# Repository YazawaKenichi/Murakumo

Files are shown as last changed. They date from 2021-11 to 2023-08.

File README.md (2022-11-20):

# Murakumo

```
* 8b    d8 88   88 88""Yb    db    88  dP 88   88 8b    d8  dP"Yb             Yb    dP 888888 *
* 88b  d88 88   88 88__dP   dPYb   88odP  88   88 88b  d88 dP   Yb             Yb  dP  88oo." *
* 88YbdP88 Y8   8P 88"Yb   dP__Yb  88"Yb  Y8   8P 88YbdP88 Yb   dP              YbdP      `8b *
* 88 YY 88 `YbodP' 88  Yb dP""""Yb 88  Yb `YbodP' 88 YY 88  YbodP  oooooooooo    YP    8888P' *
```

Yazawa の初めてのロボトレの情報を置いておくリポジトリ。
##### Excel フォルダ
機体の仕様決定

##### Inventor フォルダ
具体的な機体のグラフィック

##### Circuit フォルダ
KiCAD データとガーバーデータ

##### Program フォルダ（未作成）
実行プログラムや試行錯誤したプログラム

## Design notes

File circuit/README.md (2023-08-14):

回路設計時のノート

いろいろ悩みそうなところだけど、どこから悩めばいいのかもわからなかったので、まずはモータドライバ回路から設計しようと思う。

モータドライバ設計の前に、H ブリッジを駆動するためのゲートドライバ選びについて記述する。
##### ゲートドライバ
まず、ゲートドライバに必要な要素は以下の通り。
- Nch フルブリッジ回路を組むことができるか？
- 100% duty で出力できるか？
ということらしい。

PWM 周波数の話。
PWM 周波数は小さすぎるとトルクが足りなくなり、大きすぎるとモータによるサージの影響を受けやすくなる。よって適度な周波数に決める必要がある。

###### Nch フルブリッジ回路
Nch フルブリッジ回路を組むことの利点は以下。
- Pch は Nch に比べて性能が低い。
- Pch は品種があまりない。
- パワー素子は一種類のみで済ませて手間を省きたい。（Pch か Nch にそろえて同じ素子を使って製作できるようにしたい。）
- Pch は値段が高い。
上記理由を先輩に教えていただいたが、教えていただいた後にネットを探したところ、同様の記述を発見した。[参考](http://blog.livedoor.jp/wata_net/archives/2147292.html)。
[こっちのサイト](https://qiita.com/panzakii/items/97eca16954d34ecf0c8b)には「なぜフルNchにこだわるかというと、単純にその方が流せる電流が大きくなるからです。実はPchFETはNchFETに比べ流せる電流が少ないのです。原理について説明しだすと本当にキリがないので説明しません。興味のある人はググってください。」などと記述されているが、ググってもそんな記述は一切出てこない。なんなんだ。

「品種が多いから Pch よりも大電流の流せる Nch MOSFET」ならわかるが、「原理」とか「説明しだすとキリがない」とか記述されているのは本当に意味が分からない。

###### 100% duty で出力
- 最大出力で出せたほうが良いにきまっとるやろ！

二つのメリットをカバーできて、より入手しやすい IC が A3921 だそうで、それが理由でよく利用される。

##### モータドライバ
ゲートドライバが決まったところで、次に使用する FET とそれにつながる制限抵抗やコンデンサの値を決める必要がある。
特にこの抵抗とコンデンサは真剣に決めないとショートしてリポが死ぬ。マジで。
モータに入る電流は最大でも 4.34A なので、この許容電流に耐えうるケーブルは AWG22 になる。（AWG23 がいい感じに 4.7A の許容電流なのだが、9号館にないのでしょうがない。）
この AWG23 を圧着できるコネクタが XA コネクタなので、モータの電流が通るところのコネクタはすべて XA にしようと思う。
電源コネクタと電源回路をモータドライバ回路の方に設置することで、わざわざマイコン側から電力をモータドライバ回路に送る必要を無くす。

***書き途中***

DRV8874 のデータシートを読んで得た情報
- CPH CPL 間に 22nF のコンデンサ
- nFault は故障で LOW nSleep は LOW でスリープ => nFault と nSleep を直結すると故障と同時にスリープに入る。
- nFault には外部プルアップが必要。

SR ピンは 1 にすると FET 経由で回生する

SR ピンを 0 にするとダイオード経由で回生する

Figure 2: Fast Decay Power Bridge Current Paths が一番創造に近いモータドライバの制御に近い

PWMH PWML には常に 1 を入れて、PHASE に 

##### CPU
先輩が STM32F405RGT6 を束買いしているので、とりあえずこれにするのはアリ。
クロック数とメモリと機能的に、ロボトレにいい塩梅で使えそうなのがこの CPU らしい。

***書き途中***

##### 電源回路
この電源回路を決めるのにレギュレータを選ぶ必要があるのだが、レギュレータの出力が決まらない以上は手の付けようがない。だからさっさとほかの回路作れ。電源選びは最後だ。
=======
回路設計時のノート

いろいろ悩みそうなところだけど、どこから悩めばいいのかもわからなかったので、まずはモータドライバ回路から設計しようと思う。

使いたいモータがある -> 必要な電流量に耐える FET -> それを駆動できるゲートドライバを探す<br>
使いたいセンサがある -> 

モータドライバ設計の前に、H ブリッジを駆動するためのゲートドライバ選びについて記述する。
##### ゲートドライバ
まず、ゲートドライバに必要な要素は以下の通り。
- Nch フルブリッジ回路を組むことができるか？
- 100% duty で出力できるか？
ということらしい。

###### Nch フルブリッジ回路
Nch フルブリッジ回路を組むことの利点は以下。
- Pch は Nch に比べて性能が低い。
- Pch は品種があまりない。
- パワー素子は一種類のみで済ませて手間を省きたい。（Pch か Nch にそろえて同じ素子を使って製作できるようにしたい。）
- Pch は値段が高い。
上記理由を先輩に教えていただいたが、教えていただいた後にネットを探したところ、同様の記述を発見した。[参考](http://blog.livedoor.jp/wata_net/archives/2147292.html)。
[こっちのサイト](https://qiita.com/panzakii/items/97eca16954d34ecf0c8b)には「なぜフルNchにこだわるかというと、単純にその方が流せる電流が大きくなるからです。実はPchFETはNchFETに比べ流せる電流が少ないのです。原理について説明しだすと本当にキリがないので説明しません。興味のある人はググってください。」などと記述されているが、ググってもそんな記述は一切出てこない。なんなんだ。

「品種が多いから Pch よりも大電流の流せる Nch MOSFET」ならわかるが、「原理」とか「説明しだすとキリがない」とか記述されているのは本当に意味が分からない。

###### 100% duty で出力
- 最大出力で出せたほうが良いにきまっとるやろ！
100% duty で出せるかどうかってどうやって決まるんだろう...

二つのメリットをカバーできて、より入手しやすい IC が A3921 だそうで、それが理由でよく利用される。
A3921 の仕様
ゲート電圧は基準電位から +15V 以内の範囲が出力される様子。具体的には、ハイサイド出力が SA の電位よりも 0 ~ 15V 高くなり、ローサイド出力が GND 電位よりも -5 ~ 16V 高くなるように出力される。

A3921 のデータシートを読んで得た情報
- GHA and GHB Pins
- ゲート抵抗はできるだけ FET に近いところに置く必要がある。（なんでや）
- ＞ そもそもゲート抵抗をつける理由として
- ＞＞ FET 内部のコンデンサ成分と、導線自体によるインダクタンス成分が共振し、それに影響して FET やマイコンが破損する恐れがある。
- ＞＞ ドレイン電圧の立ち上がりと立下りが早すぎてノイズへの影響が大きくなる。
- ＞＞ ゲート電流が大きすぎて FET 前段の制御回路が破損する。
- ＞ この中で FET と抵抗の距離と関係がありそうな理由としては「導線自体のインダクタンス」だろう。抵抗からFETまでの導線の長さを小さくする、すなわちインダクタンスを小さくすることでノイズを軽減するといったところか。
- いまいちよくわからないところが、「GHx going low turns on the lower half of the drive, sinking current from the external FET gate circuit to the corresponding Sx pin, turning off the FET.」の一文で、GHx を Low にしたらドライブの下半分が ON になる？ってどういうことだ？
- Bootstrap Capacitor Selection
- ブートストラップコンデンサ CBOOTx は、正しく選択する必要がある。
- コンデンサの静電容量が大きいと、コンデンサの充電に時間が浪費され、結果として最大デューティーサイクルと PWM 周波数の制限が小さくなってしまう。
- 逆に小さいと、Charge Sharing によって、電荷が CBOOTx から FET ゲートに転送されるときに大きな電圧降下が発生する可能性があるらしい。
- ＞ Charge Sharing ってなんだ？
- ＞＞ 英語版 Wiki によると、Charge Sharing は、ある電子ドメインからほかの電子ドメインへの電荷の移動による信号劣化の影響。らしい。は？
- ＞ よくわからないけど、とにかく電荷を共有して、出力電圧レベルが退化したり、誤った出力値が発生したりする可能性があるっぽい。
- この電圧降下を小さくするために、CBOOTx の電荷 QBOOT は、FET のゲート QGATE に必要な電荷よりもはるかに大きくする必要がある。その"はるかに大きい"というのは、20 倍だそうだ。
- QBOOT というのは、CBOOTx に蓄えられる電気量なので、CBOOT * VBOOT で求めることができる。そして上記より、これは QGATE の 20 である必要があるので、ブートストラップに接続するコンデンサの、適切な電気容量 CBOOT を求める式は、以下のようになる。
[](url)- CBOOT = QGATE * 20 / VBOOT
- 係数 20 を選択した場合、FET が ON の時の VBOOT と OFF の時の VBOOT の差は約 5% だそう。通常動作条件下での VBOOT の最大電圧は VREG らしい。
- ＞ VREG の値について。。。疑問がある。
- ＞＞ Terminal List には Regulated 13V と説明があるのに、
- VBB 電源が 16V より大きいとき、レギュレータは単純なリニアレギュレータとなる。16V 未満では、安定したレギュレートをするために、ポンプコンデンサ CP が必要。
- このコンデンサ CP の最小値は 220nF である必要があり、通常は 470nF を接続する。
- 安定してレギュレートされた 13V は VREG 端子で使用できる。ローサイドドライブとブートストラップコンデンサに過渡充電電流を供給するために十分大きなストレージコンデンサを接続する必要がある。
参考になったサイト
- ハイサイド Nch MOSFET の話やブートストラップ回りについては[このサイト](https://techweb.rohm.co.jp/knowledge/dcdc/dcdc_sr/dcdc_sr01/829)が参考になった。

###### duty rate
[このサイト](https://sgrsn1711.hatenablog.com/entry/2019/04/29/152425)が参考になった。<br>
PWM 制御は PWM パルス波を用いて電圧を制御する方法。しかし **『PWM のデューティー比を線形に動かしても電圧は線形』にならない。** <br>
具体的な式は (実効値) = (最大瞬時値) * √(デューティー比)<br>
最大瞬時値：パルス波が HIGH の時の電圧<br>
デューティー比：そのままの意味（但し 0 以上 1 以下）<br>
実効値：PWM の電圧・電流をこれと同じ働きをする直流の電圧・電流の大きさに置き換えて表した値<br>
両辺を二乗して両辺を (モータの抵抗) で割ると<br>
(実効電圧) / (モータの抵抗) = (デューティー比) * (最大瞬時電圧) / (モータの抵抗)<br>
すなわち<br>
(実効電力) = (デューティー比) * (ドライバの電力)<br>
となり、**(デューティー比) は 電力 の比例定数となっている**ことがわかる。<br>
<br>
[このサイト](https://detail-infomation.com/gate-driver-type/)によると、ターンオンを速くする回路よりもターンオフを速くする回路の方が頻繁に用いられるらしい。たしかに、4月に制作したミニトレーサ回路も、ターンオフが速くなる方向にダイオードが設けられていた。ターンオフ抵抗が小さいので、MOSFET のミラー容量を介して誤ターンオンを防ぐことができるようだ。

##### モータドライバ
ゲートドライバが決まったところで、次に使用する FET とそれにつながる制限抵抗やコンデンサの値を決める必要がある。
特にこの抵抗とコンデンサは真剣に決めないとショートしてリポが死ぬ。マジで。

参考までに先輩のデータを置いておく。
DRV8874 (野村先輩)
DRV8873 + INA260 (井口先輩青機体)
DRV8701 + AON7xxx (井口先輩紫機体)
A3921 + IRF8915 (下鳥先輩 VCM 機体)

H ブリッジが組める IC を Digi-Key で探したが、どうやら今は在庫切れっぽい。は？どうすりゃいいの？
- パターン１：ほかのサイトでも探してみる
- パターン２：H ブリッジを自作する
- パターン３：何？

Digi-Key で在庫を無視して H ブリッジを絞り込んで、当然というか、上記の通り在庫がないので Mouser で検索していく。
- [L9958](https://www.mouser.jp/ProductDetail/STMicroelectronics/L9958?qs=mxm%2FV7p14IPZ8VUmCRyJ0Q%3D%3D) が良さそう。電圧と必要な電流で絞り込んだら L9958 うんたら～みたいなのがたくさん出てきたが、データシートは同じものだったので、データシートを読む分にはどれを選んでも大丈夫そう。電流制限機能があり、CL ピンに設定する H/L でその閾値を決めているようだ。実際に通す電流は 5A 行かないくらいなので、制限 8A で十分である。L9958 うんたら～を絞るのはどうすればよいのだろう... 何が違うのかをデータシートから読む必要がありそう。また、消費電力を計算してこの IC で良いかも吟味した方がよい。

Digi-Key で H ブリッジを検索してそれを別のショップで調べてみる。そうすればほしい IC が Digi-Key の在庫に左右されずに使用できる。
試しに H ブリッジを Digi-Key で用途とパッケージで絞り込んで調べたところ、[このような一覧](https://docs.google.com/spreadsheets/d/1YwifbfS08Ro-1kxqgMN1l2ujk6fK_v7bKf-RipdZybw/edit?usp=sharing)が吐き出された。
- DRV8874 (野村先輩が使用している IC と同じもの)
- DRV8848
- DRV8220
さらに、このうち欲しい電流が吐き出せるのが [DRV8874 (野村先輩と同じ IC)] が選出される。<br>
ただ、この DRV8874 なのだが、Digi-Key, Mouser, RS Components, Akizuki, Marutsu のどれで調べても在庫切れ。もうダメじゃん...<br>
野村先輩の在庫と、評価ボードからパクればヨシッ！<br>

QFP と QFN
QFP はよく見る足が外に出たパッケージ、QFN は足が出てないパッケージ。リフローでしかつけられない奴が QFN 一応 9 号館でリフローできるらしい。
QFN にすればサイズ縮小できるし、条件に合った IC も見つかりやすいから良いんだけど、リフローする IC は一気にリフローする必要があるから、燃えたところだけ直すとかそういうことがやりにくい。
初めてなんだから回路は修正しやすいほうが良い。絶対 QFP がいいやろ。

DRV8874 データシート 7.3.1 に推奨抵抗値が書いてある。
IPROPI に発生する電流は以下の式で与えられる。
Iipropi = (ILS1 + ILS2) * Aipropi
ILS はローサイド FET のドレイン電流。Aipropi は比例定数。おおよそ 450uA/A とされている。
モータを通す最大電流は 4.34A なので、最大の Iipropi は 1.953mA となる。ここに抵抗と ADC を繋ぐことでマイコンで処理することができるようになる。（抵抗が電流を電圧に変換するための抵抗になる。）
***途中略***
Vref の抵抗値は 33k, 33k で良い気がしてきた。（合計 66k ohm になるように選定。）結局 Itrip の値は Ripropi の値で決めればいいと思う。

###### Power MOSFET<br>
FET の耐圧（D-S 間電圧）と流したいドレイン電流（ID 電流）で大体の規格が絞れる。<br>
そこから、[ON 抵抗](https://www.rohm.co.jp/electronics-basics/transistors/tr_what9)と[スイッチング速度]()から、損失の大きさを計算してそれに耐えるものを選ぶ。<br>
DCX 10L 公称 4.5V の起動電流 1.55A で、これに 12V をかける。その時の電流値を考えて使う必要がある。<br>
- 別ディレクトリの Excel データによると ID = 3.06A (2S (8.9V)), 4.34A (3S (12.6V)) であることが算出された。3S 使うことも考えて、4.34A に耐えるものを選ぶようにすればよさそう。<br>
ついでに、配線幅については、右モータと左モータでひとつづつ使うことも考慮して設計する必要がある。よって上記条件によって 4.34mm 以上の配線幅となっていればよいことになる。<br>
- ON 抵抗については、パッケージが小さい方が ON 抵抗が大きく、パッケージが小さいと ON 抵抗が大きくなる。<br>
- 今回作る基板はサイズが比較的大きく、パッケージの違いによる大きさの違いは考慮しなくて良いと思う。よって ON 抵抗のより小さいものを選んでおけば良い。<br>
- [スイッチング速度についてはこのサイトが強そう](https://xtech.nikkei.com/atcl/learning/lecture/19/00080/00002/)<br>
digikey で以下の条件で絞り込んだ<br>
- Nch フルブリッジを内蔵したトランジスタアレイ IC<br>
- 部品状況：アクティブ<br>
- FET タイプ：N チャンネル 4 個 (H ブリッジ)<br>
- Vdss：24V 以上 (上条件適応後だと 30V 以上)<br>
- Id：9A 以上 (上条件適応後だと 13A 以上)<br>
- 取り付けタイプ：面実装<br>
以上の条件だとただ一つ [DMHT3006LFJ](https://www.diodes.com/assets/Datasheets/DMHT3006LFJ.pdf) のみに絞られた。<br>
トランジスタシングルの場合で絞り込んでみたい。<br>
FET で H ブリッジを組むことを考えてみる。<br>
絞り込み条件<br>
- Transistor - FET, MOSFET - Array<br>
- 部品状況 : Active<br>
- FET type : 2Nch (dual) | Nch \*2 (Half Bridge)<br>
- FET method : Logic Level Gate<br>
まずは上記で絞り込み、下記を追加<br>
- Vdss : 20V (大きすぎるとオン抵抗が大きくなる傾向がある。）<br>
- Id : 5A | 20A | 40A<br>
次に以上で絞り込み、「オン抵抗は小さいと電力が小さく済む」「ゲート電荷が小さいほうがスイッチング時のロスが減る（高速スイッチングができる）」「オン抵抗とゲート電荷はトレードオフ」という知識を以って、下記をさらに追加<br>
- <br>
モータの PWM 制御において「高速スイッチングができる」というのは大したメリットではないような気がした。なので「オン抵抗かゲート電荷か」については「オン抵抗」の方を取ることにする。<br>
因みに「チップサイズが大きい => オン抵抗が小さい => ゲート電荷が大きい」と、チップサイズとも関係がある様子。ただシャーシ基板だし、サイズはまだ考慮しなくていい気がする。<br>
「MOSFET の寄生容量・入力容量・出力容量・帰還容量 の関係」で一つ記事が書けるくらいの内容がある。（俺が俺に向けて知っておいてほしいことの一つ）<br>
このうちの 入力容量 が ゲート電荷 と直接的に関係があるもの。よって、ゲート電荷の大小を考えることは入力容量の大小を考えることと同じである。<br>
MOUSER で FET を調べてみる。<br>
- MOSFET SMD/SMT N-Channel MOSFET
- Rds On で昇順ソートして 2 ページまで CSV で吐き出す。
- Rds On が一番小さいのが [PSMN1R5-30BLEJ](https://www.mouser.jp/ProductDetail/Nexperia/PSMN1R5-30BLEJ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) だった。ただ在庫が 5 しかあらん。
- 次に小さいのが [PSMN1R5-25YL,115](https://www.mouser.jp/ProductDetail/Nexperia/PSMN1R5-25YL115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) になった。こっちは在庫が 50 くらいある。これで良いんじゃね？いったんこれで考えてみる。
- 

***書き途中***

##### ラインセンサ
- 野村先輩によると、アナログ値を返すセンサと、ディジタル値を返すセンサの二種類がある。
- 試しに digikey で調べてみようとしたところ、『光センサ - フォトインタラプタ - スロットタイプ - トランジスタ出力』『光センサ - フォトインタラプタ - スロットタイプ - ロジック出力』という分類があり、トランジスタ出力が一般的なアナログ値を返すフォトインタラプタで、ロジック出力が野村先輩が言っていたディジタル値を返すセンサなのだろう。
- 接続する抵抗によって閾値を変更する。
- [なんかいい感じのサイト見つけた](https://components.omron.com/jp-ja/products/basic-knowledge/sensors/photomicro-sensors/technology)
- [こっちはフォトセンサの設計についてのサイト](https://toshiba-semicon-storage.com/content/dam/toshiba-ss/jp/docs/design-support/elearning/elearning_discrete05_r51.pdf)
勝手な予想混じりではあるが、メリットとデメリットについて考えてみる。<br>
アナログ出力のメリット<br>
- 環境が変わってもプログラム上で閾値を変更すればいいだけ<br>
アナログ出力のデメリット<br>
- ソースコードが長くなる
- 処理が重い<br>
デジタル出力のメリット<br>
- プログラム上でソートしてセンサ値を決める必要はない<br>
デジタル出力のデメリット<br>
- 環境が変わると閾値が変わる可能性がある（ポテンショメータを用いて閾値可変にするのも手だが沢山あるセンサのすべてにそれを適応するのは手間すぎるし重くなるしかさばるし）<br>
上記より、コースセンサ取得にはアナログセンサを用いて、サイドセンサ取得にはデジタルセンサを用いるというのはどうだろうか？<br>
適材適所な選び方ができている気がする。（気がする）<br>
コースラインの読み取りに使用するアナログセンサは、9号館でよく使用されるセンサ [TEMT7100X01](https://jp.rs-online.com/web/p/phototransistors/7000767) を使用することにする。どうしてこのセンサを使用しているのだろうか？？？下鳥先輩は「在庫が無くなったからノムさんに新しいの使ってもらってる（人柱）」とおっしゃっていた　が、「新しいセンサを使うことに対する抵抗がある」というのは、外乱の影響度とか、ロボトレとしての使用に向いているからとかそういう要件を満たしているからなのだろうか？
それと、わざわざメディアンフィルタしてラインを読むより、デジタルで値を出してくれた方がよいのではないか？という疑問に対して、「PID 制御を用いて車体を左右に振ることを考えたら、二値を取るよりも、もっと分解能の高いアナログセンサにした方がより滑らかに PID 制御してくれるゾ。」ということを教わった。
ただやはり、デジタルはノイズに強く、アナログはノイズに弱いらしい。そのノイズ対策のために、メディアムフィルタを使っている。
制御方法は二つ
- センサを右にあるやつと左にあるやつに分割して、左右それぞれの和で PID 制御する方法。
- 白を読み取っているセンサの角度からモータの出力をする方法。（ステアリング切らない限り、実はムズイらしい。）

サイドセンサの話。
S7136 の Cathode がデューティー比 1/16 の点滅、データシートの推奨電力的に Vf 1.3V, If 20mA の実効値を出せるように計算すると抵抗値は 65Ohm になる。ただこの抵抗の抵抗の両端の電位差は 5.2V になってしまうので電源は 5.5V で引き出す必要がある。

##### IMU
まずは先輩方が使用している ICM-20648 を使用することにしてみる。
データシート用語
- ODR:Output Data Rate の略で、データを出力する周波数のこと。
I2C と SPI の違いとそれぞれの特徴。
いずれも同期式シリアル通信
SPI:SIMO SOMI SCLK SSn の四つ以上のピンでスレーヴを制御する。デバイスの数に応じて SS ピン（Slave Select ピン）が増えていくのでより多くのピンが必要になってしまう。
I2C:SDA SCL の二本線のみで制御することが可能だが、一般的に速度は SPI に劣ってしまう。プルアップ抵抗値 数百～数キロ Ω が必須。
速度の話をされてしまうと SPI でいいと思える。

##### UI
電子ブザーを付けたい。「電子ブザー」はアナログな電圧を印加することで音階を変化させることが可能。これは PWM 信号を用いて実効的に再現することができる。具体的には duty 比を変化させる。根拠は[ここ](https://smtengkapi.com/engineer-picbuzzer#toc4)。「圧電ブザー」の方も PWM で音階制御ができるが、周波数を変更する必要がある。ただそれだと Timer 全体の周波数が変更されてしまうから良くない。
左右旋回表示 LED
左右サブセンサデバッグ LED
導通 LED
リセット LED

操作系については、まず「何を操作したいのか」について考える。
- キャリブレーション（白と黒の色を確認）したい
- スタートボタンが欲しい
- ストップは自動で検出するようにすればいいのでストップボタンは必要ない
- 記憶したコースを走れるように、何回目のコース記録を引き出すか指定できるようにしたい。

操作スイッチ系チャタリング対策に、0.1uF + 15kOhm のローパスフィルタを通すことにした。チャタリング周波数から 0.1uF のコンデンサが決まり、チャタリング時間から必要な時定数にメドを付けて抵抗値を決める。尚、復習として、RC 秒経った時の実効値は、最大値のおおよそ 63% となっている。チャタリングの周波数は 50MHz で、チャタリング継続時間は最大 1ms として計算。

ブザーの話。
電流 90mA 必要。FET で駆動したい。
FET の抵抗はぶっちゃけテキトーで良い気がする。
ゲート抵抗は「立ち上がり時間」に影響する。ブザーの駆動くらいなら立ち上がり時間がエグくても大丈夫でしょ。FET は使い慣れてる 2N7002 でいいと思う。
ブザーに並列するダイオードは逆電圧で耐えるもののうち、逆回復時間が短く、リーク電流が小さいものを選んだ。

##### CPU
先輩が STM32F405RGT6 を束買いしているので、とりあえずこれにするのはアリ。
クロック数とメモリと機能的に、ロボトレにいい塩梅で使えそうなのがこの CPU らしい。
SD カードを載せるか載せないかでマイコンを選択しているらしい。（野村先輩情報）
SD カードを載せたいのであれば STM32F446 で、内部フラッシュが使いたいならば STM32F405 を使うようだ。ちなみに、下鳥先輩からもらったマイコンボードは Nucleo-F446RE
446 は周波数が高く処理が速い。SD カードに書き込むことも可能だが、RAM がそこまで大きいわけじゃないので（小さすぎるわけでもない）、SD カードに書き込める本質的な量はそこまで大きくないことになる。
だったらフラッシュ使って 405 に記憶してしまっても良いんじゃない？
「デバッグのしやすさ、書き込みのしやすさ」という話については、ただ単純に「やり方」の問題で、
デバッガピンには SH コネクタを使うと、基板をより小さくできる。

データシートから得た情報
VREF+ と VDDA が接続されているかいないかによって VDDA 周りの回路が変わる。VREF+ と VDDA が接続されていないパターンとしては UFBGA176, LQFP100, LQFP144, LQFP176 を用いる場合。今回は LQFP64 を用いているので、VREF+ と VDDA が IC 内部で接続されている。なので、それに対応するコンデンサ接続をする。
OSC_IN 4Hz ~ 26MHz 周波数インプット。
2.2.13 BOOT ピンでブート方法を指定することができる。
具体的には、
- ユーザフラッシュからの起動
- システムメモリからの起動
- 組み込み SRAM からの起動

***書き途中***

##### 電源回路
この電源回路を決めるのにレギュレータを選ぶ必要があるのだが、レギュレータの出力が決まらない以上は手の付けようがない。だからさっさとほかの回路作れ。電源選びは最後だ。

##### バッテリ
バッテリについて新たな知見を得たので記録しておく。気になったことは「結局バッテリは何 A まで流せるの？」ということで、いろいろ考えたり、ググったりしたところ、バッテリの容量（以下理論容量） Ah とは別に、C レートというものがあるようだ。C レートというのは、バッテリの理論容量を 1 / 何 時間で完全に放電するかという数値。例えば、2Ah の理論容量で、C レートが 1C と決められた場合は、2A を 1 / 1 時間で完全放電することができるというもの。2C の場合は 2A を 1 / 2 時間すなわち 30 分で放電しきることができるというもの。数式として扱うと、(最大放電電流 A) = (理論容量 Ah) * (C レート /h) で「結局バッテリに流せる電流」が求まる。<br>
今のところ機体に載せようと思っているバッテリは [Hyperion G5 SV 2S / 7.4V 50C 25~30C 240mAh](https://hyperion-world.com/en/p2661623-hp-g550-0240s2) なので、(最大連続放電電流) = 25~30 * 0.240 = 6~7.2A (最大瞬間放電電流) = 50 * 0.240 = 12A となり、結局バッテリには 12A までなら流すことができるということになる。安定化電源で電流制限をかける時はこの値を参考にして電流制限をかけるとよい。<br>

##### 超忘れてた！エンコーダ！！！
[ENX 10 EASY](https://www.maxongroup.co.jp/medias/sys_master/root/8836894752798/enx-easy-en-Nov-11.pdf) データシートの P.17, P.24 あたりが有能。
Complement は「補集合」の意味。つまり否定。
インデックスは、「一回転」を判断するためのマーキング。使わないから正直未接続でいい。

[裕ちゃん](https://www.mouser.jp/ProductDetail/Texas-Instruments/LP38690DT-33-NOPB?qs=1FNqv8aZn1RDCTlgvtVtOw%3D%3D)

#### 現状決まっている部品を列挙していく
- メインセンサ : フォトトランジスタ [TEMT7100X01](https://jp.rs-online.com/web/p/phototransistors/7000767) 赤外線 LED [SIR19-21C/TR8](https://www.digikey.jp/ja/products/detail/everlight-electronics-co-ltd/SIR19-21C-TR8/2675916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)
- サブセンサ : [S7136](https://akizukidenshi.com/catalog/g/gI-02425/) 赤外線 LED [SIR19-21C/TR8 (メインセンサと同じ)](https://www.digikey.jp/ja/products/detail/everlight-electronics-co-ltd/SIR19-21C-TR8/2675916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)
- H ブリッジモータドライバ : [DRV8874PWPRCT](https://www.digikey.jp/ja/products/detail/texas-instruments/DRV8874PWPR/11502339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) 及び それを搭載した評価ボード [DRV8874EVM](https://www.digikey.jp/ja/products/detail/texas-instruments/DRV8874EVM/10416576)
- モータコネクタ XA
- マイコン : [STM32F405RGTx](https://www.st.com/resource/en/datasheet/dm00037051.pdf)
- コントローラ : [ロータリコードスイッチ](https://www.mouser.jp/ProductDetail/CTS-Electronic-Components/220AMB16R?qs=DRP5hA1CHApmGlVxOtUknA%3D%3D)もし在庫なくなっちゃったら[こっち](https://www.mouser.jp/ProductDetail/CTS-Electronic-Components/220AMA16R?qs=xRR2c4tI8%252BMRurGPbsuWKA%3D%3D)
- スイッチ : ただのプッシュスイッチくらいを回路に書くなら、まだ push switch 表記でいい気がする。
- ブザー : [TE044003-4](https://www.digikey.jp/ja/products/detail/db-unlimited/TE044003-4/13541886) データシートがないからどうやって使うのか全く分からんけど作ってから知ればいい！脳筋！トランスデューサ式なので、ダイオードを並列接続して逆起電力を逃がす。圧電トランスデューサとか出てきたからもしかしたら圧電ブザー。PWM 周波数を変えて音色を変える必要が出てきそう。
- 発振器 : [ASTMLPA-16.000MHZ-LJ-E-T](https://www.digikey.jp/ja/products/detail/abracon-llc/ASTMLPA-16-000MHZ-LJ-E-T/5425114)
- レギュレータ(5.0V) : [NCV7805BD2TG](https://www.digikey.jp/ja/products/detail/onsemi/NCV7805BD2TG/1484134)
- レギュレータ(3.3V) : [S-19246E33H-V5T2U](https://www.digikey.jp/ja/products/detail/ablic-u-s-a-inc/S-19246E33H-V5T2U/13182985)
- LED : [フルカラー LED APTF1616LSEEZGKQBKC](https://www.digikey.jp/ja/products/detail/kingbright/APTF1616LSEEZGKQBKC/5803664) [白 LED SMLEN3WBC8W1](https://www.digikey.jp/ja/products/detail/rohm-semiconductor/SMLEN3WBC8W1/9448213) [赤 LED SML-311UTT86](https://www.digikey.jp/ja/products/detail/rohm-semiconductor/SML-311UTT86/637032)
- ブザー駆動 FET : [2N7002T](https://www.digikey.jp/ja/products/detail/onsemi/2N7002T/1830658) ブザー用ダイオード : [RB751S40-AU_R1_000A1](https://www.digikey.jp/ja/products/detail/panjit-international-inc/RB751S40-AU-R1-000A1/14660575)
- スライドスイッチ : [SSAJ120100](https://akizukidenshi.com/catalog/g/gP-13989/) [Pch MOSFET CXDM4060P TR PBFREE](https://www.digikey.jp/ja/products/detail/central-semiconductor-corp/CXDM4060P-TR-PBFREE/4807590)

タスク
- [x] CPU STM32H7 シリーズにしない理由を聞いてみる。裕ちゃんにマイコン選びを教えてもらう。在庫の関係上 446 か 405 になることは確定。
- [x] IMU ICM-20648 でいいと思うが、そもそも在庫があるのか確認する。QFPN パッケージしかヒットしないが、先輩たちはどうやってこの IC を基板に載せているのか見る。データシートを読んで理解してみようとする。> 基板に直でついてるんだけど、どうなってんの？？？リフローっぽい？
- [x] UI どんな操作ができるといいか先輩に聞く。
- [x] Conn どんなコネクタがあるのか 9 号館を見る。
- [x] Inventor の編集。基板二階建てにする。それにあたって下鳥先輩の VCM マシンを参考にバッテリの引き回しを見る。
- [x] ロータリスイッチにデバウンスやプルアップ抵抗は必要ないのか？ > フィルタ回路があればプログラム上で読み飛ばす必要はない。
- [ ] PA2 ~ 5 を無効にして左右の取得値からモータを制御する。
- [ ] そのために PA2 ~ 5 を切り捨てて左右の値を足し算するプログラムの作成。
- [ ] そのために PWM 制御するピンにタイマを割り当てる。

KiCAD 設計中のメモ
VDC は 1.8 ~ 3.3V
F405 の VCAP にある 2.2uF コンデンサは、電圧レギュレータをバイパスするときには不要で、二つの 100nF デカップリングコンデンサに交換する必要がある。ソースはデータシート 5.3.2 Figure 23. External capacitor CEXT の注意書きに記述されている。
CPU の VDD は 1.8 ~ 3.6V
CPU の VBAT は 1.65 ~ 3.6V
CPU の VDDA, VSSA は 1.8 ~ 3.6V 
FB の値は実際に作ってから決める。PWM 周波数とかどのくらいになるかわからんし、ぶっちゃけ無くてもいいような気がするから、0Ohm 抵抗を接続できるパッケージのインダクタを選ぶ。

メモ書き
IN0, 7, 8, 11 // 今後使うかわからんけど一応記述しておく。

以下オフラインコミットメッセージ

2022/03/27 21:10
SW3 を追加
LED_R, G, B を追加
TIM6 を追加
SW3 を押すことで UART の出力をループしたりしなかったりするようにした。
ループするかしないかによって FullColorLED の色が変化するようにした。
SW3 の Read は TIM6 を使って、while 中でも loopflg が変化するようにした。
まだプログラム上で作っただけなので、実機で試しておらず、本当にこのプログラムで動くのかは不明。
又、TIM6 の Configrations はデフォルトのまま（NIVC のみ Enable に変更済み）なので実装する前に改めて TIM6 の設定を見直すことを勧める。

2022/03/29 **:**
DRV1/2_PH/EN を追加。
TIM4, TIM6, TIM7 を追加し、割り込み周期の調整。

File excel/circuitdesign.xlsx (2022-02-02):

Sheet: DRV8874
RIPROPI | AIPROPI | VCC | RREFH | RREFL | RREFsum | VREF | ITRIP
5.5 | 450 | 3.3 | 16 | 50 | 66 | 2.5 | 1.01010101
1.2 | 450 | 3.3 | 16 | 50 | 66 | 2.5 | 4.62962963
0.82 | 450 | 3.3 | 33 | 33 | 66 | 1.65 | 4.471544715
1.6897 | 450 | 3.3 | 0 | 66 | 66 | 3.3 | 4.340020911
5.5 | 450 | 3.3 | 33 | 33 | 66 | 1.65 | 0.6666666667
5.5 | 450 | 3.3 | 33 | 33 | 66 | 1.65 | 0.6666666667
5.5 | 450 | 3.3 | 33 | 33 | 66 | 1.65 | 0.6666666667

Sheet: FET
 |  | Gate Resistans |  |  |  |  |  |  | Gate to Source Resistance
parts | Adjusted | t (us) 立ち上がり時間 | Qg (nC) | V_th (V) | V_IN (V) ノイズ電圧 | In (uA) | I_G (mA) | R_G (Ohm) | 以上 | 以上 | 以上 | 以下 | 最小 | 最大
SPB42N03S2L-13 |  | 6.50 | 22.90 | 1.60 | 3.30 | 5.00 | 3.52 | 936.68 | 9366.81 | 936.68 | 995.22 | 320000.00 | 9366.81 | 320000.00
SPB42N03S2L-13 | 1000.00 | 6.50 | 22.90 | 1.60 | 3.30 | 5.00 | 3.52 | 1000.00 | 10000.00 | 936.68 | 1062.50 | 320000.00 | 10000.00 | 320000.00
 | 100 | 2 | 30 | 1.60 | 12 | 5.00 | 15 | 100.00 | 1000.00 | 800.00 | 650.00 | 320000.00 | 1000.00 | 320000.00
 |  | 2 | 30 | 1.60 | 12 | 5.00 | 15 | 800.00 | 8000.00 | 800.00 | 5200.00 | 320000.00 | 8000.00 | 320000.00
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

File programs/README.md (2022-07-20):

## プログラムの思考

### サイドセンサを実装したい。

#### 要件<br>
左を見たら曲率変化として扱う。<br>
右を見たら止まる。<br>
四月の目標としては「右を見て止まる」実装できればいい。<br>
但し、交差で誤作動を起こさないように左右のセンサを正しく動作させる必要がある。<br>
<br>
白読みを 1, 黒読みを 0 とし、左右合わせて 2bit 保存。<br>
最大でも 2bit * 3patern あれば状態を把握できるので 6bit 使用する。<br>
uint16_t 型で保存しても上位 2bit が余る。何かに使えないかなぁ...<br>
<br>
```
uint8_t 型の値を abcd efgh とする。
abcd efgh == 0 の時
  gh の値を更新していく
abcd efgh != 0 の時
  ef != gh // 初期状態と次の状態が違う時
    ef の値を更新していく
    ef == 00 の時
      gh == 01 の時
        ef = 01
      gh == 10 の時
        ef = 10
      gh == 11
        abcd efgh = 0
  または ef == gh // 初期状態と次の状態が同じとき
    何もしない
```
こんなプログラムできたらかっこいいかも...<br>
でも失敗しそうな気がするし、考えにくいから一旦もっと簡単な方法でプログラムしたい。<br>
<br>
<br>
左右の状態を常に格納している変数と、前回の値を保存している変数と、変化が起こった時にその変化の順番を記憶しておく変数の三つを用意するともっと簡単になりそう。（賢くはないけど）<br>
```
char sidesens, sidesensbuf, sidemarker
timer_0.1ms()
{
  sidesens = !(右センサの状態) 1 : 0;
  sidesens += !(左センサの状態) 2 : 0;
}
timer_1ms()
{
  if(sidesensbuf != sidesens)
  {
    // 前回と違う時
    sidemarker += 2 << sidesens;
  }
  sidesensbuf = sidesens;

  if(sidemarker & 0b11)
  {
    if((sidemarker & 0b1100 == 0b1100) || (sidemarker & 0b0011 == 0b0011))
    {
      交差
    }
    else if(sidemarker & 0b11 == 0b01)
    {
      右読み
    }
    else if(sidemarker & 0b11 == 0b10)
    {
      左読み
    }
  }
  else
  {
    // 異常
  }
}
```
<br>
コメントを正しい処理に置き換えることをしてみる。<br>

```
char sidesens, sidesensbuf, sidemarker
timer_0.1ms()
{
  sidesens = !(HAL_GPIO_ReadPin(GPIOB, GPIO_PIN_2) 1 : 0;
  sidesens += !(HAL_GPIO_ReadPin(GPIOB, GPIO_PIN_11) 2 : 0;
}
timer_1ms()
{
  if(sidesensbuf != sidesens)
  {
    // 前回と違う時
    if(sidemarker == 0)
    {
      // サイドマーカがゼロのままなら
      sidemarker = sidesens;
      // 下位二ビットに現在の状態を保管
    }
    else
    {
      // サイドマーカがゼロじゃないとき
      sidemarker += 2 << sidesens;
      // 上位二ビットに次の状態を保管
      sidemarker += 0b10000;  // チェンジビットを立てる
    }
    // 
  }
  sidesensbuf = sidesens;

  if(sidemarker & 0b11 && sidemarker & 0b10000) // チェンジビットが立ってる時
  {
    if((sidemarker & 0b1100 == 0b1100) || (sidemarker & 0b0011 == 0b0011))
    {
      // 交差
      /*
        ここの分岐に入る状態リスト
        sidemarker
        0b0011
        0b0111
        0b1011
        0b1100
        0b1101
        0b1110
        0b1111  // 上位二ビットと下位二ビットで変化がないので本当はこれもここに来れない。
      */
    }
    else if(sidemarker & 0b11 == 0b01)
    {
      motorenable = 0;
      /*
        ここの分岐に入る状態リスト
        sidemarker
        0b0001
        0b0101  // 上位二ビットと下位二ビットで変化がないので本当はこれもここに来れない。
        0b1001  // 現実問題これはありえない
      */
    }
    else if(sidemarker & 0b11 == 0b10)
    {
      // 左読み
      // 加減速走行
      /*
        ここの分岐に入る状態リスト
        sidemarkder
        0b0010
        0b0110  // 現実問題これはありえない
        0b1010  // 上位二ビットと下位二ビットで変化がないので本当はこれもここに来れない。
      */
    }
      sidemarker = 0; // サイドマーカを初期化する

  }
  else
  {
    // 両方黒読みしてる時の処理
  }
}
int main()
{
  sidesensbuf = 0;
  sidemarker = 0;
}
```
最終的にはこうなった。
```
		// SubSensor Controller
		subsensl = !HAL_GPIO_ReadPin(GPIOB, GPIO_PIN_11) ? 1 : 0;
		subsensr = !HAL_GPIO_ReadPin(GPIOB, GPIO_PIN_2) ? 1 : 0;

		// SubSensor Controller
		sidesens = !(HAL_GPIO_ReadPin(GPIOB, GPIO_PIN_2)) ? 1 : 0;
		sidesens += !(HAL_GPIO_ReadPin(GPIOB, GPIO_PIN_11)) ? 2 : 0;

		if(sidesensbuf != sidesens)
		{
			//
			if(sidesensbuf != sidesens)
			{
				if(sidemarker == 0)
				{
					sidemarker = sidesens;
				}
				else
				{
					sidemarker += 2 << sidesens;
					sidemarker += 0b10000;
				}
			}
		}

		if((sidemarker & 0b11) && (sidemarker & 0b10000))
		{
			if(((sidemarker & 0b1100) == 0b1100) || ((sidemarker & 0b0011) == 0b0011))
			{
				// cross
			}
			else if((sidemarker & 0b11) == 0b01)
			{
				motorenable = 0;
			}
			else if((sidemarker & 0b11) == 0b10)
			{
				// break accel
			}
			sidemarker = 0;
		}
		else
		{
			// black
		}
		sidesensbuf = sidesens;
```
うまく挙動しなかった。
左右のどちらかが白から黒・黒から白に変化することで値（sidemarker）が更新されることは確認した。

もっと別のプログラムを考えてみようと思う。
```
サイドセンサが変化した時
  何回目の変化なのかを記憶する。カウントをインクリメント。
  今の状態を格納する。カウントを使ってビットシフト。
  今の状態がゼロゼロの時。
    二番目のパターンを見る
      二番目のパターンがイチイチの時
        交差
      二番目のパターンがゼロゼロの時
        一番目のパターンを見る
          一番目のパターンがゼロイチの時
            右読み
          一番目のパターンがイチゼロの時
            左読み
      カウントを初期化する。
  今の状態がゼロゼロではないとき
    何回目の変化なのかを記録する。
```
```
subsens = 0;
subsens = !HAL_GPIO_ReadPin(GPIOB, GPIO_PIN_2) ? 1 : 0; // right
subsens += !HAL_GPIO_ReadPin(GPIOB, GPIO_PIN_11) ? 2 : 0; // left
buffer = 1;
if(subsens != subsensbuf)
{
  marker += subsens << (2 * changetime);
  if(subsens == 0b00)
  {
    char first = (subsens & 0b0011);
    char second = (subsens & 0b1100) >> 2;
    if(second == 0b11)
    {
      // cross
    }
    else if(second == 0b00)
    {
      if(first == 0b01)
      {
        // right
      }
      else if(first == 0b10)
      {
        // left
      }
    }
    count = 0;
    buffer = 0;
  }
  else
  {
    count++;
  }
}
if(buffer)
{
	subsensbuf = subsens;
}
```
### エンコーダを実装したい
#### できること<br>
カウントスタートしてからカウントストップするまでにカウントしたパルス数を読み取る。

#### 要件<br>
１パルスあたりに進む長さを計算する。（理論値）<br>
(１パルスあたりに進む距離) = (円周率) * (タイヤ直径) * (ピニオンギア歯数) / (スパーギア歯数) / (モータ一回転あたりのパルス数)<br>
単位は mm / pulse となるが、これはタイヤの直径をミリメートルで計測した場合であり、メートルで直径を定義すれば m / pulse となる。<br>
実際の値を代入して計算したところ、<br>
0.041274 mm / pulse となる。<br>
マイコンでは FPU を有効化していないのですべての計算を整数で処理する必要がある。<br>
そこで、タイヤの直径をマイクロメートル単位で計算することにする。<br>
<br>
【補足】<br>
ロボトレコースの全長はルールで 60 m 以下と決められている。<br>
mm 単位とすれば uint16_t ( 最大値 65535 ) に収まる範囲となっている。<br>
mm / pulse で計算してみて、精度が欲しくなったら um / pulse にしても良いと思う。<br>
【補足の補足】<br>
mm / pulse のまま LENGTHPERPULSE を求めると 0.041274 mm / pulse となり、FPU を有効化していないマイコンでは整数で計算する必要があり、1000 倍した um / pulse 単位で計算することになる。
今回のプログラムでは FPU を有効化していないのでこの um / pulse で計算することにする。
<br>
### ロータリスイッチを使いたい
ロータリスイッチで切り替えられるようにする機能たち<br>
リセットした瞬間に決まるモード 16種類<br>
リセットする前に決めるモード 16種類<br>
256 種類のプログラムを実行することが可能。<br>
リセットした瞬間に決まるモードについてはあまり需要がないかもしれない。<br>
前提として、SW1（ロータリスイッチ側にあるやつ）が決定。<br>
SW2（中央のやつ）がストップ・キャンセル
<table>
	<tr><th>Rotary_value</th><th>起動後の機能</th><th>リセット時の機能</th></tr>
	<tr><th>0</th><td>キャリブレーション</td><td>フロントセンサ＋メインセンサ</td></tr>
	<tr><th>1</th><td>走行方法１（等速走行）（ROM 書き込み有効）</td><td>メインセンサのみ</td></tr>
	<tr><th>2</th><td>走行方法２（加減速走行）</td><td>フロントセンサのみ</td></tr>
	<tr><th>3</th><td>走行方法３（加減速走行）</td><td></td></tr>
	<tr><th>4</th><td>D_ 出力</td><td></td></tr>
	<tr><th>5</th><td>ROM データの表示</td><td></td></tr>
	<tr><th>6</th><td></td><td></td></tr>
	<tr><th>7</th><td></td><td></td></tr>
	<tr><th>8</th><td></td><td></td></tr>
	<tr><th>9</th><td></td><td></td></tr>
	<tr><th>A</th><td></td><td></td></tr>
	<tr><th>B</th><td></td><td></td></tr>
	<tr><th>C</th><td></td><td></td></tr>
	<tr><th>D</th><td></td><td></td></tr>
	<tr><th>E</th><td></td><td></td></tr>
	<tr><th>F</th><td></td><td></td></tr>
</table>
操作感を決める。<br>
電源が入っていない状態でロータリスイッチを設定する。<br>
電源を入れたときにロータリスイッチの値でプログラムを変更する。<br>
一度スイッチを押してモード選択画面に入る。<br>
モードを選択する。<br>
enter スイッチを押す。<br>
どのモードが選択されているかを判断する。<br>
モードによって処理を分岐する。<br>
esc スイッチを押す。<br>
どのモードが選択されているかを判断しなくなる。
<br>
モードの開始と終了と共にタイマーの開始と終了をすると効率がいいかも。<br>
<br>
memo<br>
TIM6 (1ms) : PID	// 走る時に有効にする。<br>
TIM10 (1ms) : SIDESENSOR, ENCODER	// 走る時に有効にする。<br>
	TIM6 とまとめることができるならまとめたい。<br>
TIM11 (1ms) : ROTARY, SWITCH	// 常に有効にしておく<br>
TIM7 (0.1ms) : sensget sort<br>
キャリブレーションするときと走る時に有効にする。<br>
割り込み周期が速すぎる場合は周期を遅くするか、そもそもソートしなくてもいいかも。<br>

### エンコーダの読み取り値から左右のモータの速度差を出して旋回半径を求める。
この辺の処理はロボット外でやってもいい。<br>
数式<br>
(右折半径) + ((トレッド) / 2) : (右折半径) - ((トレッド) / 2) = (左速度) : (右速度)<br>
右折半径を R<br>
トレッドを T<br>
左速度をVl<br>
右速度をVr<br>
とすると。<br>
R = (T / 2) * ((Vr + Vl) / (Vr - Vl))<br>
右折で正、左折で負。<br>
<br>
Flash ROM を消して書き込んで読み込む。<br>
まずは関数の作成。<br>
```
// TARGET_SECTOR を変更したら start_address と end_address も変更する必要がある。
#define TARGET_SECTOR FLASH_SECTOR7;	// 読み書きするセクタを指定
const uint32_t start_address = 0x08060000	// Sector7 Start Address
const uint32_t end_address = 0x0807FFFF	// Sector7 End Address

// TARGET_SECTOR に指定したセクタを削除する。
void eraseFlash(void)
{
    // FLASH_EraseInitTypeDef は削除のための設定をまとめた構造体
	FLASH_EraseInitTypeDef erase;	// インスタンスの生成
    // セクタを選択して削除するか、全削除するか選択する。
	erase.TypeErase = FLASH_TYPEERASE_SECTORS;	// セクタを選ぶ
    // 削除するセクタの指定。
    erase.Sector = TARGET_SECTOR;   // #define TARGET_SECTOR FLASH_SECTORx
    // 削除したい 1 セクタ分を指定する。
    erase.NbSectors = 1;
    // マイコンの電圧を指定する。
    erase.VoltageRange = FLASH_VOLTAGE_RANGE_3;
    // 
    uint32_t pageError = 0;

    // セクタを削除する。
    // HAL_StatusTypeDef HAL_FLASHEx_Erase(FLASH_EraseInitTypeDef * pEraseInit, uint32_t *SectorError); で定義されている。
    // uint32_t *SectorError には削除が失敗した場合にそのセクタのポインタが入る。
    // 問題なく削除できた場合は 0xFFFF が入る。
    HAL_FLASHEx_Erase(&erase, &pageError);
    /*
    if(pageError == 0xFFFF)
    {
        printf("Erase Collect!\r\n");
    }
    */
}

// 使う時は writeFlash(start_address, (uint64_t*)maze_data, sizeof(MAZE_DATA));
void writeFlash(uint32_t address, uint64_t *data, uint32_t size)
{
    // FLASH のアンロック
    HAL_FLASH_Unlock();
    // セクタの削除
    eraseFlash();

    // address から address + size まで add を移動する。
    for(uint32_t add = address; add < (address + size); add++)
    {
        // バイトを書き込む。
        // HAL_StatusTypeDef HAL_FLASH_Program(uint32_t TypeProgram, uint32_t Address, uint64_t Data); で定義される。
        // uint32_t TypeProgram で何バイト書き込むのかを設定する。
        // #define FLASH_TYPEPROGRAM_BYTE ((uint32_t)0x00U)
        // #define FLASH_TYPEPROGRAM_HALFWORD ((uint32_t)0x01U)
        // #define FLASH_TYPEPROGRAM_WORD ((uint32_t)0x02U)
        // #define FLASH_TYPEPROGRAM_DOUBLEWORD ((uint32_t)0x03U)   // 数字の末尾に U を付けると符号なし整数(unsigned)を意味する。
        // uint32_t Address に uint64_t Data を書き込む。
        HAL_FLASH_Program(FLASH_TYPEPROGRAM_BYTE, add, *data);
        // データポインタを加算する。つまり data に渡された配列または構造体の、次の要素に移る。
        data++;
    }
    
    // ライトプロテクトを有効化。
    HAL_FLASH_Lock();
}

// 使う時は loadFlash(start_address, (uint64_t*)maze_data, sizeof(MAZE_DATA));
void loadFlash(uint32_t address, uint64_t *data, uint32_t size)
{
    // データをコピーする。
    memcpy(data, (uint64_t*)address, size);
}
```
STM32F446 Nucleo-64 を用いて ROM 書き込みの実験をしてみた。<br>
[実際のプログラムがこちら](https://github.com/YazawaKenichi/Murakumo/blob/main/programs/FLASH_test_F446.c)<br>
そしてデータの読み書きに成功。<br>
<br>
read していたデータを一度 write で書き込んで...<br>
リセットしてみる（read... で値が表示されていない）<br>
リセット後も write した値が保持されている証拠に、同じ値が read されている。<br>
<br>
### IMU を載せた。<br>
[ICM-20648](https://3cfeqx1hf82y3xcoull08ihx-wpengine.netdna-ssl.com/wp-content/uploads/2021/07/DS-000179-ICM-20648-v1.5.pdf)<br>
project.ioc で SPI2 を有効化する。マイコンはマスター側なので Full-Duplex Master を選択する。<br>
Frame Format は知らん。大体 Motorola らしい。<br>
datasheet の 6.5 SPI INTERFACE に SPI 通信の方法が載っている。<br>
データは MSB (最上位ビット) が最初に送信され。LSB (最下位ビット) が最後に送信される。<br>
つまりマイコン側から見れば、MSB を最初に受信して、LSB を最後に受信することがわかる。<br>
このことから project.ioc ファイルの、Parameter Settings の First Bit の設定は MSB First で良さそう。<br>
同じ項目から、SPI Data format は 8bit であることがわかる。<br>
<br>
<br>
<br>
<br>
<br>
<br>
<br>
<br>
<br>
<br>
<br>

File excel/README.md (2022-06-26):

- [x] 種類を決める
 - [x] 基板がシャーシかシャーシの上に基板か > シャーシの上に基板 ∵ 自由度が高そう（基板だけ取り換えるとかいう改造も可能）
 - [x] センサステアかステア固定か > センサ固定 ∵ シンプルな設計ができる
 - [x] 対向二輪かスキッドステアか4輪ステアか > スキッドステア

- [x] サイズ・重量
 - [x] サイズ > H W100 D (mm) 可能な限り小さくする。∵ 小さいということは必然的に質量も小さくなるから。
 - [x] 重量 > 100 (g)

- [ ] センサバーの長さ・トレッド・ホイールベース
 - [ ] センサバーの長さ > 曲線センサは下記思考で自動的に長さが決まる。直線センサは車体と同じくらいの長さ。
 - [ ] トレッド > 100 - 13 ∵ トレッドが 100 でタイヤ幅が 13 というのが先に決まったから。
 - [ ] ホイールベース > 極めて短く ∵ タイヤの軸方向のモーメントを小さくするため。 => 24 mm ∵ タイヤ径から少し余裕を持たせたホイールベースを考えた結果
 - 以下思考
 - ホイールシャフトの中点を中心に円形にセンサを配置したい。そうすればセンサの値で角度がわかりやすい。直線センサに対してもこれを適応してもいい。ただ直線センサは距離が遠くなるのでほとんどまっすぐになりそう。

- [x] 最高速度・最高加速度
 - [x] 最高速度 > 8.5 (m/s) ∵ 6 ~ 7 (m/s) あれば十分で最強が 10 (m/s) なら、間を取って 8.5 (m/s) で良いかなって
 - [x] 最高加速度 > 17 (m/s/s) 厳密には 16.9851178 (m/s/s) 数式的には 1.732 * g (但、ここにおける g とは重力加速度) ∵ 最大加速度で加速したときにスリップしないギリギリの加速度がこれだった。

- [x] タイヤ径・幅
 - [x] 径 > 22 (mm) (直径) ∵ タイヤ径を決めないとモータが決まらず、モータ決めないとタイヤ径が決まらない状況になって、井口先輩も下鳥先輩もノムさんもこのくらいにしてるから。
 - [x] 幅 > 13 (mm) ∵ シートが貼れる幅。
 - [x] タイヤには井口先輩の機体にくっついてるシールを使う。

- [x] 最高速度から必要な出力回転数を求める > 8117 (rpm) 厳密には 8116.902098 (rpm) 数式的には (8.5 * 10^3 * 60) / (2pi * 10) = 25500 / pi ※ 
- [x] 最高加速度から必要な出力トルクを求める > 17000 (mNm) 厳密には 16985.1178 (mNm) 数式的には 1.732 * g * 100 * 10 = 1732 * g ※これを超えたトルクを出すとスリップする。また、片側の車輪のトルクはこれの 1/2 倍となる。
- [x] この時点でパワー（仕事率）は 137989000 (W) 厳密には 137866538.3 (W) 数式的には (25500 / pi) * (1732 * g)

- [x] バッテリ > Hyperion G8 HV 3.7V 220mAh

- [x] モータ > DCX 10 L 貴金属ブラシ 1.5V
- ブラシレスモータは、モータ外部に複数の制御回路を組む必要があり、回路が全体的に複雑なものになってしまうため、今回はコンセプトにそぐわないとして、採用を見送りとする。 [詳細はこちら](https://www.orientalmotor.co.jp/tech/reference/brushless01/)
- 尚、優良なブラシレスモータとして、maxon EC 4 0.5W 3V をメモしておく。

- [x] ギヤ比 > 
- スパーギア > M0.3 Z64 AD19.8
- ピニオンギア > M0.3 Z42 AD13.2
- ギヤ比 > 64 / 42 ≒ 1.523809523089523809... // 一番の理想はこれなんだが、互いに素にした方がよいのでギア比は 64 / 41 にする。
- ~~ギヤ比って回転数で決めるのかトルク比で決めるのか、どっちで決めた方がいいのか... maxon motor のカタログの P54 くらいを見てヒントを探す。~~
- ~~回転数とトルクをまとめると...~~
- ~~最高速度 : 8.5 m/s~~
- ~~モータの最大回転数 rpm : 11600 rpm~~
- ~~最高加速度 : 17 m/s/s~~
- ~~モータの最大トルク : 87.241 mNm~~
- ~~回転数から求めるギヤ比 = (最高速度 / 2pi) / (2pi * (モータの回転数 rpm) / 60) = 60 * (最高速度) / (モータの回転数 rpm)~~
- ~~これより大きくなれば良い。~~
- ~~トルクから求めるギヤ比 = (ピニオンのトルク) / (スパーギアのトルク) = モータのトルク * (ピニオンの半径 / モータ軸半径)  / 最高加速度 * スパーギアの半径 = (モータのトルク * ピニオン半径) / (モータ軸半径 * 最高加速度 * スパーギア半径)~~
- ~~(モータのトルク) = (ピニオンのトルク) とするならば、~~
- ~~トルクから求めるギア比 = (モータのトルク) / (最高加速度 * スパーギアの半径) となり、上記に戻すには (ピニオン半径 / モータ軸半径) を掛け算する必要がある。~~
- ~~これより小さくなればいい。~~
- ~~求めるギア比の範囲は (トルクから求めるギア比) >= n >= (回転数から求めるギア比) とすればよい。~~
- Excel でギア比とモータの性能を変数にしたシートを作成して、回転数とトルクが必要以上でありつつ、許容回転数をオーバーしないようなパターンを探したら、上記のモータとギヤ比に決まった。

- 実際に求めた結果
- 回転数から求めるギア比 = 51 / 923 = 0.05525460455 ≒ 0.0553
- トルクから求めるギア比（ピニオン半径 = モータ軸半径） = 26 / 4675
- おかしい、トルクから求めるギア比の方が小さくなったぞ？？？

##### メモ
小さいギヤと大きいギヤが一つになってるやつの特徴（小さいやつを「入力ギヤ」、大きいやつを「出力ギヤ」とする）
- 回転数が同じ => 角速度が同じ
- 接戦方向成分の速度が大きくなる（∵v = rw）
- トルクはどうなる？半径は大きくなったが、同じ力が伝達されるとは限らないぞ？-> 同じ力が伝達されることの証明は必要？
- ゆーて普通の減速比と同じよ
- ###### ここから自分なりの考察
- (減速比) = (外側歯車の角速度) / (内側歯車の角速度) = (2pi * 外側歯車の回転数) / (2pi * 内側歯車の回転数) = (外側歯車の回転数) / (内側歯車の回転数)

- スキッドステアのトルクを考えるときは、同じ車輪径の対向二輪として考えることができる。

- 平歯車や傘歯車における「効率」とは、仕事率の伝達効率。
- 例えば効率 50% の歯車機構があったとして、動力側の出力が t, w だとする。
- すると被動力側の出力は t * w * 0.5 となる。
- ただ角速度は等速のため、単純にトルクが 1 / 2 倍されたと考えることができる。
- 平歯車はインボリュート曲線というものを用いて、歯車同士の接触している点は必ず向心直線に垂直（モーメント方向）に力が加わるように設計されている。これにより様々な種類の歯車機構の中でも最も伝達効率の良い歯車機構となっている。ほかの機構では力の方向が効率よくモーメント方向に力が加えられなかったり、摩擦によって熱として損失が発生してしまう。

- 公称電圧はあくまでモータの種類を区別するためのもの。

- 停動トルクは最大トルク

- 無負荷回転数の時最高速度が出せるのが理想だが、実際は摩擦を考慮してトルクが少しある状態で必要な回転数が得られるようにモータを選定する。

##### 復習
- (減速比) = (タイヤの角速度) / (モータの角速度)
- (仕事率(パワー)) = (トルク) * (角速度)
- ギヤ間で仕事率は保存される
- ∴ (減速比) = (モータのトルク) / (タイヤのトルク) とも言える。
- 深く調べてみると、減速比の定義は
- (減速比) = (ピニオンギアの歯数) / (スパーギアの歯数)　のようだ。これが結局 (スパーギアの角速度) / (ピニオンギアの角速度) になるっぽい。
- 速度伝達比 というのもあって、これは歯車列において最初と最後しか見ない。
- (速度伝達比) = (最後の歯車の歯数(作用側)) / (最初の歯車の歯数(動力側)) 二段で考えれば減速比と同じ考えで良いんじゃね？

- トルクは電流に比例し、角速度は起電力に比例する。この時の比例定数をそれぞれ、「トルク定数」「回転数定数」と呼ぶ。
- モータの等価回路は、抵抗と電源とみなすことによって V = RI + E の式が得られる。これに上記比例式を適応すると、トルクから回転数を求める一次関数が得られる。
- 回転数とトルクの関係式 : w = - (k_w / k_t) * R * t + k_w * V (w : 回転数 k_w : 回転数定数 k_t : トルク定数 R : レジスタンス V : 公称電圧)
- 定格トルク以下なら何をやってもいい。定格トルクを超えたいときは一瞬だけ！

##### Maxon Catalog 読み替え単語帳
無負荷回転数 => 最大回転数
最大連続トルク時の回転数 => 定格回転数
最大連続トルク => 定格トルク
※最大トルク = トルク定数 * 無負荷電流

================================================== タイヤ周りを作り直す。 ==================================================

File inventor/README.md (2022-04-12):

歯車のかみ合わせが悪いのか走らせるとカタカタ鳴る。

ギアのかみ合わせを変えた結果ｖｖｖｖｖｖｖｖｖｖｖｖｖｖｖｖｖｖｖｖｖｖｖｖｖｖｖｖｖｖｖｖｖｖｖｖｖｖｖｖｖｖｖｖｖｖｖｖｖｖｖｖｖｖｖｖｖｖｖｖｖｖｖｖｖｖｖｖｖｖｖｖｖｖｖｖｖｖｖｖｖｖｖｖｖｖｖｖｖｖｖｖｖｖｖｖｖｖｖｖｖｖｖｖｖｖｖｖｖｖｖｖｖｖｖｖｖｖｖｖｖｖｖｖｖｖｖｖｖｖｖｖｖｖｖｖｖｖｖｖｖｖｖｖｖｖｖｖｖｖｖｖｖｖｖｖｖｖｖｖｖｖｖｖｖｖｖｖｖｖｖｖｖｖｖｖｖｖｖｖｖｖｖｖｖｖｖｖｖｖｖｖｖｖｖｖｖｖｖ

#### パーツセット

モータブラケットの素材：ABS（カーボン）
天板の素材 CFRP
このままだとシャーシ基板になりそう...

重心計算をする

バッテリの固定方法を考える

モータブラケットの厚みを減らす

二階の下げる

タイヤの固定方法
両面テープ

ねじ頭の干渉を考える
m2 超低頭ねじ頭直径4

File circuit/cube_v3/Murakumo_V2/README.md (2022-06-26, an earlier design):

#### モータの PWM 制御

DRV8874 の PMODE ピンが GND に落ちているので PN/EN 制御となる。

PN/EN 制御は EN に 0 を入れると無条件でモータが Break する。

PN に 1 を入れて正転、0 を入れて逆転となる。

∴PN には常に 1 を入れ続けて、EN を PWM 制御する

#### ADC の話

正直複数チャンネル ADC (マルチプレクサ ADC ともいうらしい) のメリットが全然わからん。

#### ADC の Pin と Channel と Rank と analog[Index] の対応表
<table>
  <tr><th>Pin</th><td>PB1</td><td>PB0</td><td>PC5</td><td>PC4</td><td>PA7</td><td>PA6</td><td>PA5</td><td>PA4</td><th>Pin</th><td>PA3</td><td>PA2</td><td>PA1</td><td>PA0</td><td>PC3</td><td>PC2</td><td>PC1</td><td>PC0</td><th>Pin</th></tr>
  <tr><th>Channel</th><td>9</td><td>8</td><td>15</td><td>14</td><td>7</td><td>6</td><td>5</td><td>4</td><th>Channel</th><td>3</td><td>2</td><td>1</td><td>0</td><td>13</td><td>12</td><td>11</td><td>10</td><th>Channel</th></tr>
  <tr><th>Rank</th><td>1</td><td>3</td><td>5</td><td>7</td><td>9</td><td>11</td><td>13</td><td>15</td><th>Rank</th><td>16</td><td>14</td><td>12</td><td>10</td><td>8</td><td>6</td><td>4</td><td>2</td><th>Rank</th></tr>
  <tr><th>Index</th><td>0</td><td>2</td><td>4</td><td>6</td><td>8</td><td>10</td><td>12</td><td>14</td><th>Index</th><td>15</td><td>13</td><td>11</td><td>9</td><td>7</td><td>5</td><td>3</td><td>1</td><th>Index</th></tr>
</table>

偶数インデックスに左のセンサ、奇数インデックスに右のセンサが入る。<br>
[0] ~ [11] に本体のセンサ、[12] ~ [15] にセンサバーが入る。<br>
こうすることで、for 関数を使ってアナログ値をより簡単に扱うことが可能になる。<br>

#### 自分のプログラムの説明
C14 : SW1

キャリブレーションの動作
``` C
// int main(void) {
for(int i = 0; !HAL_GPIO_ReadPin(GPIOc, GPIO_PIN_14); i++)  // SW1 が押されるまで処理する
{
  for(int j = 0; ADC_CONVERTED_DATA_BUFFER_SIZE > 0; j++) // センサの最大値と最小値を更新する
  {
    // そこのセンサを使おうが使わなかろうがとにかくすべての ADC の値で最大値を出す。
    analogmax[j] = (analogmax[j] < analog[j]) ? analog[j] : analogmax[j];
    // そこのセンサを使おうが使わなかろうがとにかくすべての ADC の値で最小値を出す。
    analogmin[j] = (analogmin[j] > analog[j]) ? analog[j] : analobmin[j];
  }
}
```

デューティー比の算出
必要な要件
最大値と最小値
最大値を上回ってしまったら最大値を更新する
最小値を下回ってしまったら最小値を更新する
``` C
unsigned short int analogl, analogr;  // 最大でも 8000 までしか入らない。
unsigned short int analograte[CALIBRATIONSIZE] = {0};

// TIM6
// センサの個体差を無視するための計算処理
// #define USE_LONGSENSOR 1 の時はこの処理ではうまくいかないので注意。
for(int i = 0; i < CALIBRATIONSIZE; i++)
{
//  こうすると for の途中から analograte の値が変に変わる時ができてしまう。for 処理を一旦終わらせてから最小値と最大値を更新する処理をしてもいいと思う。
//  analogmax[j] = (analogmax[j] < analog[j]) ? analog[j] : analogmax[j]; // 自分に自分を代入するのは効率が悪いだろうか？いつか実験してみたい。
//  analogmin[j] = (analogmin[j] > analog[j]) ? analog[j] : analobmin[j];
  analograte[i] = ((analog[i] - analogmin[i]) * 1000) / analogmax[i]; // 最大値と最小値の間で 1000 分割した値出す。

  // こうなったら analograte の総和を取るのもアリ
  if(i % 2 == 0)
  {
    analogl += analograte[i];
  }
  else
  {
    analogr += analograte[i];
  }
  // CALIBRATIONSIZE が既に、使用するセンサの数と一致してくれているので、Long Sensor が未接続状態でもそこまでで総和を出してくれる。
}
```

センサ値をソートするプログラム
``` C
analogbuffers[SENSGETCOUNT][CALIBRATIONSIZE];

if(htim->Instance == TIM7)	// TIM7 // 0.1ms
{
  // 0.9ms かけて配列を埋める
  if(sensgettime >= SENSGETCOUNT) // public char sensgettime; #define SENSGETCOUNT 9
  {
    sensgettime = 0;
  }
  for(char index = 0; CALIBRATIONSIZE > index; index++)
  {
    analogbuffers[sensgettime][index] = analograw[index];
  }
}

if(htim->Instance == TIM11)  // TIM11 // 1ms
{
		for(unsigned char index = CALIBRATIONSIZE - 1; index > 0; index--)	// DownCounter
		{
			for(unsigned char count = SENSGETCOUNT - 1; count > 0; count--)	// DownCounter
			{
				for(unsigned char alphaindex = count; alphaindex > 0; alphaindex--)	// DownCounter
				{
					if(analogbuffers[alphaindex - 1][index] > analogbuffers[alphaindex][index])
					{
						uint16_t analogbuffer = analogbuffers[alphaindex - 1][index];
						analogbuffers[alphaindex - 1][index] = analogbuffers[alphaindex][index];
						analogbuffers[alphaindex][index] = analogbuffer;
					}
				}
			}
		}
}
```

```analogbuffers[][]``` の中身。
<table>
  <tr>
    <th>index \ alphaindex</th>
    <th></th>
    <th></th>
    <th></th>
    <th></th>
    <th></th>
    <th></th>
    <th></th>
    <th></th>
    <th></th>
  </tr>
  <tr>
    <th>sens_i</th>
    <td></td>
    <td></td>
    <td></td>
    <td></td>
    <td></td>
    <td></td>
    <td></td>
    <td></td>
    <td></td>
  </tr>
  <tr>
    <th>sens_i</th>
    <td></td>
    <td></td>
    <td></td>
    <td></td>
    <td></td>
    <td></td>
    <td></td>
    <td></td>
    <td></td>
  </tr>
  <tr>
    <th>sens_i</th>
    <td></td>
    <td></td>
    <td></td>
    <td></td>
    <td></td>
    <td></td>
    <td></td>
    <td></td>
    <td></td>
  </tr>
  <tr>
    <th>sens_i</th>
    <td></td>
    <td></td>
    <td></td>
    <td></td>
    <td></td>
    <td></td>
    <td></td>
    <td></td>
    <td></td>
  </tr>
  <tr>
    <th>sens_i</th>
    <td></td>
    <td></td>
    <td></td>
    <td></td>
    <td></td>
    <td></td>
    <td></td>
    <td></td>
    <td></td>
  </tr>
  <tr>
    <th>sens_i</th>
    <td></td>
    <td></td>
    <td></td>
    <td></td>
    <td></td>
    <td></td>
    <td></td>
    <td></td>
    <td></td>
  </tr>
  <tr>
    <th>sens_i</th>
    <td></td>
    <td></td>
    <td></td>
    <td></td>
    <td></td>
    <td></td>
    <td></td>
    <td></td>
    <td></td>
  </tr>
  <tr>
    <th>sens_i</th>
    <td></td>
    <td></td>
    <td></td>
    <td></td>
    <td></td>
    <td></td>
    <td></td>
    <td></td>
    <td></td>
  </tr>
  <tr>
    <th>sens_i</th>
    <td></td>
    <td></td>
    <td></td>
    <td></td>
    <td></td>
    <td></td>
    <td></td>
    <td></td>
    <td></td>
  </tr>
  <tr>
    <th>sens_i</th>
    <td></td>
    <td></td>
    <td></td>
    <td></td>
    <td></td>
    <td></td>
    <td></td>
    <td></td>
    <td></td>
  </tr>
  <tr>
    <th>sens_i</th>
    <td></td>
    <td></td>
    <td></td>
    <td></td>
    <td></td>
    <td></td>
    <td></td>
    <td></td>
    <td></td>
  </tr>
  <tr>
    <th>sens_i</th>
    <td></td>
    <td></td>
    <td></td>
    <td></td>
    <td></td>
    <td></td>
    <td></td>
    <td></td>
    <td></td>
  </tr>
</table>
つまり ```alphaindex``` はそのままのセンサの値が入っている。```index``` はセンサの位置の値が入っている。
```alphaindex``` を捜査して ```index``` 番目のセンサの値をソートする。
```count``` には

### エンコーダのプログラムを実装する
1パルスあたりにタイヤが進む距離を求める。
2 PI * (タイヤ径 mm) * (ピニオンギア) / (スパーギア) / (エンコーダ分解能)
単位は mm / pulse となる。
タイヤ径をメートルで計算すれば1パルスあたりのメートルが出る。
変位次元についての式なので、計算周期（時間次元）は式から消去される。

【復習】

マルチプレクサとは、回路選択信号を受け取って回路を選択する。n 回路 n + 1 接点トグルスイッチのようなもの。

先輩の説明も、ネットの説明も、「二つのアナログが読めるよ」的なことをおっしゃる。

でも俺としては、「チャンネルが二つ以上あっても ADC ピンの数はひとつなんだから、二つのチャンネルで ADC を読んでも意味がないのでは？」という疑問がわく。

////////////////////////////// 従来のノート //////////////////////////////

プログラムのノート

センサの位置と Rank の対応表
奥 Rank                 05, 04 | 03, 02
前 Rank 16, 15, 14, 13, 07, 06 | 01, 00, 12, 11, 10, 09

analog 配列は uint16_t と、16bit で定義されてはいるものの、実際に入る値は 0 ~ 4095 (4096 かも...) の間なので、16bit すべては使っておらず、12bit で表現できる。
例えば、すべてのセンサの値が 4095 になったとして、これを片側 8 個分だけ足すと、
4095 * 8 = 32760
すなわち、片側のセンサの最大値は 32760 であり、片側のセンサの合計値を格納する変数のサイズは unsigned 15bit (最大値 32767) でギリギリ足りるはずである。
∴片側のセンサの合計値は uint16_t で格納しておけば良さそう。

  疑問
unsigned int 16bit 型から unsigned int 16bit 型を引く、計算結果は unsigned int 16bit 型で大丈夫だろうか？
ここでは便宜的に、右側のセンサ値を AnalogR とし、左側のセンサ値を AnalogL とする。
AnalogR >= AnalogL を満たしている場合は AnalogR - AnalogL > 0 となるので、計算結果を uint16_t としても大丈夫だろう。
しかし問題は AnalogR < AnalogL となっている場合である。
この場合は AnalogL - AnalogR に計算式を変更する必要が出てきてしまう。

ここで計算結果にマイナスを許したとしよう。
例えば、計算結果を格納する変数を signed int 型にする。
すると格納できる値の範囲は -32767 ~ 0 ~ 32768 の 65536 通りとなる。
これなら万が一 AnalogL == 32760 && AnalogR == 0 を満たしてしまった場合でも、AnalogR - AnalogL = -32760 となり、オーバーフローせずに値を格納することができる。
∴全センサの計算結果を格納する変数は signed int 型で問題ないことが分かった。
  以上
  
rightmotor, leftmotor に代入する式を考える。
「片側のモータがギリギリ反転しない」を目指して作った式。
leftmotor = commspeed + direction * (1000 - commspeed) / 32768;
rightmotor = commspeed - direction * (1000 - commspeed) / 32768;
こうするとどちらか一方が「めっちゃ黒！」ってなった時に白線がある方のタイヤが止まり、めっちゃ黒な方が 100% duty で回転する。
この式は PID 制御の比例のみ制御と似た式となっている。
分かりやすく書き換えると
PGain = (AnalogL - AnalogR) * KP
という式になっており、(AnalogL - AnalogR) == 0 を満たしたときに前進するための commspeed と、0 <= leftmotor, rightmotor <= 10000 を満たすような KP の値を計算している。
二度も計算させるのは嫌なので direction * (1000 - commspeed) / 32768 は変数に格納してもいい希ガス。
この値は -32,768,000 ~ 32,767,000 の値を取るので、型は int 型。
（int の範囲 -2,147,483,648 ~ 2,147,483,648)

# エンコーダ
PA8 -> 41 -> Encoder1_A -> EncoderLeft_A (TIM1_CH1)<br>
PA9 -> 42 -> Encoder1_B -> EncoderLeft_B (TIM1_CH2)<br>
PB4 -> 56 -> Encoder2_A -> EncoderRight_A (TIM3_CH1)<br>
PB5 -> 57 -> Encoder2_B -> EncoderRight_B (TIM3_CH2)<br>

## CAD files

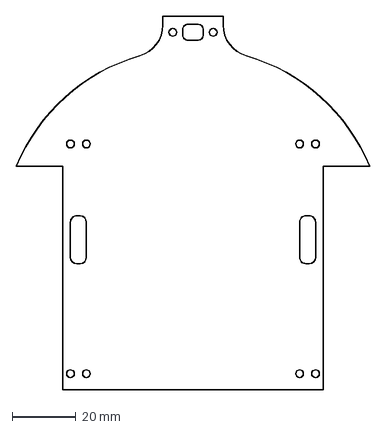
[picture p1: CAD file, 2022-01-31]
dxf/Main.dxf
110.8 x 117.0 mm

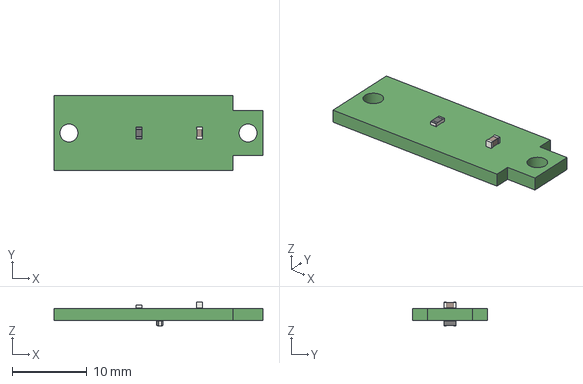
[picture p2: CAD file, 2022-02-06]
circuit/kicad/Step/SubSensor.step
28.0 x 10.00 x 3.16 mm

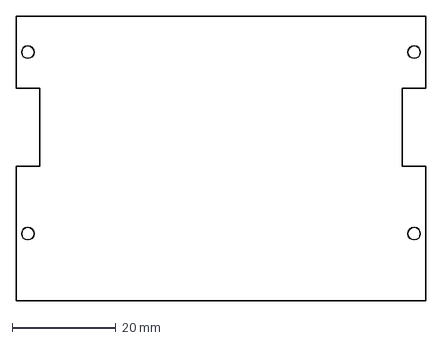
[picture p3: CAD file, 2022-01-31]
dxf/Power.dxf
78.8 x 54.8 mm

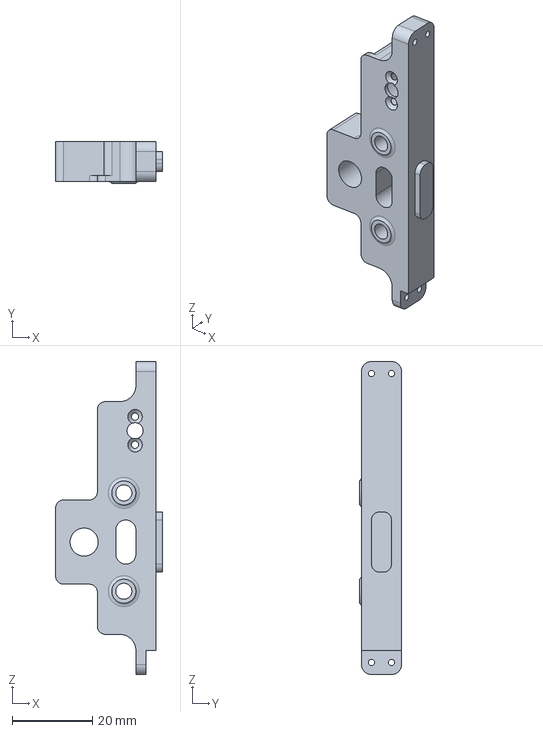
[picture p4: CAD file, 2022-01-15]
inventor/MotorBracket.stp
26.6 x 10.5 x 78.0 mm

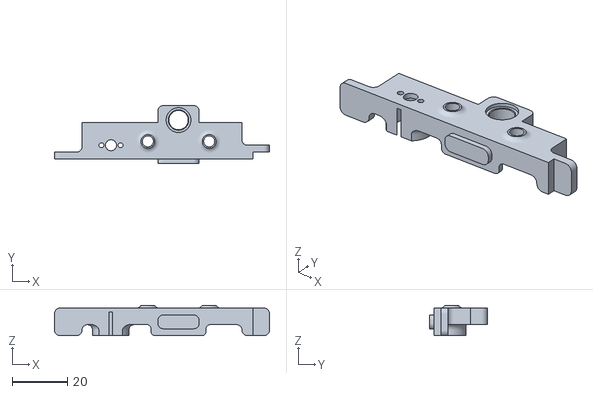
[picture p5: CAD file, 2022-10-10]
inventor/MotorBracket_v6.4/MotorBracket_v6.4.stl
78.0 x 21.0 x 11.0

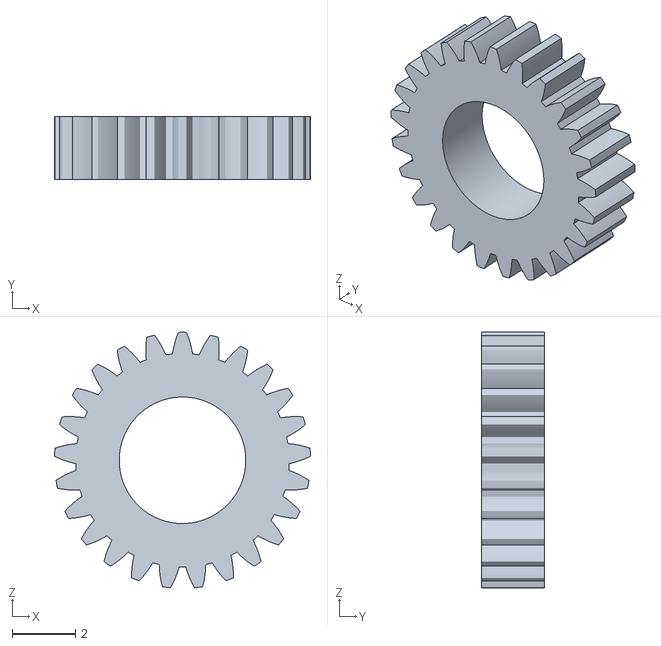
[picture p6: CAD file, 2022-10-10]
inventor/pinion_middle_25/pinion_middle_25.stl
8.10 x 2.00 x 8.08

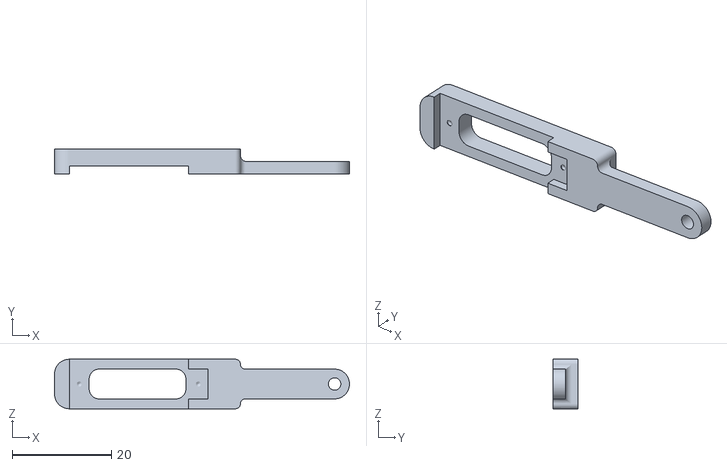
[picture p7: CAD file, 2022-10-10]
inventor/STL/SideSensor_Mount.stl
59.5 x 5.00 x 10.0

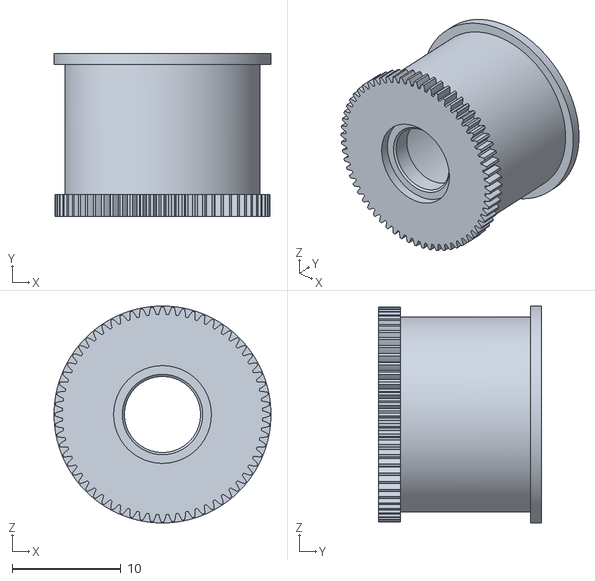
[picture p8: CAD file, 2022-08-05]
inventor/wheel_v6/wheel_v6.stl
20.0 x 15.0 x 20.0

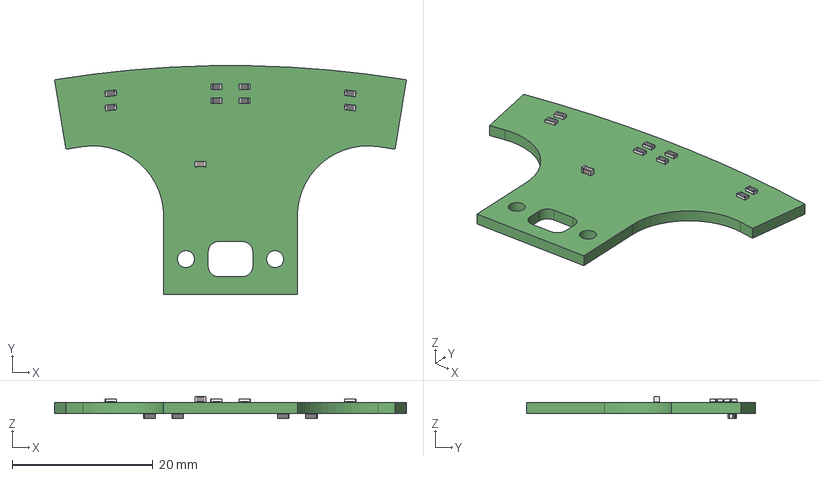
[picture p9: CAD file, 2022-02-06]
circuit/kicad/Step/FrontSensor.step
50.0 x 32.5 x 3.16 mm

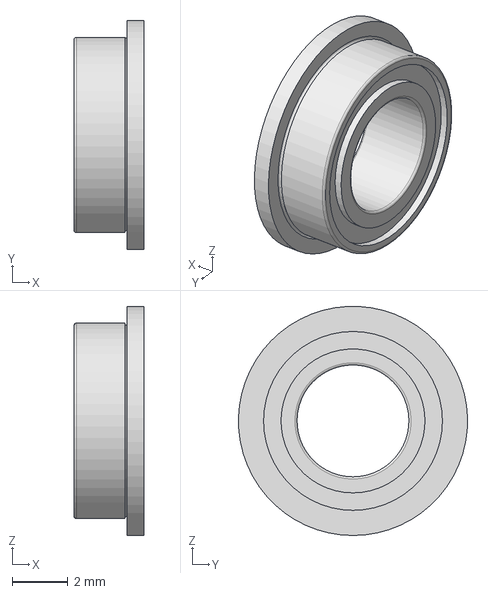
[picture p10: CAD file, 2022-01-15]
inventor/FL674ZZ.stp
2.50 x 8.20 x 8.19 mm

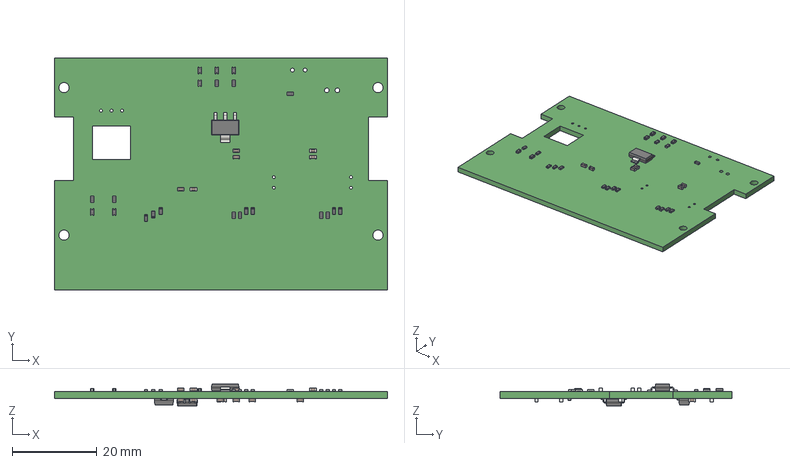
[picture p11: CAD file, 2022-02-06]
circuit/kicad/Step/Power.step
78.8 x 54.8 x 5.15 mm

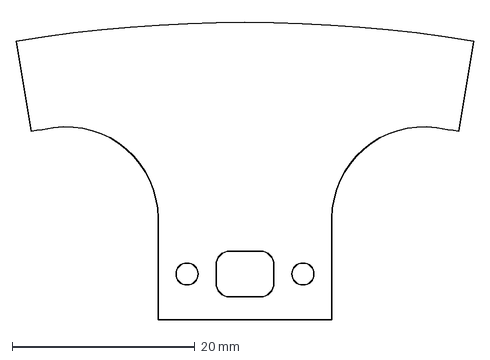
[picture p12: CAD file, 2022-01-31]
dxf/FrontSensor.dxf
50.0 x 33.2 mm

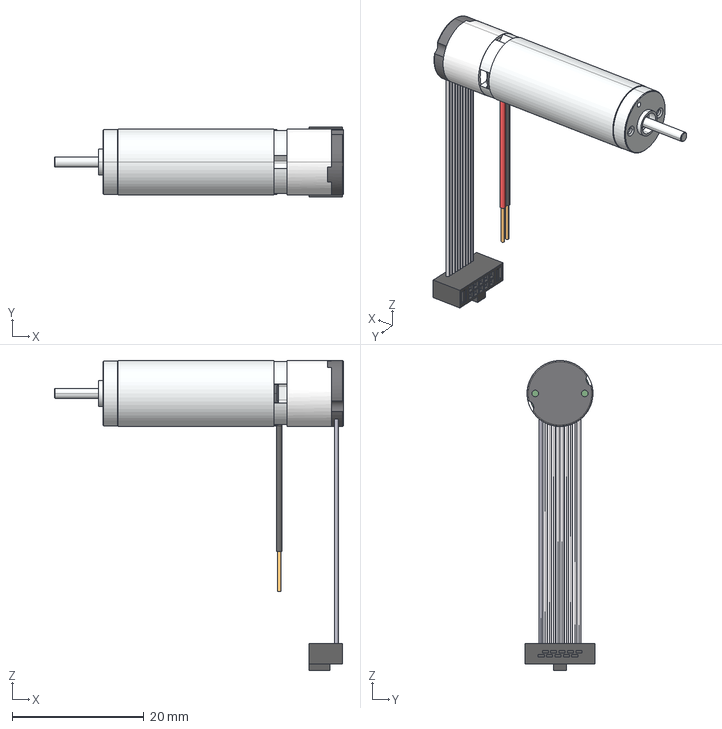
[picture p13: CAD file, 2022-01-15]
inventor/maxon DCX 10L.stp
43.9 x 10.5 x 47.0 mm

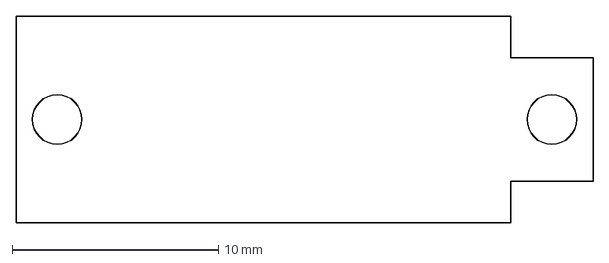
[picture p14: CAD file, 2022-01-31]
dxf/SubSensor.dxf
28.0 x 10.00 mm

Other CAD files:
inventor/STL/MotorBracketv3.stl
inventor/STL/wheel_v8.stl
inventor/STL/MotorBracketv3.3.stl
inventor/STL/MotorBracketv3.4.stl
circuit/kicad/Step/COMPOUND.ipt
circuit/kicad/Step/C_0603_1608Metric.iam
circuit/kicad/Step/D_0603_1608Metric.iam
circuit/kicad/Step/FrontSensor.iam
circuit/kicad/Step/LQFP-64_10x10mm_P0.5mm.iam
circuit/kicad/Step/L_0603_1608Metric.iam
circuit/kicad/Step/Main.iam
circuit/kicad/Step/OldVersions/COMPOUND.0001.ipt
circuit/kicad/Step/OldVersions/COMPOUND.0002.ipt
circuit/kicad/Step/OldVersions/COMPOUND.0003.ipt
circuit/kicad/Step/OldVersions/C_0603_1608Metric.0001.iam
circuit/kicad/Step/OldVersions/C_0603_1608Metric.0002.iam
circuit/kicad/Step/OldVersions/C_0603_1608Metric.0003.iam
circuit/kicad/Step/OldVersions/D_0603_1608Metric.0001.iam
circuit/kicad/Step/OldVersions/D_0603_1608Metric.0002.iam
circuit/kicad/Step/OldVersions/D_0603_1608Metric.0003.iam
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

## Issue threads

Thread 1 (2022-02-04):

【干渉】FTSH コネクタと二階基板

YazawaKenichi, 2022-02-04:
FTSH コネクタが二階の基板と干渉する気がする。
詳しい寸法と干渉度合はまた後で記載。
最悪の場合コネクタ周りの配線をし直すことになりそう。
FFC コネクタと FTSH コネクタの位置を入れ替えるといいかもしれない。

YazawaKenichi, 2022-02-04:
井口先輩の機体を見せてもらった感じだと、FTSH にエンコーダの IDC コネクタを繋いだ状態でもモータの直径 10 より余裕をもって小さいと言える。
このままで大丈夫そう。

YazawaKenichi, 2022-02-04:
一応基板間隔を記載しておく。

基板間隔 : 11.6
モータパワー間隔 : 1.4
モータメイン間隔 : 0.2 (もっと迫れると思う)

Closed 2022-02-04.

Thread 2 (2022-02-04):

【干渉】モータマウントのねじ同士

YazawaKenichi, 2022-02-04:
ねじ穴が近すぎてねじ山同士が干渉する可能性がある。

まずはねじ山の寸法を測って干渉するかどうかを再確認する。

もし干渉するようなら穴を一つにする。
これ以上幅を取りたくない。
前後でねじ止めするし、位置決めも正しく行われている。さらにカーボンフィラメントを用いて出力するので強度も問題ない。

YazawaKenichi, 2022-02-04:
全然問題なかった。

YazawaKenichi, 2022-02-04:
ねじ穴はこのままの設計で行こうと思う。

Closed 2022-02-04.

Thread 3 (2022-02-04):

【疑問】FFC コネクタとケーブルの構造

YazawaKenichi, 2022-02-04:
どうしよう...

YazawaKenichi, 2022-02-04:
コネクタとケーブルの構造がわからないからどうやってピンアサインを決めればいいのかわからない。

YazawaKenichi, 2022-02-04:
FFC コネクタ側の構造
蓋の方に電気は通らない。
だから裏表逆にすると死亡。
設計しなおせ。

YazawaKenichi, 2022-02-04:
確認チェックリスト
- [ ] サブセンサにつながるコネクタ
- [ ] メインセンサにつながるコネクタ
- [ ] モータドライバにつながるコネクタ
- [ ] UI につながるコネクタ
- [ ]

YazawaKenichi, 2022-02-04:
逆にできるコネクタを見つけたのでこれを買ってしまおう。

Closed 2022-02-04.

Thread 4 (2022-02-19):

【干渉】FTSH コネクタ同士の間隔が狭すぎた。

YazawaKenichi, 2022-02-19:
こんな感じ。

https://gyazo.com/e960e684ffcdcdde789ea084fffffc49

YazawaKenichi, 2022-02-22:
コネクタメス側を削った
これで「物理的に干渉して接続できない」なんてことは無くなった。

しかし、ギリギリを攻めすぎて端子が露出した。
そのせいで do not connect と Channel I (Index) が接触しそうで怖い。
カプトンテープかなんかで絶縁した方がいいかも。

斬る前は保持力の低下が怖かった、IDC Socket のデータシートでその構造を見たところ、多少は大丈夫そうに感じたので、試しに斬ってみると思っていたよりしっかり保持できていたので、保持力の問題はこれでヨシ！

YazawaKenichi, 2022-03-09:
エンコーダを抜くときに持ち方を誤るとカバーがもげそうになる。
危ない。

Closed 2022-03-09.

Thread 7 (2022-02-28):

電源コードをどうにかしたい

YazawaKenichi, 2022-02-28:
XA コネクタ使ってつなげることを考えていたけど、そこまで大電流流すわけでもないから汎用ピンヘッダとピンソケット使えば、下手に高さが出ないし、見栄えもいいと思う。
ただ位置がずれているからどうにかして位置を修正する必要がある。
感光基板作ろうかな...

YazawaKenichi, 2022-03-09:
ユニバーサル基板と汎用ピンヘッダを使って電源接続をした。
高さが合っておらずピンヘッダが歪む。
ケーブルを直ではんだ付けした方が良いような気がする。

YazawaKenichi, 2022-03-09:
何度もコネクタを外して、取り付けてを繰り返したせいで電源ラインのランドがボロボロになり、電源が不安定になった。
やばい

YazawaKenichi, 2022-03-09:
他の issue にある通り、書き込みができなくなったので新しいメイン基板を作ることにした。
コネクタは設計当初の通り XA コネクタを使用する。
Power 基板の方は特に問題がないのでそのままケーブルにはんだ直付けの構成となっている。

Closed 2022-03-09.

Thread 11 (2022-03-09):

外部タイマの GND ピンと SW3 のピンが衝突している

YazawaKenichi, 2022-03-09:
確か玲於先輩は「バイパスするタイプだったら外部クロックは INPUT だけ繋いでおけば大丈夫。余った PH1 は別の機能に使えるよ。」とおっしゃっていた気がする。（今になって思えば俺の気のせい・聞き違い・勘違いかもしれない）
しかし実際にそれで Pinout & Configuration を決めると Clock Configuration で外部クロックが選択できなくなる。

YazawaKenichi, 2022-03-09:
実際に玲於先輩のやり方ができるのか、不明なので後々実験してみたい。
・外部クロックを使う場合は PH1 を GND に落とす
・使わない場合は PH1 を SW1 に接続し、内部クロックを用いる

YazawaKenichi, 2022-09-22:
SW3 を外し、マイコンとクロックを繋いだ

Closed 2022-09-22.

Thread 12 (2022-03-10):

細かい反省点

YazawaKenichi, 2022-03-10:
二階にはある電源 LED を一階にもつければよかった。
電源が一階にも供給されているかどうかわからん。
モータの Falut ピンの状態を見ることができる LED が付いていても良かった。

YazawaKenichi, 2022-04-21:
IDC コネクタの干渉
ガーバデータを吐くときに別々で作っていた基板をそのままコピペでまとめて塗りつぶししなおしてしまったせいで塗りつぶしのネットが ネットなし 扱いにされた。

Closed 2022-04-21.

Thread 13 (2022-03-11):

ADC が全部ゼロ

YazawaKenichi, 2022-03-11:
フォトセンサの抵抗値がでかすぎるのか？？？

YazawaKenichi, 2022-03-11:
これが設定
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

[これが問題となるソースコード](https://github.com/YazawaKenichi/Murakumo/blob/main/programs/%E6%A9%9F%E8%83%BD%E3%82%92%20ADC%20%E3%81%AB%E7%B5%9E%E3%81%A3%E3%81%9F%E3%83%97%E3%83%AD%E3%82%B0%E3%8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)

YazawaKenichi, 2022-03-11:
抵抗値を 0Ω, 5.1Ω, 51Ω, 510Ω, 5.1kΩ, 10kΩ, ∞Ω(open) にしたところ問題は何も変わらない。
相変わらず analog 配列の第一要素はゼロ以外、第二要素以降はゼロになる。

YazawaKenichi, 2022-03-11:
「analog 配列の第一要素はゼロ以外、第二要素以降はゼロになる。」というのはこういうこと

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

YazawaKenichi, 2022-03-11:
フォトトランジスタを二つつけなおしたら第一要素の値が極端に小さくなった。（但しそれ以外何も変わらない）
リセットするたびに値が変わることには変わりないし、第一要素以外は相変わらずゼロ。
（それと、値の幅が小さくなったせいか、第一要素がゼロになるパターンも観測できた。）

ただ、リセットする際にトランジスタに指を置いておくと決まった値が出るようになった。
これによって実はちゃんと ADC していたのではないかという希望が見えた。（いくらなんでも値が小さすぎるけど...

YazawaKenichi, 2022-03-14:
reo 先輩の助言をここにメモしておく。
・DMA Request Setting の Mode を Circular にする。
・analog 配列は uint16_t で定義されている -> ということは 4 byte なので、DMA Request Setting の Data Width を Word に変更する。
DMA Request Setting の Data Width は、文字通り DMA のデータの幅を表している。
このデータ幅が合っていないと正しく読み取れないことは当然である。
・Parameter Settings の Sampling Time を 56 Cycles にする。
Sampling Time はマイコンのピンの抵抗値によって適切な値を決めるらしい。

YazawaKenichi, 2022-03-14:
reo 先輩のアドバイスの通り設定したところ、値の変化は観測できた。
アナログピンの電圧を測ったところ、0.845V あることが分かった。
この値に 4096 / 3.3 をかけたところ、UART で表示された値に近い、1048 が出てきた。
素晴らしい！

YazawaKenichi, 2022-03-14:
しかし、reo 先輩のアドバイスの通り設定しても、「第一要素のみがゼロ以外」という出力に変わらなかった。
ADC ピンの電圧を読み取って、出力値がゼロになって当然かどうかについて判断したい。

そういえば少し話が戻って、 reo 先輩のアドバイスの前に、you ちゃんから「LED とフォトトランジスタの距離が狭すぎて直接光が入っているのでは？」という指摘をもらっていた。
この指摘の通りであれば、LED を外すかフォトトランジスタとの間に不透明な仕切りを設けることで、値がゼロ以外を指すはずである。

Closed 2022-03-15.

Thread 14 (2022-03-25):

LED の光がそのままフォトトランジスタに入ってる問題

YazawaKenichi, 2022-03-25:

YazawaKenichi, 2022-03-25:
黒い紙で光を遮ったときの値 (Rank 3 ~ 6 (16, 17, 20, 21 番ピン) (PA2, PA3, PA4, PA5) はセンサ未接続)
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

黒い紙で光を遮らなかったときの値 (Rank 3 ~ 6 (16, 17, 20, 21 番ピン) (PA2, PA3, PA4, PA5) はセンサ未接続)
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

黒い紙で光を遮ったときの値は、センサは空中を見ている。
黒い紙でセンサを遮らなかった時の値も、センサには空中を見せている。

値の差が大きいことから、やはり LED の光がそのまま直接センサに入っていることがわかる。

解決策として LED の光量を抑えるとよい。
そのために LED の電流制限抵抗をもっと大きくする必要があると思われる。(あんまり大きくしすぎると光らなくなるような気もするんだが、大丈夫だろうか...)

記録
このスクリーンショットを撮ったときは電流制限抵抗の値は 202 (2000 Ω)
フォトトランジスタのプルアップ抵抗の値は 563 (56 kΩ)

memo
Rank n => Channel (n - 1) => ADC1_IN (n - 1) => PA (n - 1)
∴ Rank n => PA (n - 1)
∴ Rank 3 ~ 6 => PA 2 ~ 5

YazawaKenichi, 2022-03-29:
抵抗値調整 一回目 (LED 103 (10 kΩ), PTr 563 (56 kΩ))
黒読み
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
白読み
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

YazawaKenichi, 2022-03-29:
右側のセンサ全てに白を見せた状態
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
左側のセンサ全てに白を見せた状態
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

PA2 ~ 5 は未接続であるため、leftmotor や rightmotor の値には反映されないようにしている。

YazawaKenichi, 2022-03-29:
この状態に於いて問題点は
- 白読み状態と黒読み状態で、Analog の値の差が小さすぎる。
- 一つのセンサが 白読みしているときの値を出しても、その値は他のセンサにとっては黒の値と言える状態ができてしまっている。
- 右側の方が配線が短いせいなのか、偶然センサの個体値的にそうなったのか、右側の方が常に大きい値を取ってくる。左側が大きくならないのでこのままでは左旋回ができない。

ひとまず LED の電流制限抵抗はもっと大きくしても良い気がするのでもっと大きな抵抗を入れてみる。
そのうえでもう一度値を読み直し、モータの動きがいい感じになったらそれ以上変更しない。
偏差が大きくなれば旋回できるようになると思う。（精度は別）

YazawaKenichi, 2022-03-29:
センサの抵抗値をもっと上げた。
具体的には 200kΩに変更。
結果的に左右の旋回ができるくらいにはなったので、いったんこれで進むのはアリ。
でもまだ LED の光が直接入っているような気はするし、偏差が弱すぎる気もする。
具体的なスクショはまた別のコメントとしてアップロードする。

YazawaKenichi, 2022-03-30:
全て白読みしたときの値
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
全て黒読みしたときの値
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

YazawaKenichi, 2022-03-30:
全黒から全白に移動したときのスクショ
桁が一つ変わってくれるのでこうやって見るとめちゃくちゃわかりやすい
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

YazawaKenichi, 2022-03-30:
RTr 302 にした。

全白
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

全黒
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

YazawaKenichi, 2022-04-05:
LED の抵抗 512 (5.1 kΩ)
全黒読み
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
全白読み
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

YazawaKenichi, 2022-04-05:
LED の抵抗値 132 (1.3 kΩ)
全黒読み
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
全白読み
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

YazawaKenichi, 2022-04-05:
基本 LED 1.3k PTr 3.0k
左から P1 ~ 12 と呼称
P2 ~ 3 の LED を (5.1 + 3.1) / 2 = 3.2 より 3.3k に変更
P10 ~ 12 の PTr を 3.0 * 2 = 6.0 より 6.2k に変更

結果

黒読み
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

白読み
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

抵抗値を上げすぎた感じがする。

YazawaKenichi, 2022-04-05:
上げすぎた抵抗値をもう少し下げた
P2 ~ 4, 6 LED (3.2 + 1.3) / 2 = 2.75 -> 2.7k
P10 ~ 12 PTr (6.0 + 3.0) / 2 = 4.5 -> 4.3k

result

black
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

white
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

P10 ~ 12 はいい感じ
P2 ~ 4, 6 をもう少し下げた方がいいかも
それと P5 も LED を少し下げた方がいいかも（これはまず P2 ~ 4, 6 を調整してからやる）

YazawaKenichi, 2022-04-05:
P2 ~ 4, 6 LED 2.0k

black
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

white
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

YazawaKenichi, 2022-04-05:
真ん中二つだけ白を読ませてモータ制御してみた。
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

まだ右が強い。

YazawaKenichi, 2022-04-05:
プログラム上で修正してみたり、いろいろ頑張ってみたけど値が変になってしまうので、結局プログラム上で修正が必要ならいっそのこと初めからプログラム上での修正を企んだ方がよさそう。

まずは LED を 一律 2k にしてみる。

YazawaKenichi, 2022-04-05:
センター白読み
LED 2k PTr 混合
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

YazawaKenichi, 2022-04-05:
PTr
P01 ~ 09 : 3.0k
P10 ~ 12 : P4.3k

YazawaKenichi, 2022-04-06:
PTr 一律 5.1k にしてみた。

YazawaKenichi, 2022-04-21:
抵抗値変えて抵抗値変えてを繰り返していたらきりがないので、プログラム上で制御することにした。
最終的に決まった抵抗値は後述するつもり。（覚えていれば...）

Closed 2022-04-21.

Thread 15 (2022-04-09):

センサの値にかかわらず左右のモータがプラスとマイナスを行き来する問題。

YazawaKenichi, 2022-04-09:
すぐに解決したのでスクショは撮っていない。

YazawaKenichi, 2022-04-09:
左センサの合計値を表す変数と、右センサの合計値を表す変数のを、タイマ開始時に初期化していなかった。
タイマを開始した際にゼロで初期化するようにしたら正しくプラスマイナスが計算できた。
また、真ん中だけに白を読ませているときは左右のモータの出力がほとんど等しい値になってくれていた。

Closed 2022-04-09.

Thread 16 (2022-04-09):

両サイド二つのセンサだけ値が常に 1000 になる。

YazawaKenichi, 2022-04-09:

YazawaKenichi, 2022-04-09:
最大値が最大値になっていなかった。

main 外で
uint16_t analogmax[CALIBRATIONSIZE] = {0};
としていたせいで実は初期化できていないパターンにハマっていた。

気づけた理由は、analogmin の方はちゃんと最小値していたことである。
既に main 外で
uint16_t analogmin[CALIBRATIONSIZE] = {4095};
が通用しないことを知っていたので、main の初め（タイマが起動する前）に for で 4095 に初期化するプログラムを作成していた。
もしやと思い、analogmax の方も main 内初めに for で初期化するプログラムに変更したところ正しく最大値を表示してくれた。

YazawaKenichi, 2022-04-09:
まずは両サイドが 1000 にしかならない問題を解決した。
しかし今度は両サイドが 1000 以外にもなるようになったが、1000 未満になってくれない。

計算式がおかしいのだろうか？
しかし両サイド以外のセンサは正しく動作できていることから、配列の操作の部分で何らかのエラーが起きているような気がする。

YazawaKenichi, 2022-04-09:
どこかで配列のループがおかしい位置にアクセスしているのかもしれない。

YazawaKenichi, 2022-04-10:
両サイドのセンサだけ計算結果が異常であることについての問題点に直接関係しているかどうか不明だが、改めてプログラムを見直したら不適切な式がいくつか見つかったので修正した。

具体的には

if(analogmax < analogbuf) analogbuf = analogmax;
となっていた。
これでは analogbuf の値が最大値に書き換わってしまう。
analogbuf = analogmax の式は左右が逆が正しい。
同様に analogbuf = analogmin となっていた。

また、analogmax < analogbuf の評価 else analogbuf < analogmin の評価 となっていたせいで、analogmax = analogbuf = analogmin の時の処理が analogmax = analogbuf のみになっており、analogmin が正しく設定できないことになっていた。

そして analograte の計算式も間違っていた。
analograte = (analog - analogmin) * 1000 / analogmax;
となっており、これだと analogmax の値が analogmin 基準になっていないので結局センサの個体差が現れるようになってしまっていた。
正しくは
analograte = (analog - analogmin) * 1000 / (analogmax - analogmin);
である。
また、この式では analogmax = analogmin となった時に 0 / 0 の不定形となってしまうので、正常動作させる際は
if(analogmin != analogmax)
{
    analograte = analog - analogmin) * 1000 / (analogmax - analogmin);
}
として動作させる必要がある。

まだ修正したプログラムを動作させていないのでこれですべての問題が解決するのかは不明。

YazawaKenichi, 2022-04-10:
試しにシミュレータを作ったところ、正しく動作できたので、実装してみる。

そのシミュレータがこれ
https://github.com/YazawaKenichi/Murakumo/blob/main/programs/analogratetester.cpp

YazawaKenichi, 2022-04-21:
プログラムを書き直したところ、正常動作したのでヨシ！

Closed 2022-04-21.

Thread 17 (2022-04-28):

サイドセンサが正常に動作しない

YazawaKenichi, 2022-04-28:
既に解決したが、一応記録を残しておく。

「正常に動作しない」とは、具体的に述べるとセンサの出力が常に high になっているという状態だった。

SH コネクタから電源を供給して信号線にテスタを繋いでみたところ、プルアップ抵抗があるので当然入力電圧に近い値が出ていた。

強力な赤外線を照射することが可能な装置を用いてセンサに赤外線を当ててみたところ、最大でも 1V 程度下がった。
しかしその程度で、low として読むにはまだ高い電圧であった。

パターンを見たところ、グランドのランドとビアが孤立していた。
KiCAD でベタグランドとして設定していた領域がネットなしとして登録されていたようである。
これはもともと別々のファイルで作っていた基板を、一つのファイルに統合した際に、塗りつぶし領域のネットが「ネットなし」として塗りつぶしの再実行がなされたためである。

案の定、（LED を一旦外して）センサの動作を先ほどの装置で確認したところ、正しく high と low を出力できていた。

===================================

次に、LED を付けてみると、センサの値が常に low になる現象が起きた。
これは LED の輝度が大きすぎて光が直接センサに入り込んでいることが原因であることが分かった。
LED を外すと正常動作する。LED とセンサの間に仕切りを作ると high になる。といったことから判断した。

あとは抵抗値を変えていき、白読みで low 黒読みで high となる抵抗値を発見した。

===================================

センサをはんだ付けする際に左右で高さが変わってしまった。
そのせいで LED に同じ抵抗を使っても左右で挙動が異なるものとなってしまった。

片方の抵抗値を変更することで対処した。

Closed 2022-04-30.

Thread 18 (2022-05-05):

サイドセンサが正しく読み取れない プログラム編

YazawaKenichi, 2022-05-05:
[Murakumo のサイドセンサプログラム](https://github.com/YazawaKenichi/Murakumo/blob/main/programs/README.md) これに従ってプログラムを実装した。

timer_1ms は TIM10 を使用する。
ここに追加で、正しく値を読めているか、UART で確認できるようにするために
```
subsensl = !HAL_GPIO_ReadPin(GPIOB, GPIO_PIN_11) ? 1 : 0;
subsensr = !HAL_GPIO_ReadPin(GPIOB, GPIO_PIN_2) ? 1 : 0;
```
を追記し、
```
int main()
{
    while(1)
    {
        printf("%5d, %5d\r\n", subsensl, subsensr);
    }
}
```
の一文を追加した。

YazawaKenichi, 2022-05-05:
ところが UART を見たところ、常に初期値が出力される。
初期値をゼロにすれば左右のセンサがゼロ扱いになる。
初期値をイチにすれば左右のセンサがイチ扱いになる。

サブセンサの LED は正しく白と黒を認識できていることから、TIM10 が機能しておらず、subsensl, subsensr の値が変化しないようになっていると思われる。

試しに TIM10 の処理を TIM6 (PID 処理のタイマ) に追記したところ、正常に動作した。

YazawaKenichi, 2022-05-05:
int main()
{
    HAL_TIM_Base_Start_IT(&htim10);
}
のようにタイマを追加した。

尚、 HAL_TIM_Base_Start_IT() と HAL_TIM_Base_Start() の二種類がある。
IT の方が割り込みのためのタイマとなる。
IT がないと、タイマを開始するだけで、割り込みは有効にならない。（どういうこっちゃ？）

YazawaKenichi, 2022-05-05:
脱線するが少し調べてみたところ
HAL_TIM_PWM_Start() と HAL_TIM_PWM_Start_IT() というのもあった。
こちらも IT の方には in interrupt mode とされていて、こちらの方が割り込みが有効になるっぽい。

YazawaKenichi, 2022-05-05:
[詳細は公式リファレンス](https://www.st.com/resource/en/user_manual/dm00105879-description-of-stm32f4-hal-and-ll-drivers-stmicroelectronics.pdf)

YazawaKenichi, 2022-05-05:
PWM 制御を HAL_TIM_PWM_Start_IT() にしたところ、センサの値に影響が出た。
具体的にはいずれかのセンサが時々ゼロを出し、センサの最小値が極めて低い状態になるようになった。
一体どうしてこのようなことになるのかはわからないが、HAL_TIM_PWM_Start_IT() は使用しないほうがよさそう。

YazawaKenichi, 2022-05-05:
IT の方でタイマをスタートしてみたが、残念ながらセンサに影響を与える挙動となった。

YazawaKenichi, 2022-05-05:
というか、そもそもプログラムが間違ってて思い通りの挙動をしてくれなかった。

YazawaKenichi, 2022-05-05:
とりあえずプログラムを書きなおす必要がありそう。

YazawaKenichi, 2022-05-05:
サイドセンサのプログラムどーしよー

YazawaKenichi, 2022-05-05:
とりあえず gcc で試作してみるはアリ

YazawaKenichi, 2022-09-22:
gcc でプログラムを試作し、サイドセンサの挙動を確実なものにした。

Closed 2022-09-22.

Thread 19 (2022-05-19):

処理速度が追い付かない

YazawaKenichi, 2022-05-19:
TIM6 に
- センサの値から左右の値の加算
- 左右の PID 制御
- サイドセンサの処理
を入れているせいで、処理が重すぎて途中で処理が止まってしまう。

YazawaKenichi, 2022-05-23:
どうして「処理速度が追い付いていない」と判断したのか。

まず、main while 内にサイドセンサの処理を入れた場合、正常に動作した。
ここにおける正常に動作したとは、スタートマーカは読み飛ばし、ゴールマーカは正しく読めてストップできるということである。
（ただ main while に置いているせいか、タイミングによってはスタートマーカを超えてからストップすることがある。）
それなのに TIM10 に入れると動作しないのである。つまり左右のセンサの変化を UART で見ることができない。

それともう一つ、サイドセンサのプログラムを入れるとモータがカチカチ音を鳴らす。
どうやら処理が追い付かないとそんな感じの挙動になるらしい。

YazawaKenichi, 2022-05-23:
TIM6 に入らないなら TIM10 に入れればいいじゃない！
ということで TIM10 に入れるのだが、TIM10 が動かないのである。謎。
TIM10 の処理に集中させるために、ほかのタイマの処理 if(htim->Instance == TIM*) の部分をすべてプリプロセッサレベルで消してみても、動かない。謎。

YazawaKenichi, 2022-05-23:
全てのタイマを無効にしてみたが何も起きなかった。
TIM10 を設定する項目として、HAL_TIM_Base_Start(&htim10); を登録する必要があったが、それを HAL_TIM_Base_Start_IT(&htim10); にしたところ、正しく動作した。

なのでプログラムを元に戻して動作させてみようと思う。

Closed 2022-09-22.

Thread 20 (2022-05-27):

CubeIDE から書き込みができてるんだかできてないんだかわからない

YazawaKenichi, 2022-05-27:
書き込みはできてそう？でも UART から出力文字が読めない。
どうしたものか

YazawaKenichi, 2022-05-27:
何をしたらこうなったのか

ローカル上にある Murakumo のプロジェクトファイルを D ドライブに移動してそこからプロジェクトを立ち上げて書き込みをするようにした。

YazawaKenichi, 2022-05-27:
バージョンを戻したりしていろいろ試していたところ、プロジェクト名と ioc のファイル名が異なっているせいで ioc が開けないというバージョンを見つけた。

YazawaKenichi, 2022-05-27:
これを以て、もしやと思い、最新バージョンに戻して、プロジェクト名を ioc のファイル名に一致させたところ、問題なく書き込めた。

YazawaKenichi, 2022-05-27:
個人的にも「いや、ほかの人はそんなんならんし」と思うが、もし万が一、僕と同じ思考回路を持った人が困った時のために、残しておく。（その時にこの issue にたどり着くのかどうかはわからんけど...）

Closed 2022-05-27.

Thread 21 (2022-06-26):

エンコーダの値を読んで移動距離を計算したいんだけど、なんだかおかしい。

YazawaKenichi, 2022-06-26:
エンコーダの値を読むのは大丈夫。
エンコーダの値の差を取ってパルス数をカウントするのも大丈夫。
問題なくできた。
しかしパルス数から変位に換算するときになんだかおかしなことになる。
比例定数として用意された static const unsigned long long int LENGTHPERPULSE が常に 1073815628 という値になる。
どんなに計算式を変えても常にこの値を取る。

YazawaKenichi, 2022-06-26:
予想

変数宣言と同時に値の代入はできないのかもしれない。
そのせいで変な値が入ってしまっている状態。
-> 解決方法 static const を解除し、unsigned int 型で LENGTHPERPULSE を定義する。
     main の上の方で数式を代入する。

YazawaKenichi, 2022-06-26:
結果

上記の方法で対処した結果、39 という値が代入された。
これは、Ubuntu 上で等価プログラムを実行したときの値と一致しているため、正しく計算されていると言える。

YazawaKenichi, 2022-06-26:
実際に走行距離を計算させてみたが、合っているか合っていないかの判断ができない。
どうにかしたい。

YazawaKenichi, 2022-09-22:
エンコーダの値から速度を計算する -> 21 * M_PI だけ（タイヤ一回転分の距離）進んだら止まる
というプログラムを実装し、一回転でぴったり止まるように LENGTHPERPULSE を調整した。
結果、```LENGTHPERPULSE = 21000 * M_PI * / 65536 * 6.7448f``` になった。

しかし、このまま止まる距離を二回転分にしたら、二回転より少し手前で止まった。
は？？？？？？？？？

YazawaKenichi, 2022-09-22:
### はいはいはーい！対処法分かりました！
- エンコーダモードに設定しているタイマーの ```Counter Period``` を ```( エンコーダの分解能 ) - 1``` にする。
- ソースファイルの ```Pulse / Rotate``` を ```( エンコーダの分解能 )``` にする。
- ソースファイルの ```( エンコーダの中央値 )``` を ```( エンコーダの分解能 ) / 2``` にする。
上記三つが間違っていた故に、すべてがずれていた。
以下の計算式は正しかった。
- ```( １パルスで進む距離 ) = ( タイヤ直径 ) * ( 円周率 ) / ( n 逓倍 ) / ( エンコーダの分解能 )```
- ```( ギア比 ) = ( ピニオンギアの歯数 ) / ( スパーギアの歯数 )```
- ```( 速度 ) = ( エンコーダの値の変化量 ) * ( 1 パルスで進む距離 ) * ( ギア比 )

この状態で一回転させてみたところぴったり一回転した。

Closed 2022-10-10.

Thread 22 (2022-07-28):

速度制御できてるのかできてないのかわからん

YazawaKenichi, 2022-07-28:
速度制御ができているかどうかの判断方法。

・お絵描き台車を作った時のことを思い出せ。ペットボトルを押させるんだよ！
これでまずプログラム自体が間違っていないかどうかがわかる。
・n 秒経ったら止まるプログラムを作れ。開始地点から止まったところまでの距離を測れば速度がわかる！
これでゲイン値が正しいかどうかがわかる。

YazawaKenichi, 2022-07-28:
////////// エンコーダを処理するタイマ //////////

// エンコーダを止める
HAL_TIM_Encoder_Stop(Left);
HAL_TIM_Encoder_Stop(Right);

// 中央値からの距離を計算する
short int encoder_l = TIM1->CNT - ENCODER_MIDDLE;
short int encoder_r = - (TIM3->CNT - ENCODER_MIDDLE);

// エンコーダのカウントを中央値に戻す
TIM1->CNT = ENCODER_MIDDLE;
TIM3->CNT = ENCODRE_MIDDLE;

// エンコーダをスタートさせる
HAL_TIM_Encoder_Start(Left);
HAL_TIM_Encoder_Start(Right);

// エンコーダのカウントを速度に換算する
int velocity_l = encoder_l * LENGTHPERPULSE;
int velocity_r = encoder_r * LENGTHPERPULSE;
// 目的の速度との偏差を計算する
int velocity_error_l = (VELOCITY_TARGET - velocity_l);
int velocity_error_r = (VELOCITY_TARGET - velocity_r);

// PI 制御
int velocity_next_l = VKPL * velocity_error_l;
int velocity_next_r = VKPR * velocity_error_r;

// 次の速度を PWM Duty 比に変換してモータの処理タイマに渡す
// ここでの commonspeed が、コースのステートによる曲率変化に応じた変量。
int nextspeed_left = COMMONSPEED + velocity_next_l * PWMMAX / VELOCITY_MAX / VELOCITY_CONTROL_RATE;
int nextspeed_right = COMMONSPEED + velocity_next_r * PWMMAX / VELOCITY_MAX / VELOCITY_CONTROL_RATE;

YazawaKenichi, 2022-07-28:
////////// モータを処理するタイマ //////////

// エンコーダ処理タイマから値を引き継ぐ
int leftmotor = nextspeed_left + ;
int rightmotor = nextspeed_right;

// commonspeed の方向に応じてゲインの正負を変更する。
if(nextspeed_left > 0)
{
	leftmotor = nextspeed_left + direction / CALIBRATIONSIZE / 2 * kpl + (direction - beforedirection) * kdl;
}
else
{
	leftmotor = nextspeed_left - direction / CALIBRATIONSIZE / 2 * kpl - (direction - beforedirection) * kdl;
}
if(nextspeed_right > 0)
{
	rightmotor = nextspeed_right - direction / CALIBRATIONSIZE / 2 * kpr - (direction - beforedirection) * kdr;
}
else
{
	rightmotor = nextspeed_right + direction / CALIBRATIONSIZE / 2 * kpr + (direction - beforedirection) * kdr;
}

YazawaKenichi, 2022-07-28:
エンコーダのタイマ処理の中にローパスフィルタを導入したい。

台車の速度制御プログラム

double low_pass_filter(double val, double pre_val, double gamma)
{
    return gamma * pre_val + (1.0 - gamma) * val;
}

// speed_left が現在のエンコーダから計算した生の速度で、引数にある speed_left_lpf が一周前の lpf を通した速度
// 現在の速度
speed_left_lpf = low_pass_filter(speed_left, speed_left_lpf, 0.4);

YazawaKenichi, 2022-07-28:
velocity_l_raw = encoder_l * LENGTHPERPULSE;	// mm/s
		velocity_r_raw = encoder_r * LENGTHPERPULSE;
		velocity_l = LPF(velocity_l_raw, velocity_l, 0.4);
		velocity_r = LPF(velocity_r_raw, velocity_r, 0.4);

YazawaKenichi, 2022-07-28:
こんなふうに改造した。
velocity_l_raw がエンコーダから計算した生の速度。
LPF 関数を通すことで ノイズを軽減した速度が velocity_l に入る。

#define LPF int low_pass_filter(int val, int pre_val, unsigned short int gamma)
LPF
{
return (gamma * pre_val + (1000 - gamma) * val) / 1000
}

YazawaKenichi, 2022-08-03:
一旦整理する

YazawaKenichi, 2022-08-03:
この issues の最終目標は、速度制御をすること。

「速度制御できている」の判定基準は以下の通り

1. 目標速度ゼロにしたとき、手で引っ張っても元の位置に戻ろうとする力が働く（P ゲインの同定）
2. 元に戻ろうとする力を押しのけて無理やりロボットを動かしたとき元の位置に戻ろうと走る（I ゲインの同定）
3. 目標速度を任意の速度にして、任意の秒数後にストップするプログラムを組んだ時、計算通りの距離にストップしたかどうか（ゲインが適切であることの証明）

YazawaKenichi, 2022-08-05:
現状
ライントレースは場合によってする。（詳細後述）
速度制御もできる。
でも両方合わせると突然変な動きをする。

ライントレースだけのプログラムにしたときに、変なところでライントレースすることがある。
左右二番目と三番目の間で白黒をまたぐように動くことがある。

原因と考えられること
根本原因かどうかは判断できないが、とにかく見つけたエラーは排除するべき。
変なところでライントレースする理由として、アナログの配列の順番を間違えている可能性がある。

YazawaKenichi, 2022-08-05:
改善方法として、アナログ配列の順番とその場所を改めて見直す必要がありそう。

YazawaKenichi, 2022-08-07:
アナログ配列の順番を見直したところ、変なところでライントレースすることはなくなった。

Closed 2022-09-22.

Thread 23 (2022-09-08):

ライントレースの PID ゲインを調整する。

YazawaKenichi, 2022-09-08:
・探索するときの速度が遅いので速くする。
・先輩からのアドバイスとして、まず 1000 mm/s の等速で一周できないとこの後二次走行するときにうまくいかなくなる。（なぜ？）

-> まずは 1000 mm/s の等速で一周できるようにする。

そのための PID ゲインをこれから調整していく。
その時に PID のゲイン値と実際の挙動の様子をメモしておきたかったので、issue としてここに残す。

YazawaKenichi, 2022-09-08:
KP = 5
I 制御みたいな低周期発振した。もっと上げていい。
KP = 30
ラインにぴったり合わせてスタートさせてもすぐにコースアウトする。
KP = 10
30 のときよりかはマシだが、それでもちょっと進むとコースアウトする。
もう少し下げても良いかも。

YazawaKenichi, 2022-09-08:
KP = 6.25
少し追い付かなさがあるか、外に逃げる。もっと上げていい。
KP = 8.75
なんだか惜しい。
KP = 7.5
もっと惜しい。

7.5 前後を攻めてみる。

YazawaKenichi, 2022-09-08:
KP = 6,75, 7.25, 7.75, 8.25
直線でラインを追いきれてない気がする。
直線からの急カーブを試したところこの中で 8.25 が一番追い付けてる気がした。
もっと上げても良いのかも

YazawaKenichi, 2022-09-08:
KP = 8.45, 8.65, 8.85, 9.05
で試してみたところ、直線ですら走り切れてない。
下げていいかも。

YazawaKenichi, 2022-09-08:
今更気づいたことが一つある。
```
#define KP1
#define KP2
#define KP3
#define KP4
```
のところで値を決めていたが、実際にゲインは KP1 や KP2 の値から計算して KP3, KP4 が決まっていた。
つまりこれまでに使っていた KP3 と KP4 の値は全く参考にならない。
カス

YazawaKenichi, 2022-10-10:
ただ D ゲインが大きいことが理由なのか、走行時の音は非常にうるさい。

Closed 2022-10-10.

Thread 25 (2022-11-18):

Analog の入力電圧がなんだかおかしい

YazawaKenichi, 2022-11-18:
具体的な症状
- DMA で取得してきた AD 変換後の値の振れ幅は、センサにもよるが、広いものはおよそ 80 ~ 3500 と、かなり幅がある
- この差は白の上か黒の上かに関係なく振れるが、頻度は 3500 の方が多く見える
- ソートさせた後の最大値と最小値を表示させたところ、0 ~ 64000 の最小値と最大値があったことになっていた

YazawaKenichi, 2022-11-18:
これらのことから、原因はソートの段階にあるのでは...？これらのことから、原因はソートの段階にあるのでは...？```
void analog_get_and_sort()
{
    uint16_t analogbuffers[SENSGETCOUNT][CALIBRATIONSIZE];
    /* sort */
    if(sensgettime >= SENSGETCOUNT)
    {
        sensgettime = 0;
        for(unsigned char index = 0; index < CALIBRATIONSIZE; index++)
        {
            /* main sort */
            for(unsigned char count = 0; count < SENSGETCOUNT; count++)
            {
                for(unsigned char alphaindex = 0; alphaindex > count; alphaindex--)
                {
                    uint16_t analogbuffer = analogbuffers[alphaindex - 1][index];
                    analogbuffers[alphaindex - 1][index] = analogbuffers[alphaindex][index];
                    analogbuffers[alphaindex][index] = analogbuffer;
                }
            }

            /* get middle */
            analog[index] = analogbuffers[(int) SENSGETCOUNT / 2][index];

            /* get max and min */
            if(analog_read_analogmode() == calibrating)
            {
                analogmax[index] = (analogmax[index] < analog[index]) ? analog[index] : analogmax[index];
                analogmin[index] = (analogmin[index] > analog[index]) ? analog[index] : analogmin[index];
            }
        }
    }

    /* get sensor raw value */
    for(unsigned char index = 0; CALIBRATIONSIZE > index; index++)
    {
        analogbuffers[sensgettime][index] = analograw[index];
    }
    sensgettime++;
}
```

YazawaKenichi, 2022-11-18:
初めに `uint16_t analogbuffers[SENSGETCOUNT][CALIBRATIONSIZE];` をしていたことで、初期値が異常な状態も含めてソートしていたことが原因となった。

試しに該当の宣言式をグローバル変数にしたとき、正常にソートは動作し、最大値と最小値も正しく出力された。

よってこの問題は解決された。

Closed 2022-11-18.

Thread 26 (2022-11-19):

モータが回らない（絶対ソフトが原因）

YazawaKenichi, 2022-11-19:
最新の UART 出力が以下（ switch enable 後 ）
```
tim10_start()
tim6_start()
analog_set_from_flash()
flash.analogmin[ 0] =  3336, flash.analogmax[ 0] =  3380
flash.analogmin[ 0] =  3336, flash.analogmax[ 0] =  3380
flash.analogmin[ 1] =  3581, flash.analogmax[ 1] =  3626
flash.analogmin[ 1] =  3581, flash.analogmax[ 1] =  3626
flash.analogmin[ 2] =  3130, flash.analogmax[ 2] =  3177
flash.analogmin[ 2] =  3130, flash.analogmax[ 2] =  3177
flash.analogmin[ 3] =  3355, flash.analogmax[ 3] =  3399
flash.analogmin[ 3] =  3355, flash.analogmax[ 3] =  3399
flash.analogmin[ 4] =  3206, flash.analogmax[ 4] =  3256
flash.analogmin[ 4] =  3206, flash.analogmax[ 4] =  3256
flash.analogmin[ 5] =  3331, flash.analogmax[ 5] =  3438
flash.analogmin[ 5] =  3331, flash.analogmax[ 5] =  3438
flash.analogmin[ 6] =  3250, flash.analogmax[ 6] =  3298
flash.analogmin[ 6] =  3250, flash.analogmax[ 6] =  3298
flash.analogmin[ 7] =  2782, flash.analogmax[ 7] =  2922
flash.analogmin[ 7] =  2782, flash.analogmax[ 7] =  2922
flash.analogmin[ 8] =  3471, flash.analogmax[ 8] =  3525
flash.analogmin[ 8] =  3471, flash.analogmax[ 8] =  3525
flash.analogmin[ 9] =  3061, flash.analogmax[ 9] =  3202
flash.analogmin[ 9] =  3061, flash.analogmax[ 9] =  3202
flash.analogmin[10] =  3276, flash.analogmax[10] =  3328
flash.analogmin[10] =  3276, flash.analogmax[10] =  3328
flash.analogmin[11] =  3433, flash.analogmax[11] =  3482
flash.analogmin[11] =  3433, flash.analogmax[11] =  3482
flash.analogmin[12] =  2369, flash.analogmax[12] =  2412
flash.analogmin[12] =  2369, flash.analogmax[12] =  2412
flash.analogmin[13] =  1840, flash.analogmax[13] =  1885
flash.analogmin[13] =  1840, flash.analogmax[13] =  1885
flash.analogmin[14] =  1228, flash.analogmax[14] =  1274
flash.analogmin[14] =  1228, flash.analogmax[14] =  1274
flash.analogmin[15] =  1247, flash.analogmax[15] =  1290
flash.analogmin[15] =  1247, flash.analogmax[15] =  1290
analog_start()
analog_sensor_start()
sensgettime = 0
HAL_ADC_Start_DMA()
velotrace_start()
samplingtime = 1, s_error = 0, before_error = 0
pid = velotrace_read_gain
pid = velotrace_read_target
tracer_start()
[tracer.c] > sampling_time = 1, s_error = 0, before_error = 0
pid = tracer_read_gain
pid = target
motor_start()
HAL_TIM_PWM_Start, motor_enable(1)
d_print()
switch_read_enter() = 1
rotary_read() =  0
```

YazawaKenichi, 2022-11-22:
`motor_set()` の引数に値を入れても `printf()` で引数の値が出力されなかった。

```
/* 別ファイル */
void motor_set(double left_, double right_)
{
    /// left_, right_ の正負に応じてモータの回転方向を決めるプログラムは省略
    /// left_, right_ がマイナスならプラスにするプログラムは省略
    /// left_, right_ が 1000 を超えたら頭打ちにさせるプログラムは省略
    /// 緊急停止フラグによる停止プログラムは省略

    printf("%7.2f, %7.2f\r\n", left_, right_);

    __HAL_TIM_SET_COMPARE(&htim4, TIM_CHANNEL_1, left_);
    __HAL_TIM_SET_COMPARE(&htim4, TIM_CHANNEL_2, right_);
}

/* main.c */
void main( void )
{
    /// 省略
    while(1)
    {
        /// 省略
        left = 5000;
        right = 5000;
        motor_set(left, right);
        /// 省略
    }
}
```

YazawaKenichi, 2022-11-22:
解決した。

原因は、`printf()` 直前の緊急停止プログラムの条件式を間違えていて常に緊急停止状態になっていたことが原因だった。

Closed 2022-11-22.

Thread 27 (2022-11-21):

エンコーダの左右の値がおかしい

YazawaKenichi, 2022-11-21:
UART 出力は以下の通り
```
motor_start()
main_d_print
tim10.c > tim10_d_print() > encoder_length_left() = 0.00000, encoder_length_right() = 12885.43862, encoder_length() = 6442.71931
tim10_d_print() > velocity_left =   0.000, velocity_right =  12.885, velocity =   6.443
tim10_d_print() > length_left =   0.000, length_right = 89437829.449, length = 44718914.725
main_d_print
tim10.c > tim10_d_print() > encoder_length_left() = 0.00000, encoder_length_right() = 12885.43862, encoder_length() = 6442.71931
tim10_d_print() > velocity_left =   0.000, velocity_right =  12.885, velocity =   6.443
tim10_d_print() > length_left =   0.000, length_right = 97516999.463, length = 48758499.731
main_d_print
tim10.c > tim10_d_print() > encoder_length_left() = 0.00000, encoder_length_right() = 12885.43862, encoder_length() = 6442.71931
tim10_d_print() > velocity_left =   0.000, velocity_right =  12.885, velocity =   6.443
tim10_d_print() > length_left =   0.000, length_right = 105583284.038, length = 52791642.019
main_d_print
tim10.c > tim10_d_print() > encoder_length_left() = 0.00000, encoder_length_right() = 12885.43862, encoder_length() = 6442.71931
tim10_d_print() > velocity_left =   0.000, velocity_right =  12.885, velocity =   6.443
tim10_d_print() > length_left =   0.000, length_right = 113675339.490, length = 56837669.745
main_d_print
tim10.c > tim10_d_print() > encoder_length_left() = 0.00000, encoder_length_right() = 12885.43862, encoder_length() = 6442.71931
tim10_d_print() > velocity_left =   0.000, velocity_right =  12.885, velocity =   6.443
tim10_d_print() > length_left =   0.000, length_right = 121754509.504, length = 60877254.752
```

YazawaKenichi, 2022-11-22:
** この `issue` は [murakumo_ws](https://github.com/YazawaKenichi/murakumo_ws/issues/1) に引き継ぎました **

Closed 2022-11-22.

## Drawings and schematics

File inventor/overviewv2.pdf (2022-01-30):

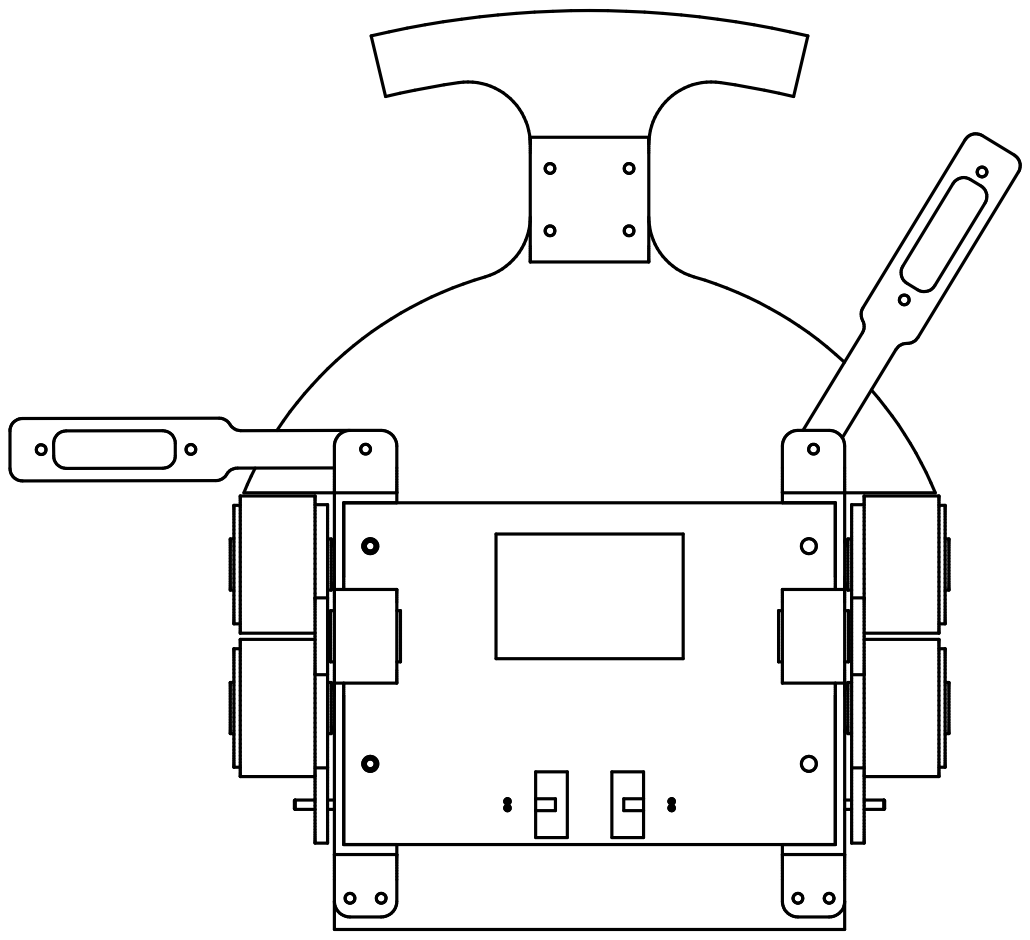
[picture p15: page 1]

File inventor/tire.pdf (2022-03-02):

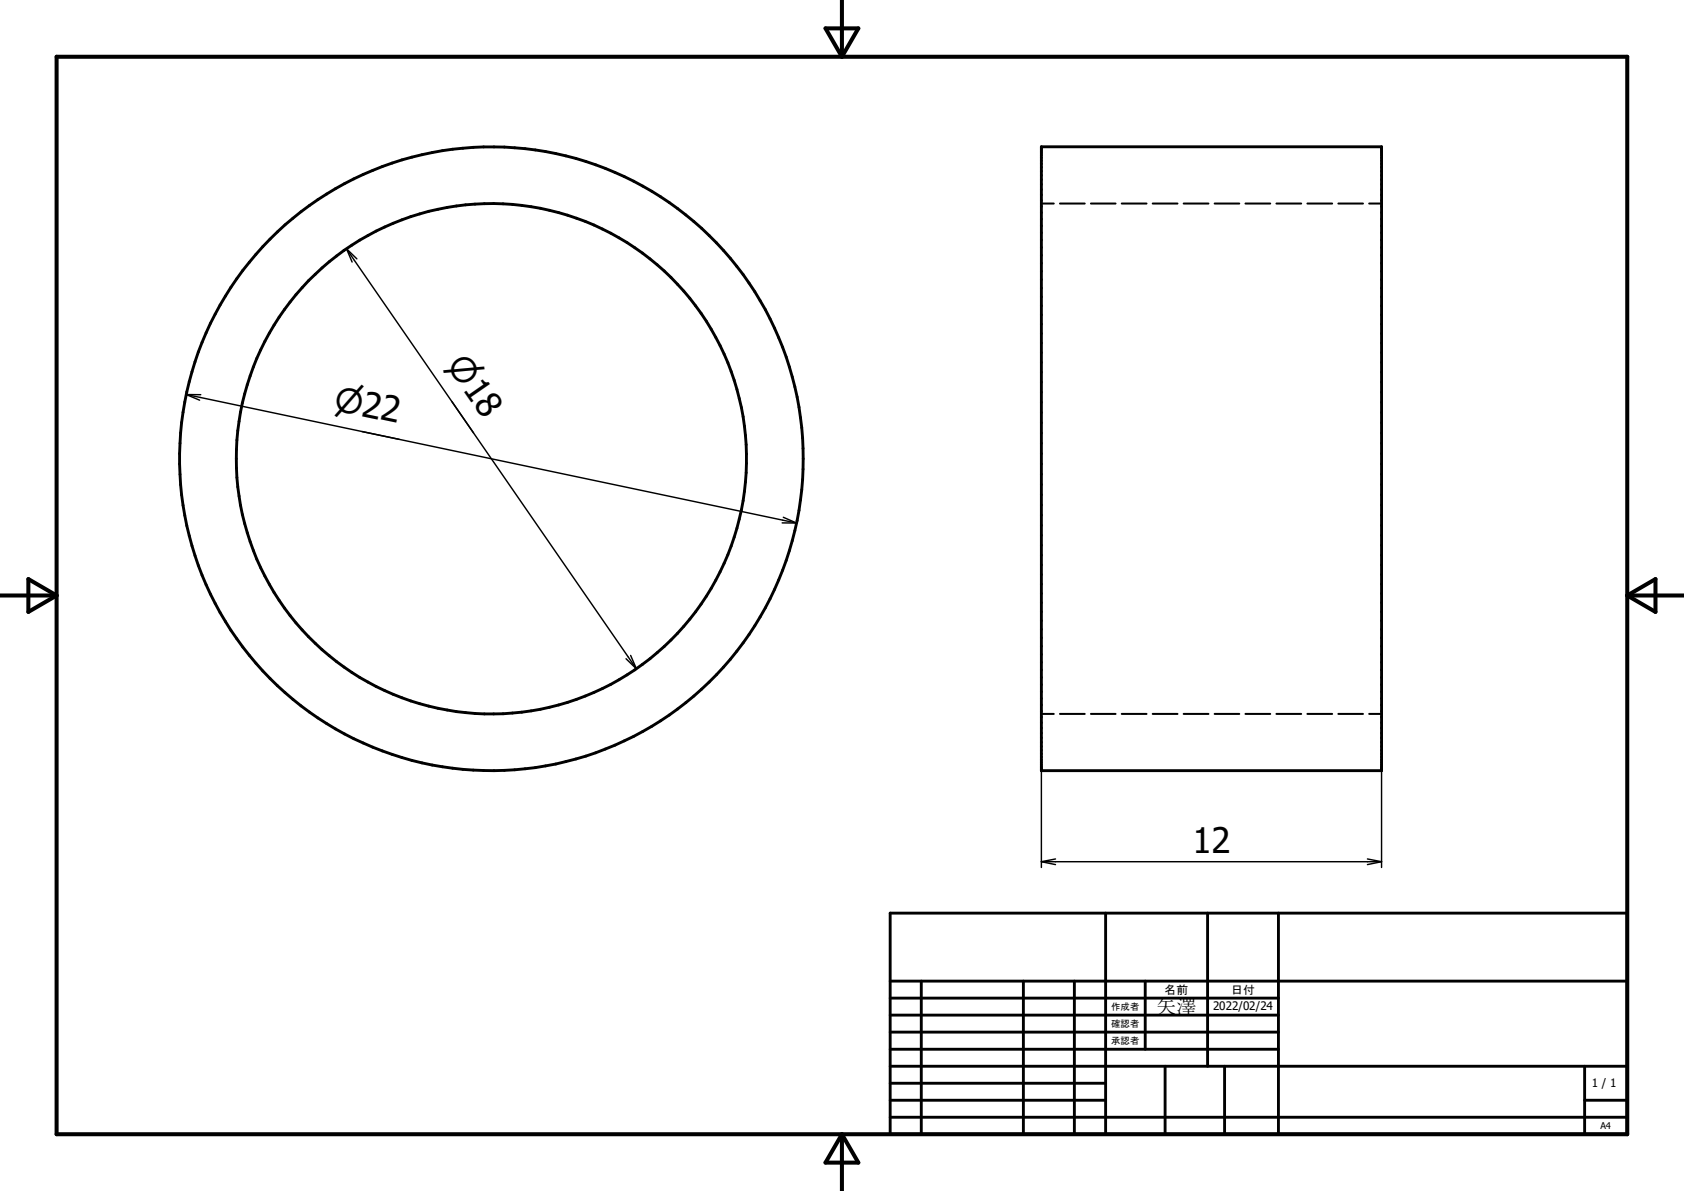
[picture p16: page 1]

作成者 | 矢澤 | 2022/02/24

確認者
承認者

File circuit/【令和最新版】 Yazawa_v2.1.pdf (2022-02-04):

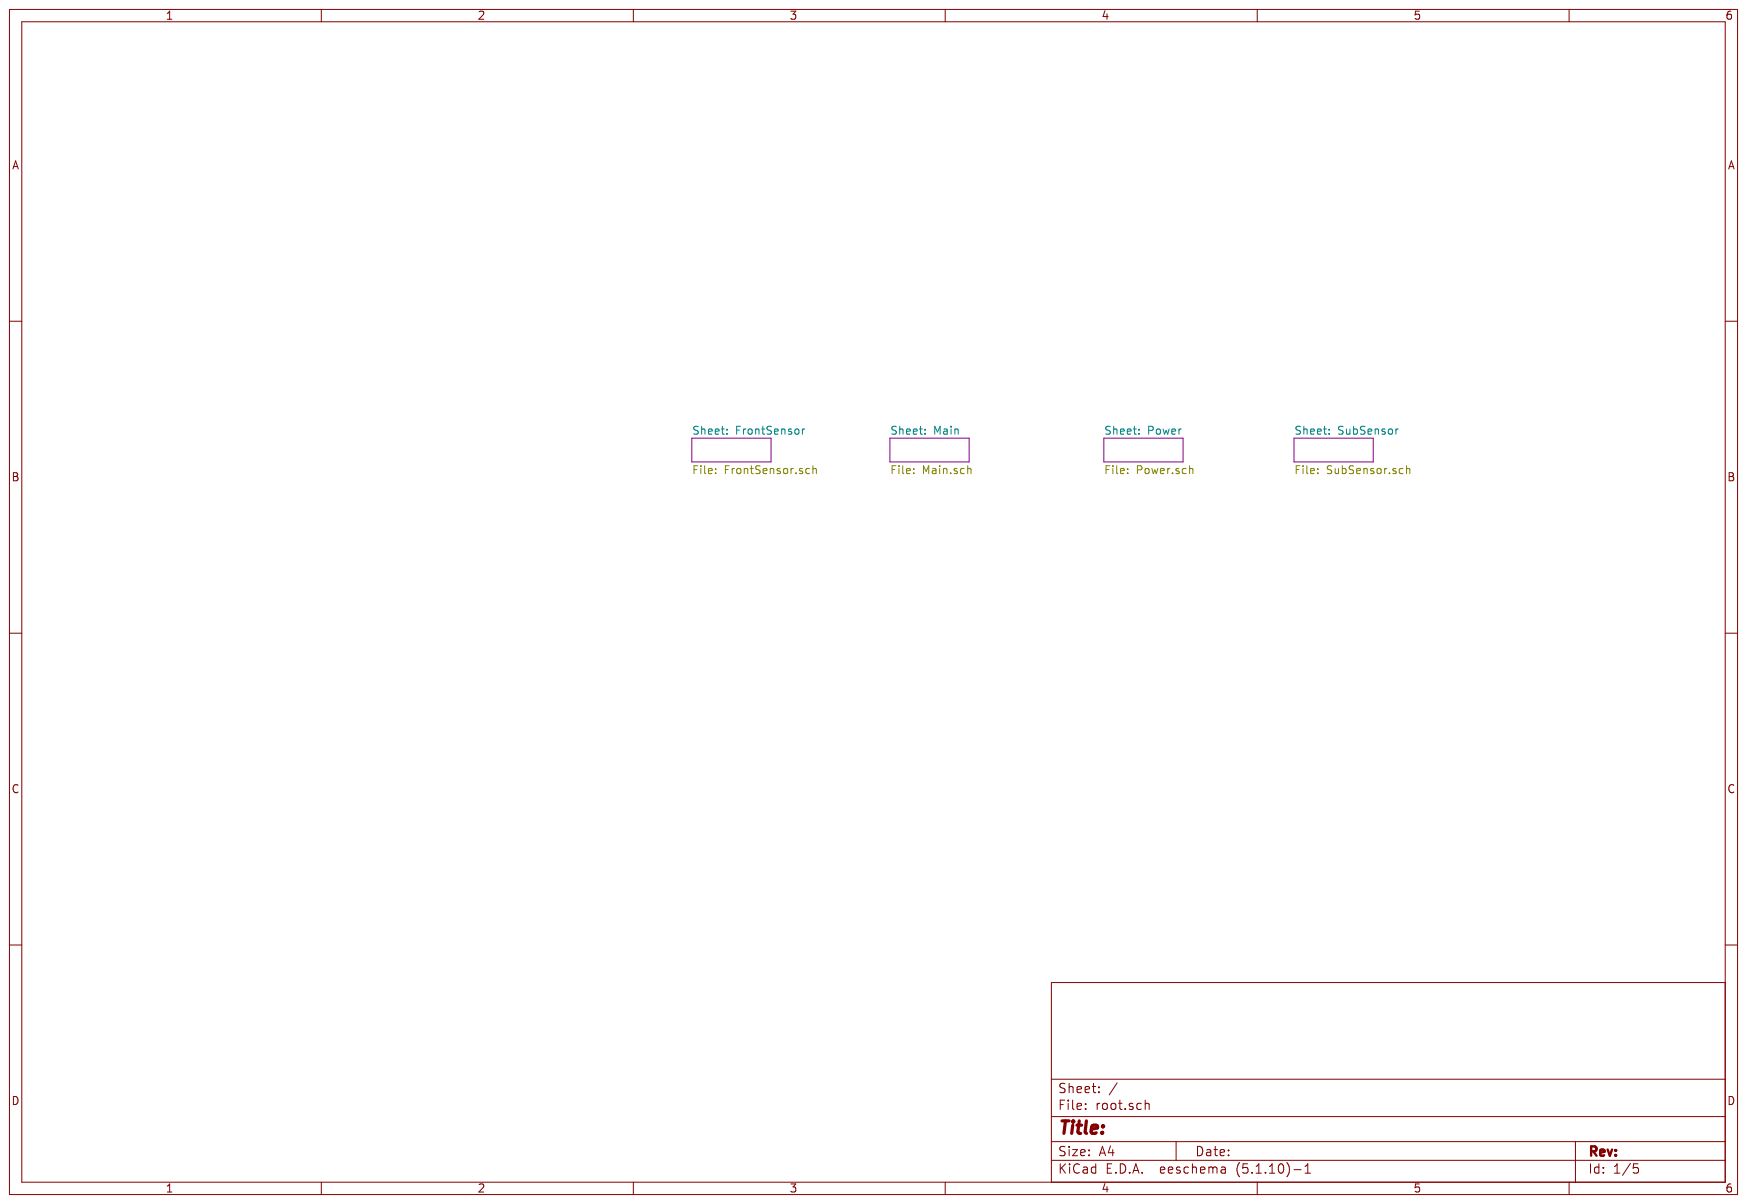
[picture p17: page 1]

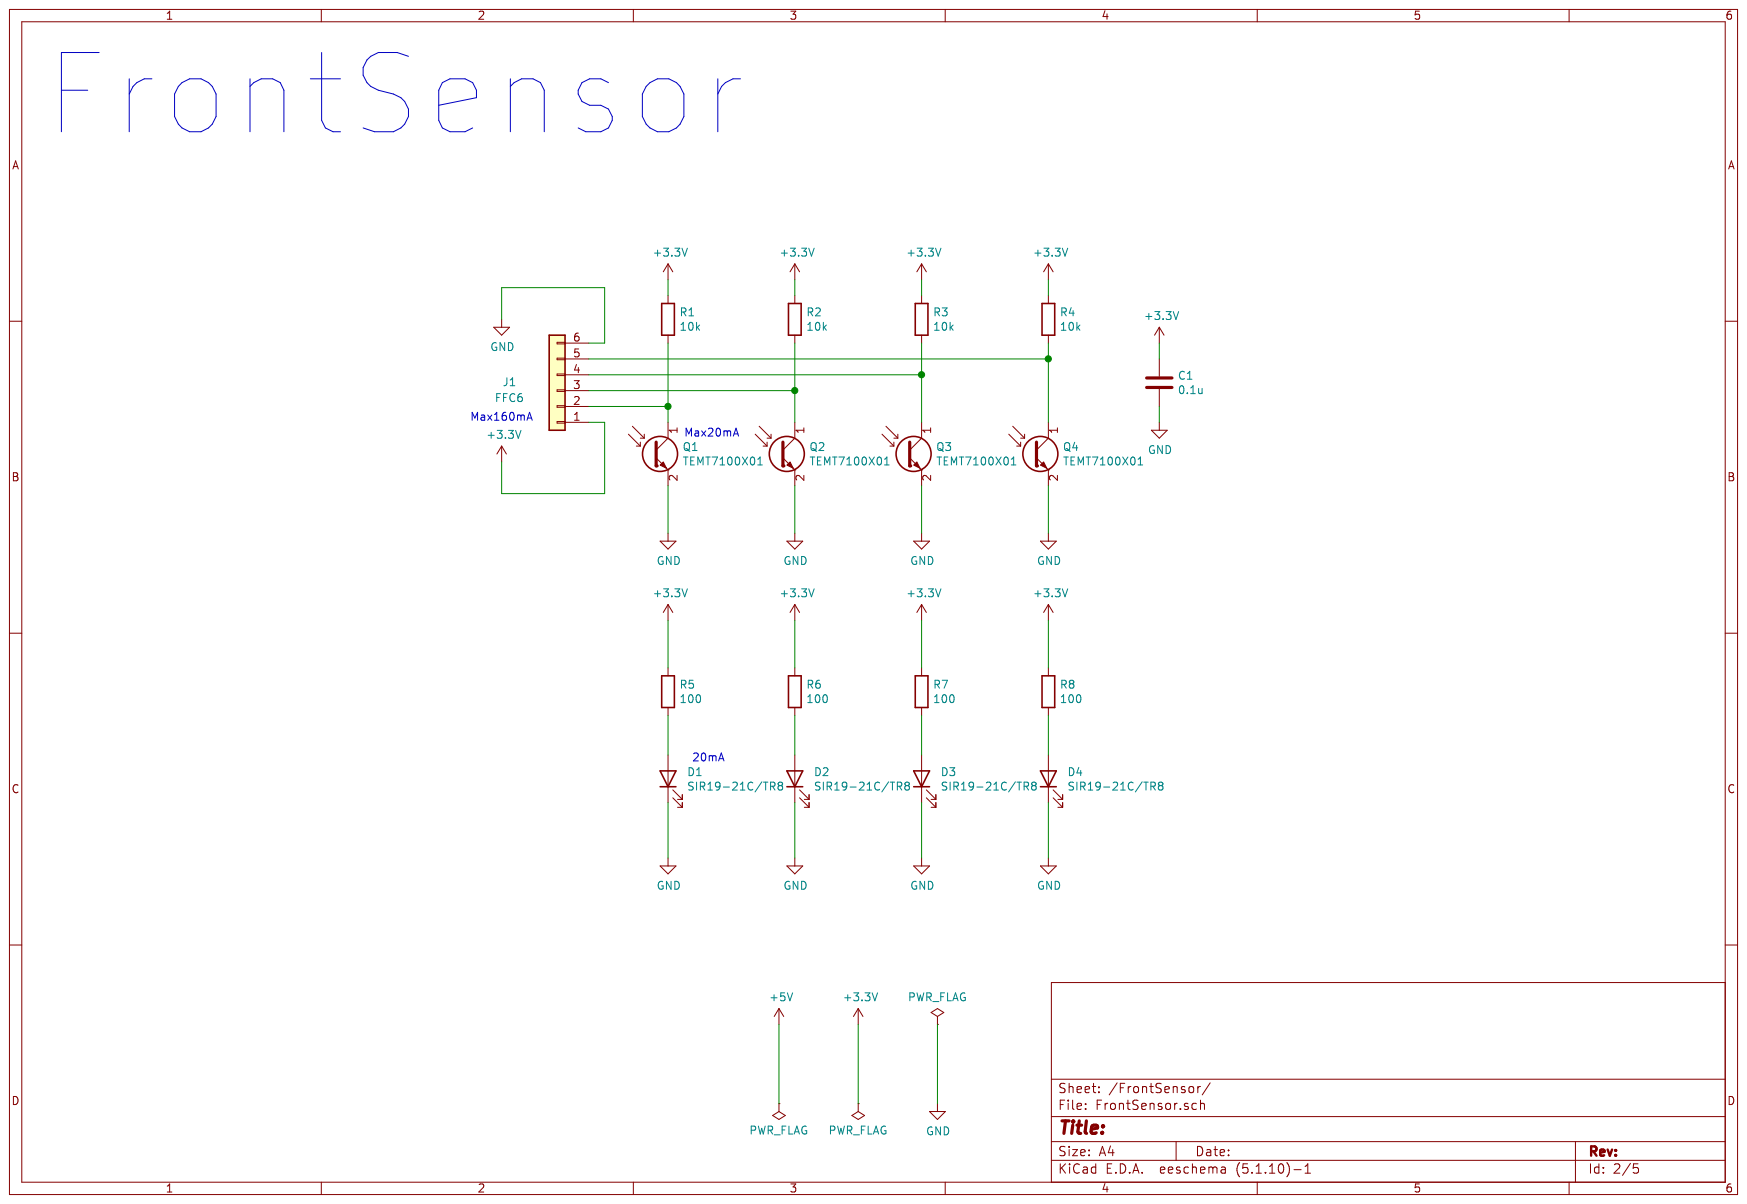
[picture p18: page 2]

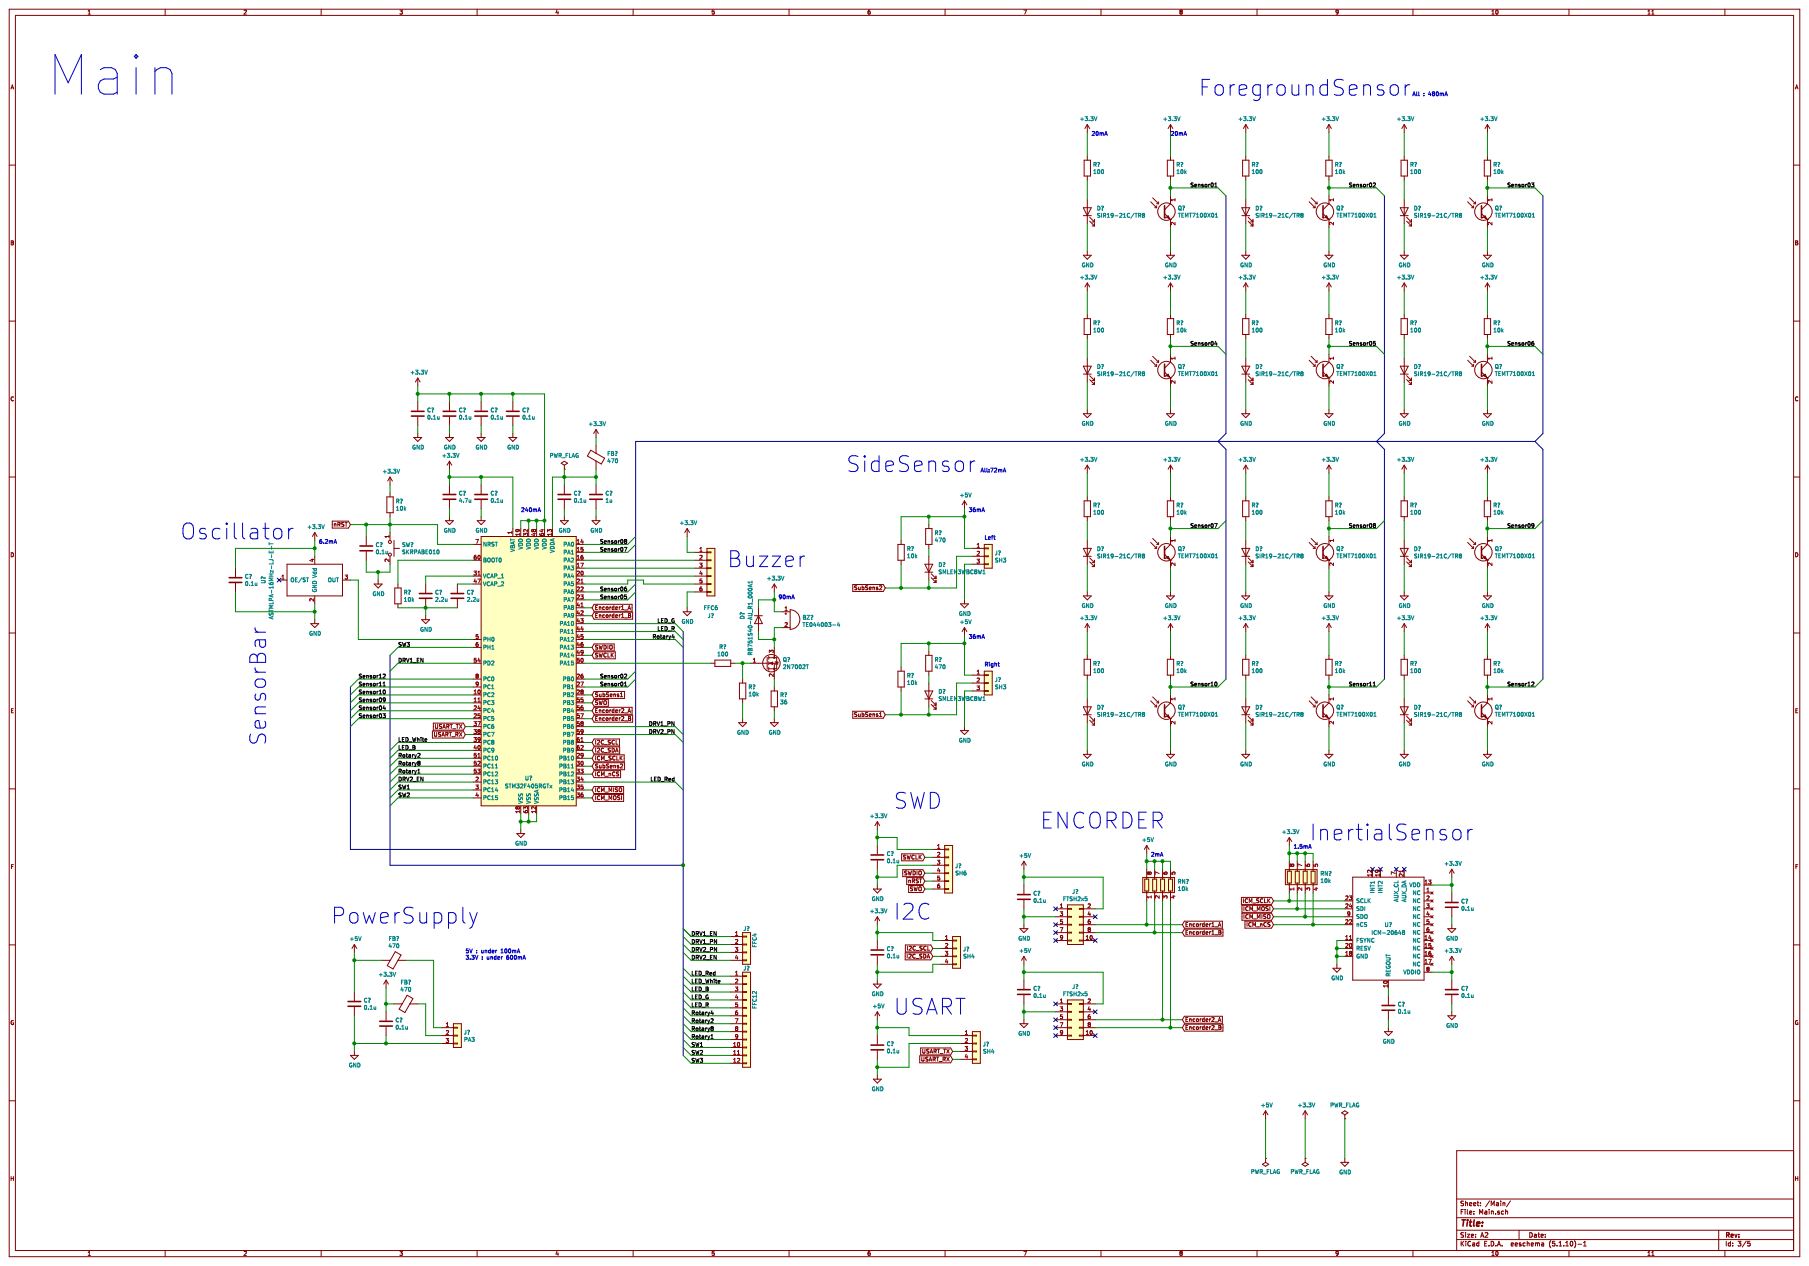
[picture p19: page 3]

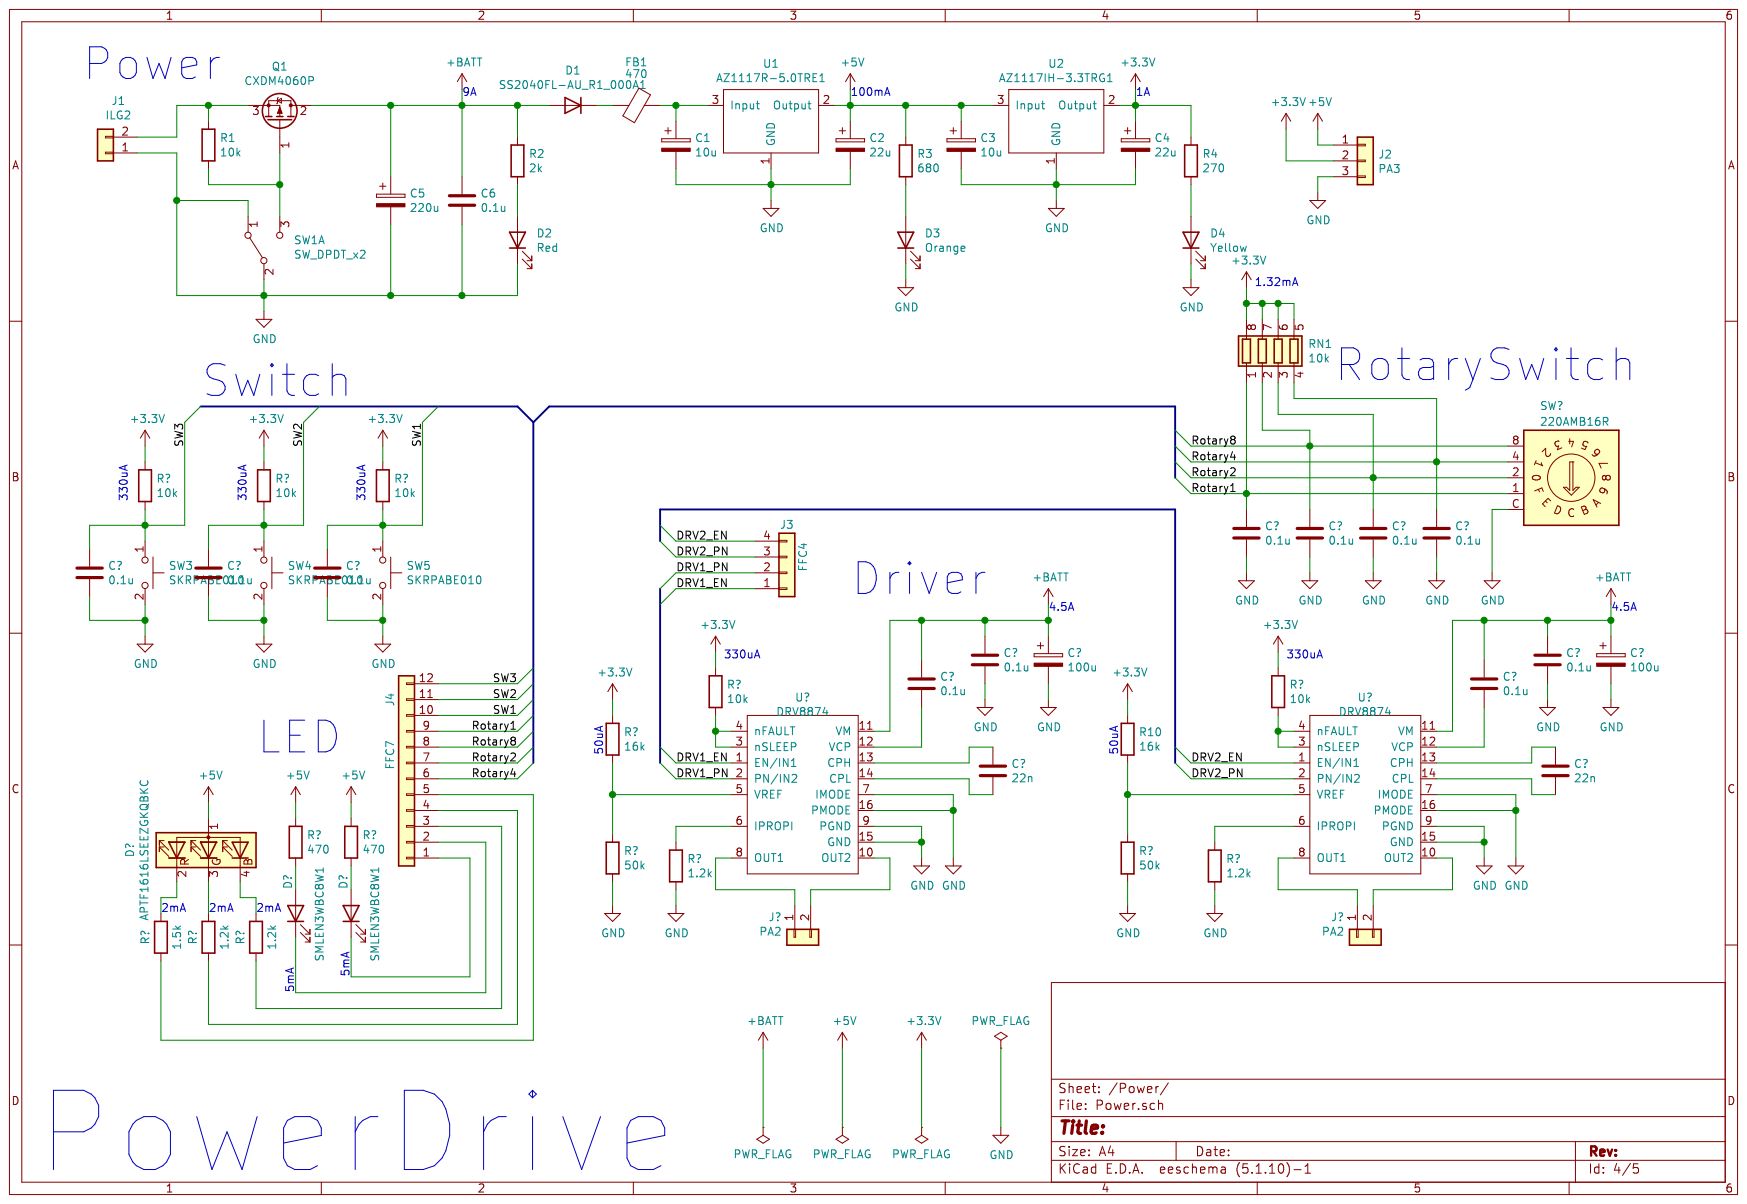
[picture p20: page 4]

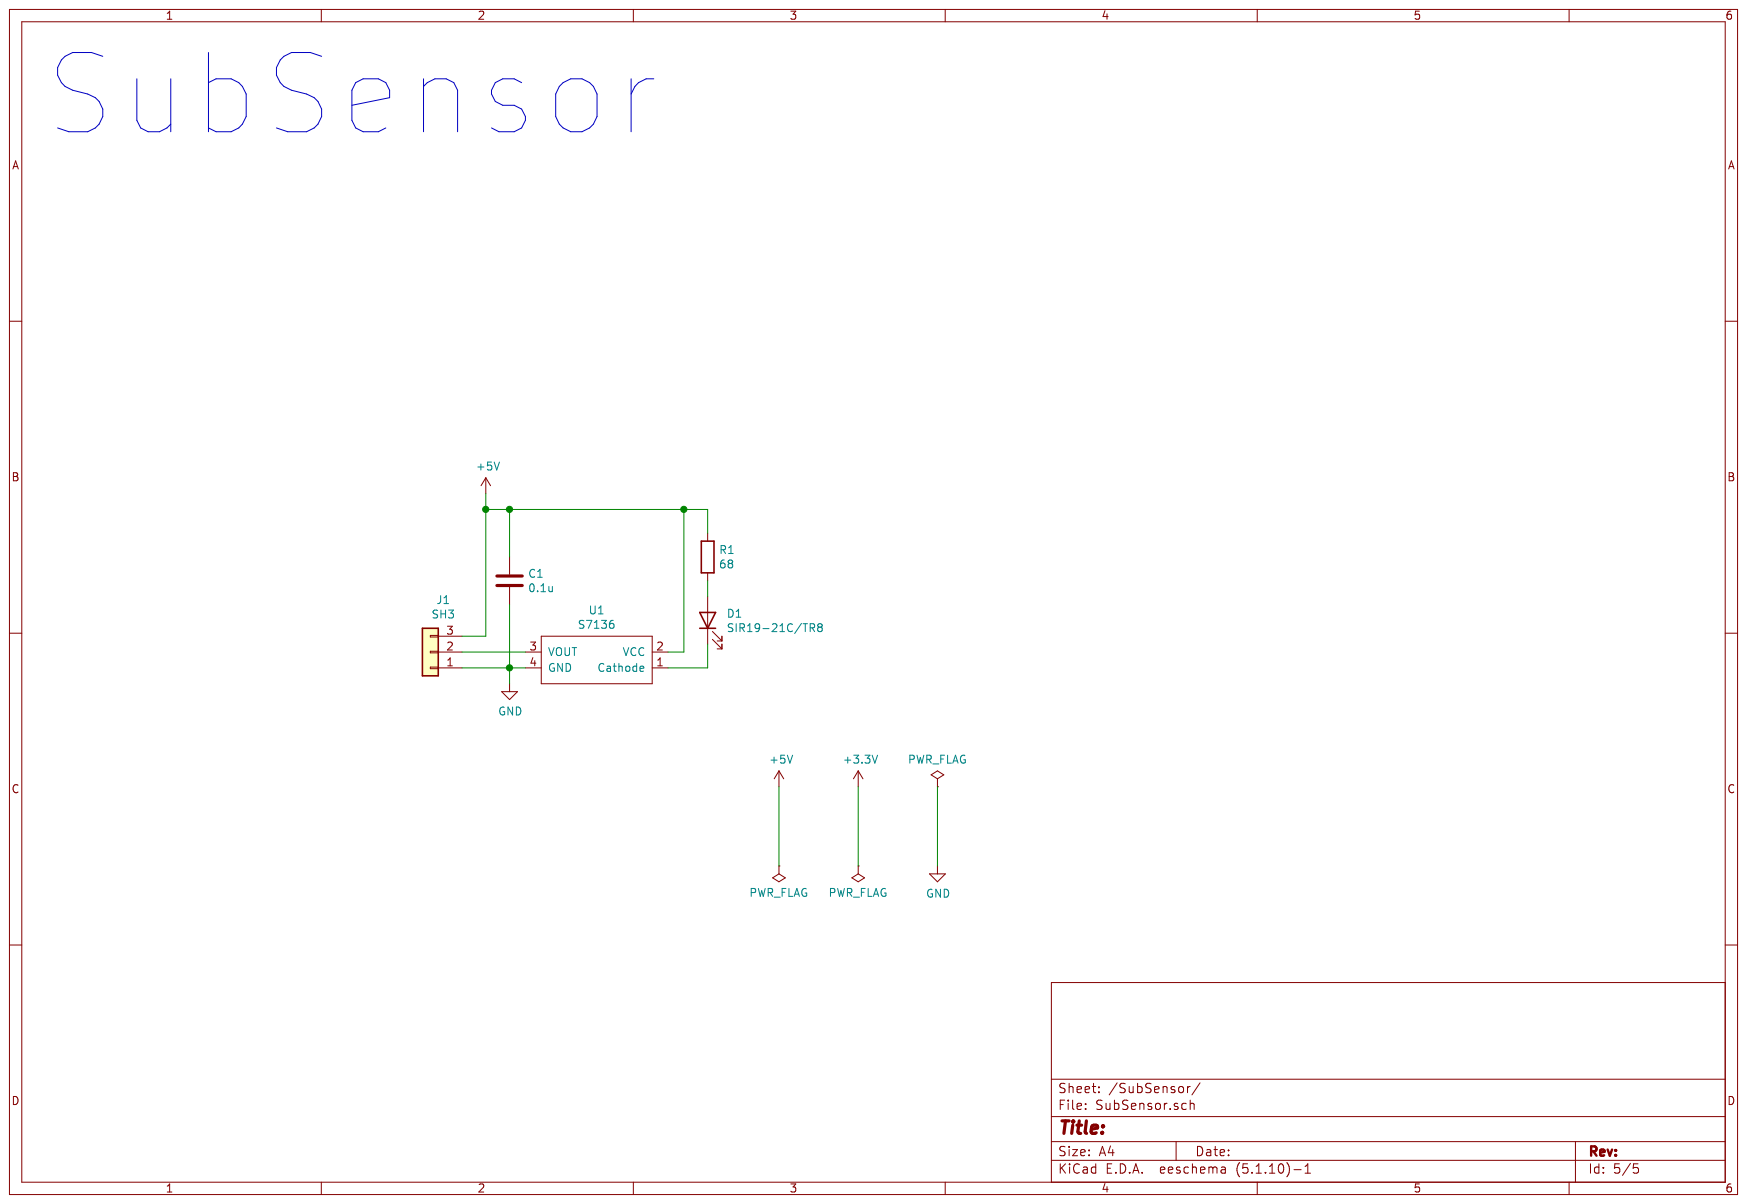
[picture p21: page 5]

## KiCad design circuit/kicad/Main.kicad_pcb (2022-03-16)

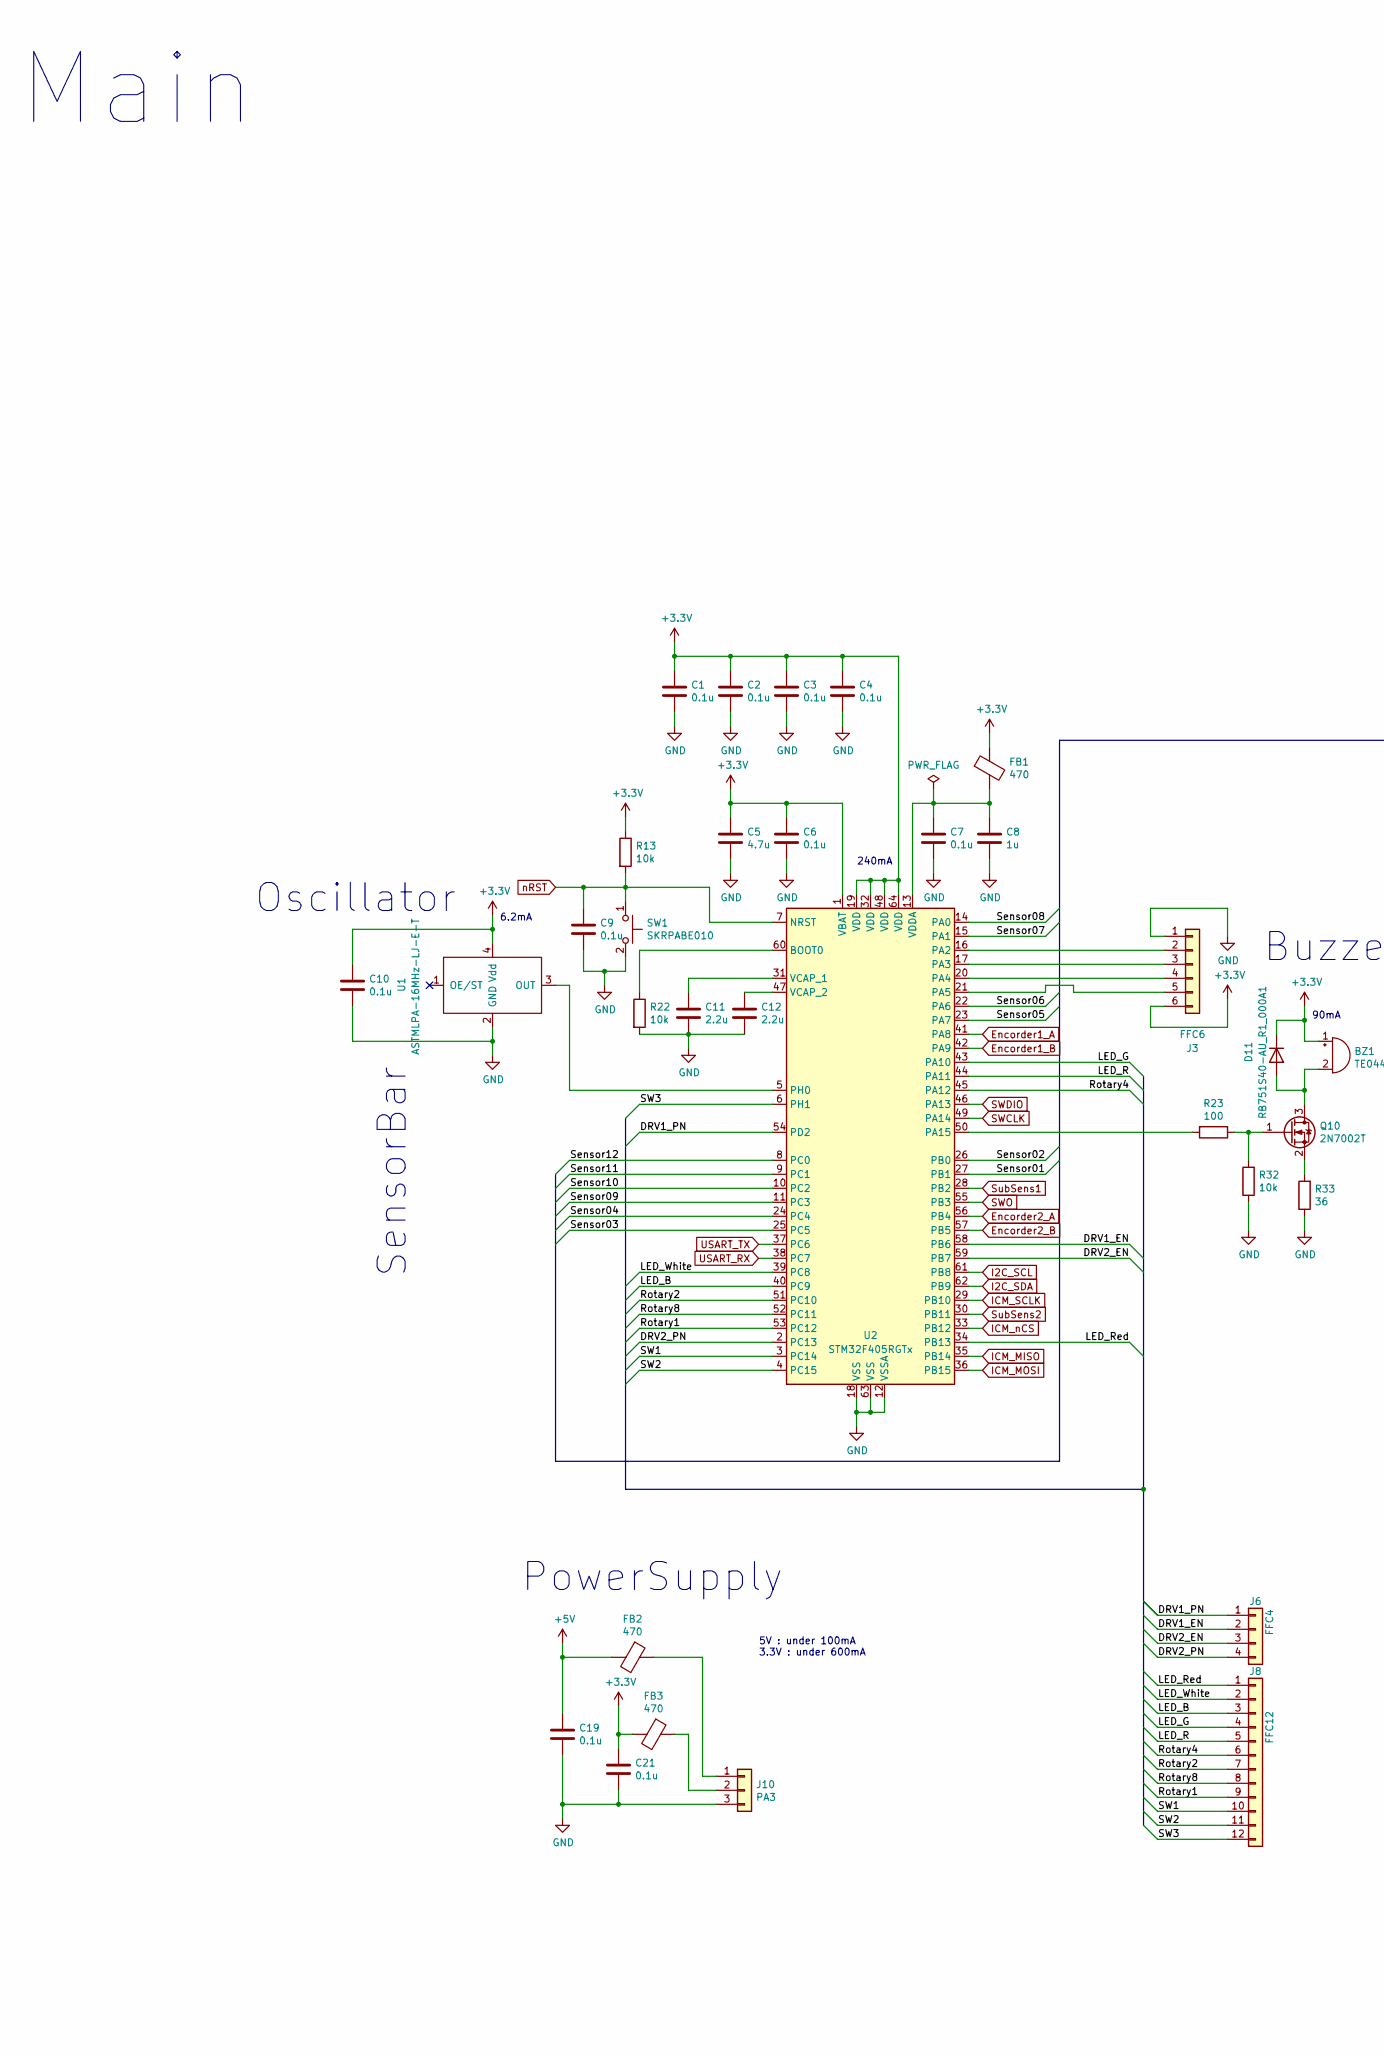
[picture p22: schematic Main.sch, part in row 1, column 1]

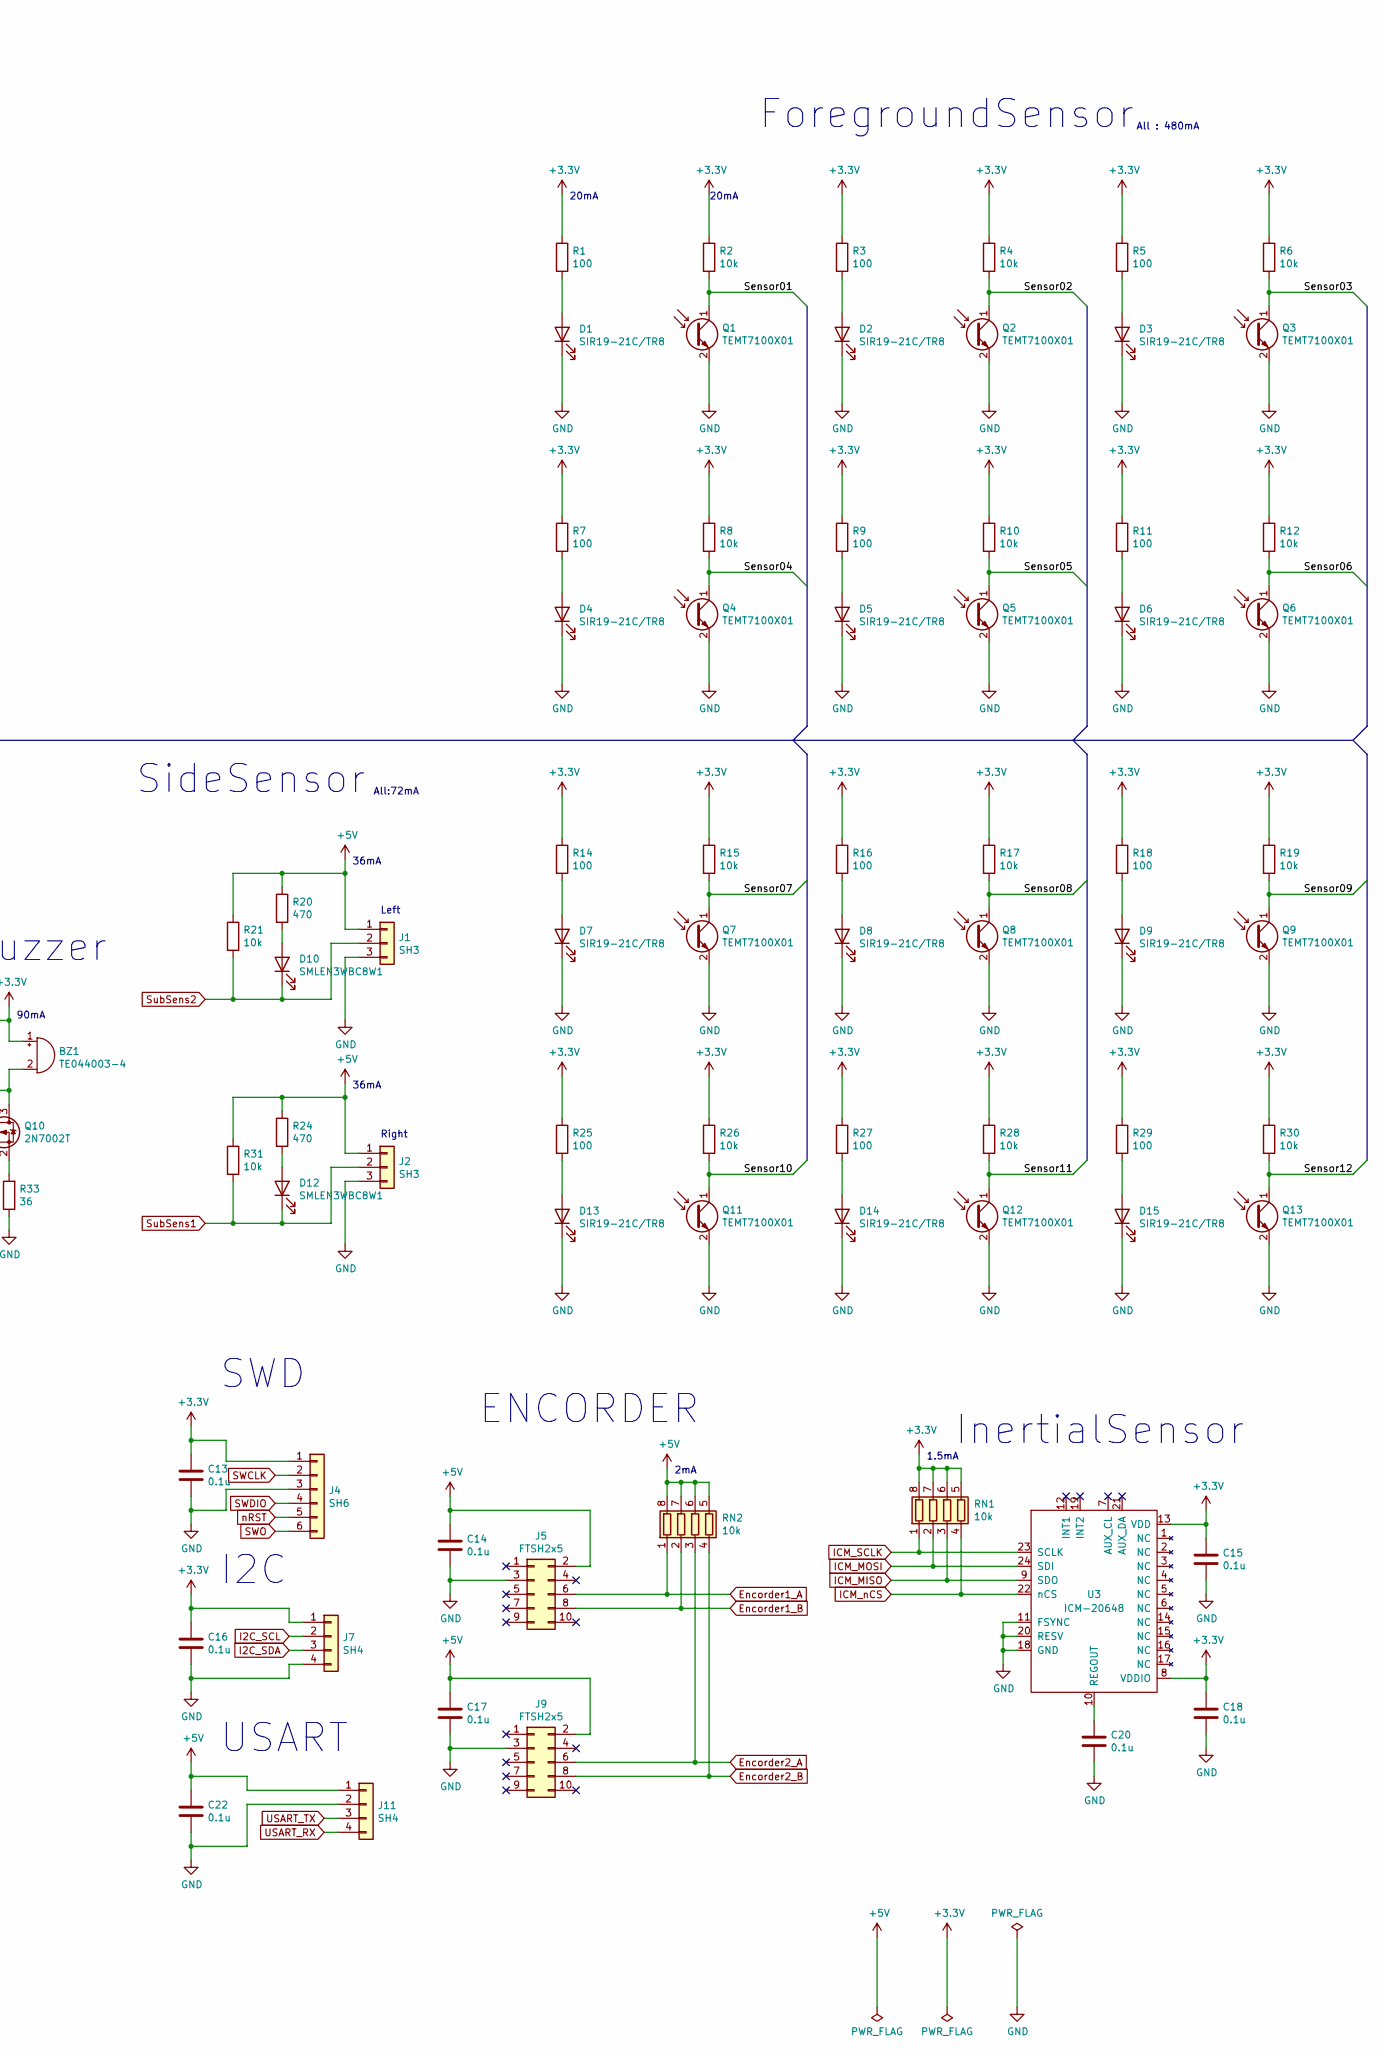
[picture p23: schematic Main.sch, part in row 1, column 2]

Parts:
BZ1: TE044003-4
C1, C2, C3, C4, C6, C7, C9, C10, C13, C14, C15, C16, C17, C18, C19, C20, C21, C22: 0.1u; C_0603_1608Metric
C5: 4.7u; C_0603_1608Metric
C8: 1u; C_0603_1608Metric
C11, C12: 2.2u; C_0603_1608Metric
D1, D2, D3, D4, D5, D6, D7, D8, D9, D13, D14, D15: SIR19-21C/TR8; D_0603_1608Metric
D10, D12: SMLEN3WBC8W1; D_0603_1608Metric
D11: RB751S40-AU_R1_000A1; SOD-523
FB1, FB2, FB3: 470; L_0603_1608Metric
J1, J2: SH3; SH_01x03
J3: FFC6; Molex_0545480671_01x06_P0.5mm
J4: SH6; SH_01x06
J5, J9: FTSH2x5; SAMTEC_FTSH-105-01-L-D-K
J6: FFC4; Molex_200528-0040_1x04-1MP_P1.00mm_Horizontal
J7, J11: SH4; SH_01x04
J8: FFC12; WürthElektronik_687112183722_01x12_P0.5mm
J10: PA3; PA_01x03
Q1, Q2, Q3, Q4, Q5, Q6, Q7, Q8, Q9, Q11, Q12, Q13: TEMT7100X01
Q10: 2N7002T; SOT-523
R1, R3, R5, R7, R9, R11, R14, R16, R18, R23, R25, R27, R29: 100; R_0603_1608Metric
R2, R4, R6, R8, R10, R12, R13, R15, R17, R19, R21, R22, R26, R28, R30, R31, R32: 10k; R_0603_1608Metric
R20, R24: 470; R_0603_1608Metric
R33: 36; R_0603_1608Metric
RN1, RN2: 10k; SOIC-8_3.9x4.9mm_P1.27mm
SW1: SKRPABE010
U1: ASTMLPA-16MHz-LJ-E-T; ASTMLPA-16.000MHz-LJ-E-T
U2: STM32F405RGTx; LQFP-64_10x10mm_P0.5mm
U3: ICM-20648; QFN-24-1EP_3x3mm_P0.4mm_EP1.75x1.6mm

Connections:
+3V3: BZ1.1 (-), C1.1, C2.1, C3.1, C4.1, C5.1, C6.1, C10.1, C13.1, C15.1, C16.1, C18.1, C21.1, D11.1 (K), FB1.1, FB3.2, J3.6, J4.1, J7.1, R1.1, R2.1, R3.1, R4.1, R5.1, R6.1, R7.1, R8.1, R9.1, R10.1, R11.1, R12.1, R13.1, R14.1, R15.1, R16.1, R17.1, R18.1, R19.1, R25.1, R26.1, R27.1, R28.1, R29.1, R30.1, RN1.5 (R4.2), RN1.6 (R3.2), RN1.7 (R2.2), RN1.8 (R1.2), U1.4 (Vdd), U2.1 (VBAT), U2.19 (VDD), U2.32 (VDD), U2.48 (VDD), U2.64 (VDD), U3.8 (VDDIO), U3.13 (VDD)
+5V: C14.1, C17.1, C19.1, C22.1, FB2.2, J1.1, J2.1, J5.2, J9.2, J11.1, R20.1, R21.1, R24.1, R31.1, RN2.5 (R4.2), RN2.6 (R3.2), RN2.7 (R2.2), RN2.8 (R1.2)
/DRV1_EN: J6.2, U2.58 (PB6)
/DRV1_PN: J6.1, U2.54 (PD2)
/DRV2_EN: J6.3, U2.59 (PB7)
/DRV2_PN: J6.4, U2.2 (PC13)
/LED_B: J8.3, U2.40 (PC9)
/LED_G: J8.4, U2.43 (PA10)
/LED_R: J8.5, U2.44 (PA11)
/LED_Red: J8.1, U2.34 (PB13)
/LED_White: J8.2, U2.39 (PC8)
/Rotary1: J8.9, U2.53 (PC12)
/Rotary2: J8.7, U2.51 (PC10)
/Rotary4: J8.6, U2.45 (PA12)
/Rotary8: J8.8, U2.52 (PC11)
/SW1: J8.10, U2.3 (PC14)
/SW2: J8.11, U2.4 (PC15)
/SW3: J8.12, U2.6 (PH1)
/Sensor01: Q1.1 (C), R2.2, U2.27 (PB1)
/Sensor02: Q2.1 (C), R4.2, U2.26 (PB0)
/Sensor03: Q3.1 (C), R6.2, U2.25 (PC5)
/Sensor04: Q4.1 (C), R8.2, U2.24 (PC4)
/Sensor05: Q5.1 (C), R10.2, U2.23 (PA7)
/Sensor06: Q6.1 (C), R12.2, U2.22 (PA6)
/Sensor07: Q7.1 (C), R15.2, U2.15 (PA1)
/Sensor08: Q8.1 (C), R17.2, U2.14 (PA0)
/Sensor09: Q9.1 (C), R19.2, U2.11 (PC3)
/Sensor10: Q11.1 (C), R26.2, U2.10 (PC2)
/Sensor11: Q12.1 (C), R28.2, U2.9 (PC1)
/Sensor12: Q13.1 (C), R30.2, U2.8 (PC0)
Encorder1_A: J5.6, RN2.1 (R1.1), U2.41 (PA8)
Encorder1_B: J5.8, RN2.2 (R2.1), U2.42 (PA9)
Encorder2_A: J9.6, RN2.3 (R3.1), U2.56 (PB4)
Encorder2_B: J9.8, RN2.4 (R4.1), U2.57 (PB5)
GND: C1.2, C2.2, C3.2, C4.2, C5.2, C6.2, C7.2, C8.2, C9.2, C10.2, C11.2, C12.2, C13.2, C14.2, C15.2, C16.2, C17.2, C18.2, C19.2, C20.2, C21.2, C22.2, D1.1 (K), D2.1 (K), D3.1 (K), D4.1 (K), D5.1 (K), D6.1 (K), D7.1 (K), D8.1 (K), D9.1 (K), D13.1 (K), D14.1 (K), D15.1 (K), J1.3, J2.3, J3.1, J4.3, J5.3, J7.4, J9.3, J10.3, J11.2, Q1.2 (E), Q2.2 (E), Q3.2 (E), Q4.2 (E), Q5.2 (E), Q6.2 (E), Q7.2 (E), Q8.2 (E), Q9.2 (E), Q11.2 (E), Q12.2 (E), Q13.2 (E), R22.2, R32.1, R33.1, SW1.2, U1.2 (GND), U2.12 (VSSA), U2.18 (VSS), U2.63 (VSS), U3.11 (FSYNC), U3.18 (GND), U3.20 (RESV)
I2C_SCL: J7.2, U2.61 (PB8)
I2C_SDA: J7.3, U2.62 (PB9)
ICM_MISO: RN1.3 (R3.1), U2.35 (PB14), U3.9 (SDO)
ICM_MOSI: RN1.2 (R2.1), U2.36 (PB15), U3.24 (SDI)
ICM_SCLK: RN1.1 (R1.1), U2.29 (PB10), U3.23 (SCLK)
ICM_nCS: RN1.4 (R4.1), U2.33 (PB12), U3.22 (nCS)
unnamed: BZ1.2 (+), D11.2 (A), Q10.3 (D)
unnamed: C7.1, C8.1, FB1.2, U2.13 (VDDA)
unnamed: C11.1, U2.31 (VCAP_1)
unnamed: C12.1, U2.47 (VCAP_2)
unnamed: C20.1, U3.10 (REGOUT)
unnamed: D1.2 (A), R1.2
unnamed: D2.2 (A), R3.2
unnamed: D3.2 (A), R5.2
unnamed: D4.2 (A), R7.2
unnamed: D5.2 (A), R9.2
unnamed: D6.2 (A), R11.2
unnamed: D7.2 (A), R14.2
unnamed: D8.2 (A), R16.2
unnamed: D9.2 (A), R18.2
unnamed: D10.2 (A), R20.2
unnamed: D12.2 (A), R24.2
unnamed: D13.2 (A), R25.2
unnamed: D14.2 (A), R27.2
unnamed: D15.2 (A), R29.2
unnamed: FB2.1, J10.1
unnamed: FB3.1, J10.2
unnamed: J3.2, U2.16 (PA2)
unnamed: J3.3, U2.17 (PA3)
unnamed: J3.4, U2.20 (PA4)
unnamed: J3.5, U2.21 (PA5)
unnamed: Q10.1 (G), R23.1, R32.2
unnamed: Q10.2 (S), R33.2
unnamed: R22.1, U2.60 (BOOT0)
unnamed: R23.2, U2.50 (PA15)
unnamed: U1.3 (OUT), U2.5 (PH0)
SWCLK: J4.2, U2.49 (PA14)
SWDIO: J4.4, U2.46 (PA13)
SWO: J4.6, U2.55 (PB3)
SubSens1: D12.1 (K), J2.2, R31.2, U2.28 (PB2)
SubSens2: D10.1 (K), J1.2, R21.2, U2.30 (PB11)
USART_RX: J11.4, U2.38 (PC7)
USART_TX: J11.3, U2.37 (PC6)
nRST: C9.1, J4.5, R13.2, SW1.1, U2.7 (NRST)

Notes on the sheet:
ENCORDER
SideSensor
ForegroundSensor
InertialSensor
PowerSupply
SWD
I2C
USART
90mA
6.2mA
240mA
Buzzer
Oscillator
2mA
1.5mA
20mA
36mA
SensorBar
Right
Left
All : 480mA
All:72mA
5V : under 100mA 3.3V : under 600mA
Main

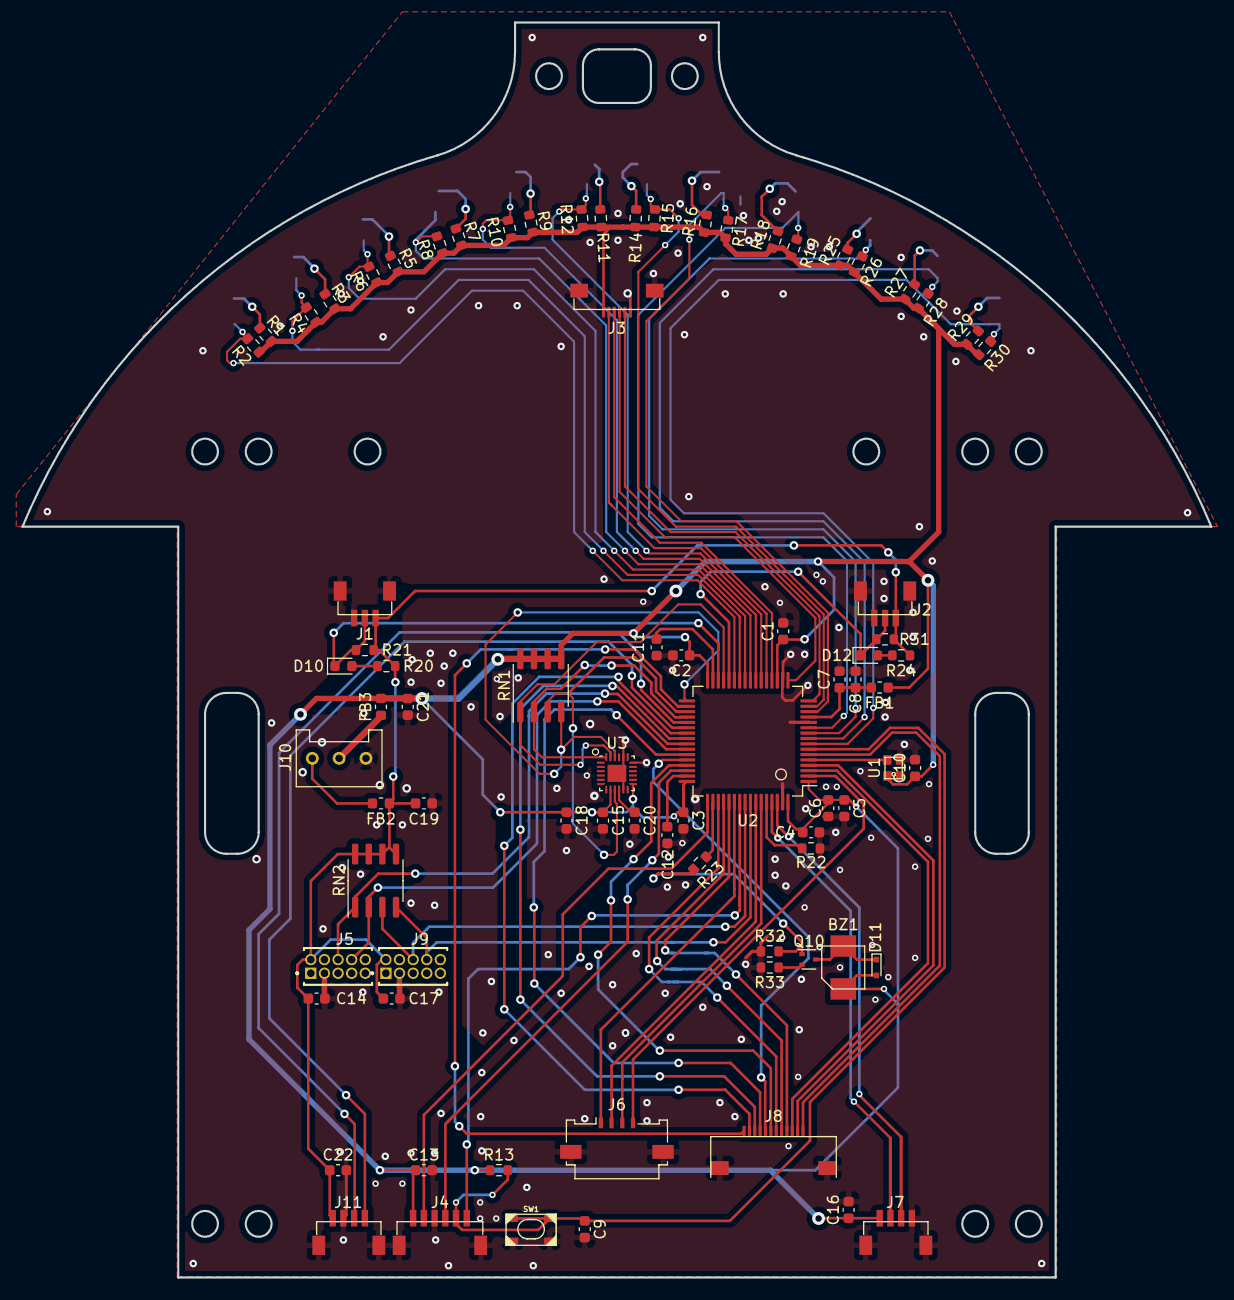
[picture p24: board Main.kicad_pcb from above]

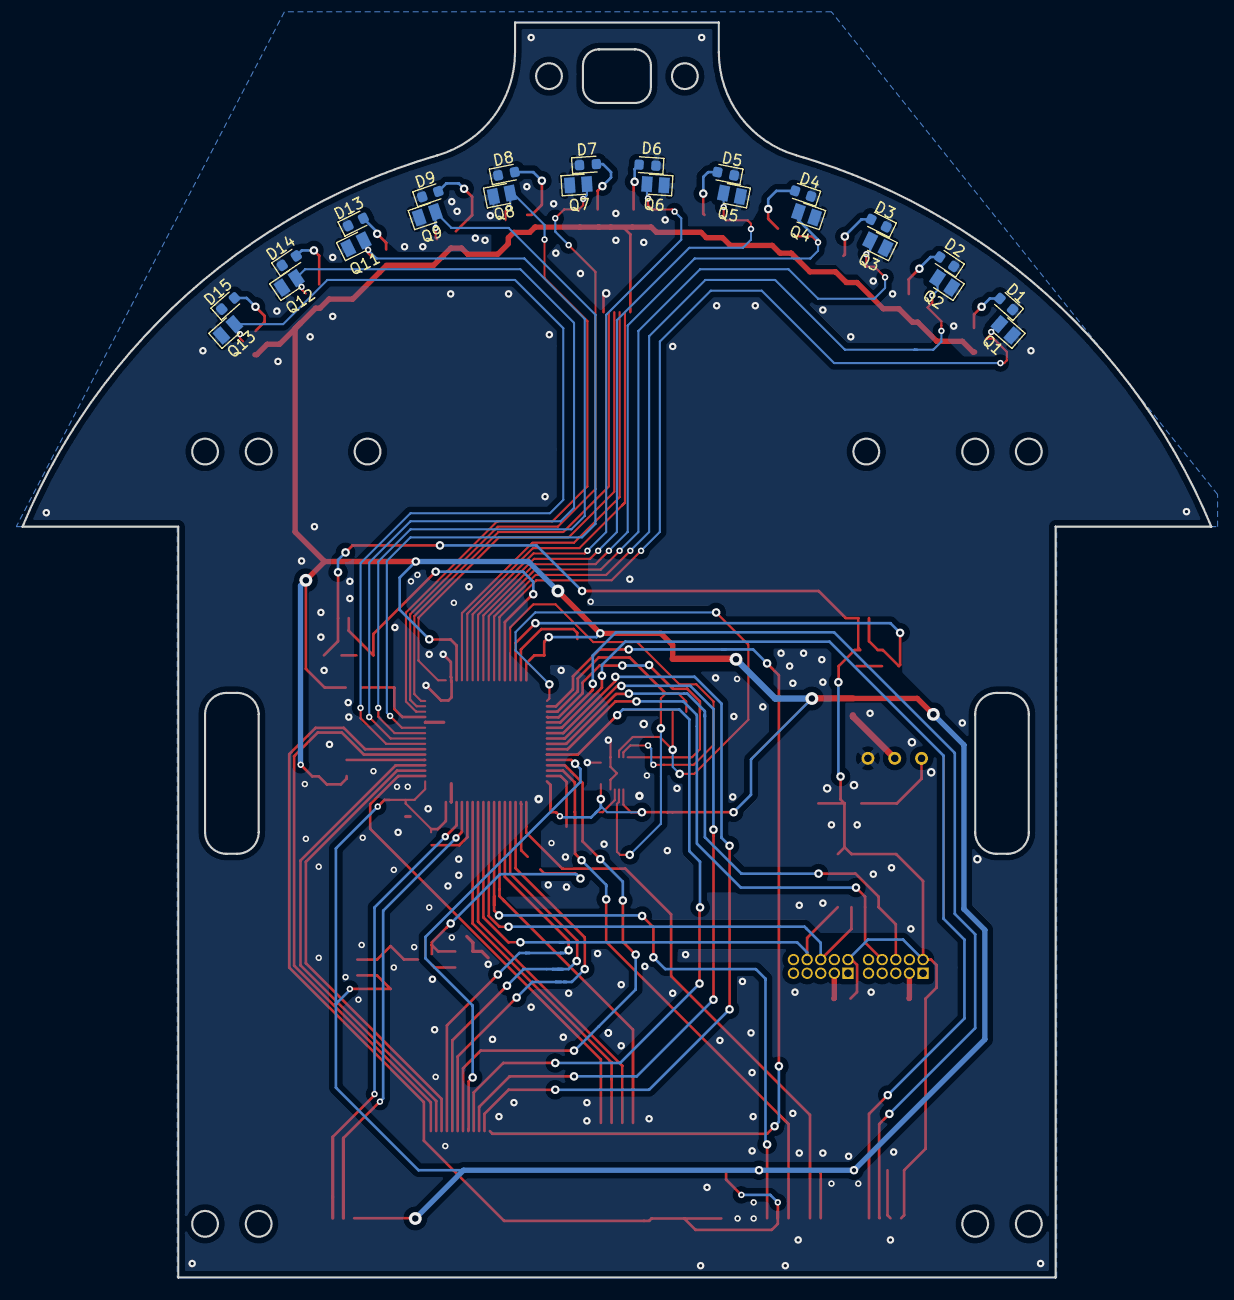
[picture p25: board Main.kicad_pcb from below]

Board: 2 copper layers, 110.8 x 117.0 mm, 104 parts (24 on the bottom side), 79 nets.

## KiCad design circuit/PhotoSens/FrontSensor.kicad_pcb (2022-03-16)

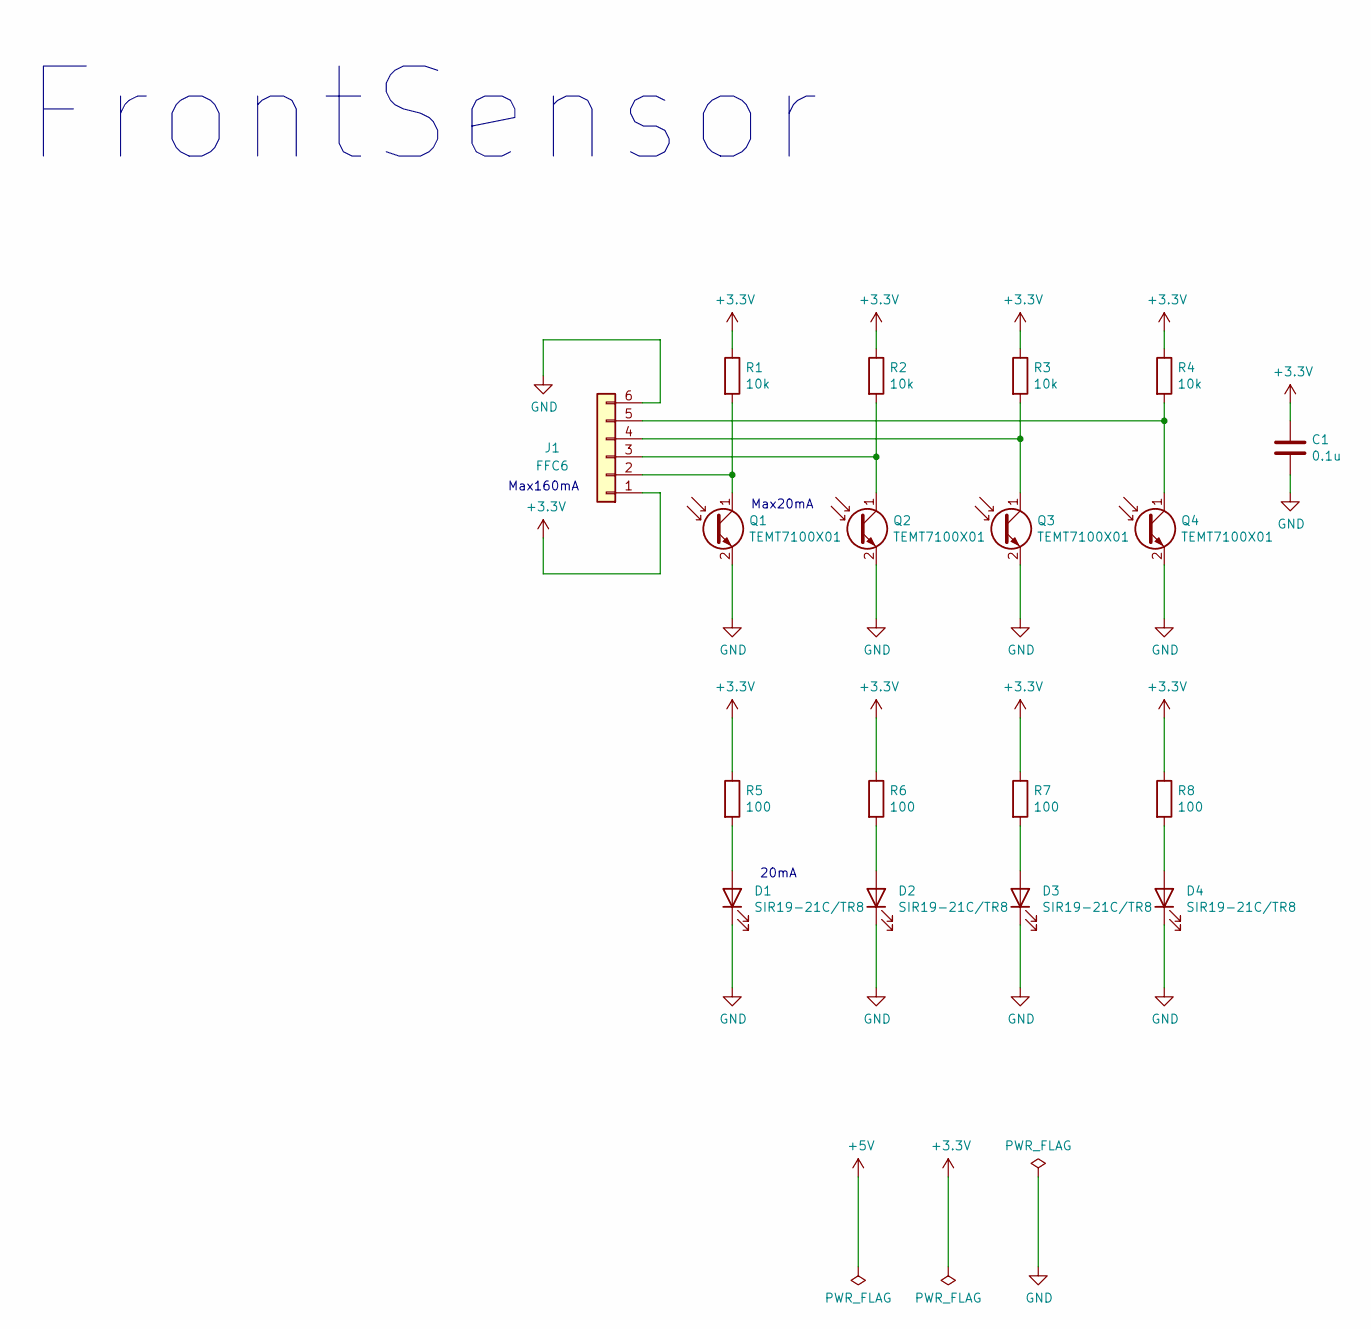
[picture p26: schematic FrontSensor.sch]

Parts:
C1: 0.1u; C_0603_1608Metric
D1, D2, D3, D4: SIR19-21C/TR8; D_0603_1608Metric
J1: FFC6; Molex_0545480671_01x06_P0.5mm
Q1, Q2, Q3, Q4: TEMT7100X01
R1, R2, R3, R4: 10k; R_0603_1608Metric
R5, R6, R7, R8: 100; R_0603_1608Metric

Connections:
+3V3: C1.1, J1.1, R1.1, R2.1, R3.1, R4.1, R5.1, R6.1, R7.1, R8.1
GND: C1.2, D1.1 (K), D2.1 (K), D3.1 (K), D4.1 (K), J1.6, J1.MP, Q1.2 (E), Q2.2 (E), Q3.2 (E), Q4.2 (E)
unnamed: D1.2 (A), R5.2
unnamed: D2.2 (A), R6.2
unnamed: D3.2 (A), R7.2
unnamed: D4.2 (A), R8.2
unnamed: J1.2, Q1.1 (C), R1.2
unnamed: J1.3, Q2.1 (C), R2.2
unnamed: J1.4, Q3.1 (C), R3.2
unnamed: J1.5, Q4.1 (C), R4.2

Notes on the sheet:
Max20mA
20mA
Max160mA
FrontSensor

Board: 2 copper layers, 18 parts (0 on the bottom side), 10 nets, no tracks yet.

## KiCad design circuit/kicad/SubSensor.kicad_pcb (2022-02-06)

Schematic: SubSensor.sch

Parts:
C1: 0.1u; C_0603_1608Metric
D1: SIR19-21C/TR8; D_0603_1608Metric
J1: SH3; SH_01x03
R1: 68; R_0603_1608Metric
U1: S7136

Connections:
+5V: C1.1, J1.3, R1.1, U1.2
GND: C1.2, J1.1, J1.MP, U1.4
unnamed: D1.1 (K), U1.1
unnamed: D1.2 (A), R1.2
unnamed: J1.2, U1.3

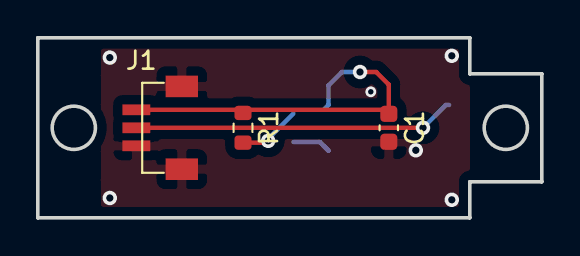
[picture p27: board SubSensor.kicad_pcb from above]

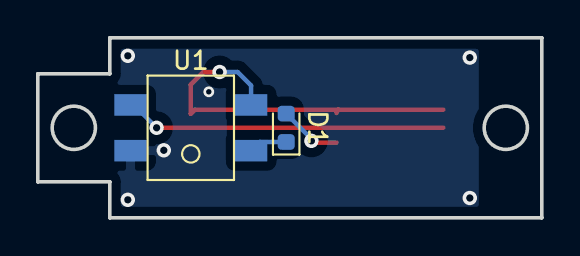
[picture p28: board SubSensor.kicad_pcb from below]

Board: 2 copper layers, 28.0 x 10.0 mm, 5 parts (2 on the bottom side), 5 nets.

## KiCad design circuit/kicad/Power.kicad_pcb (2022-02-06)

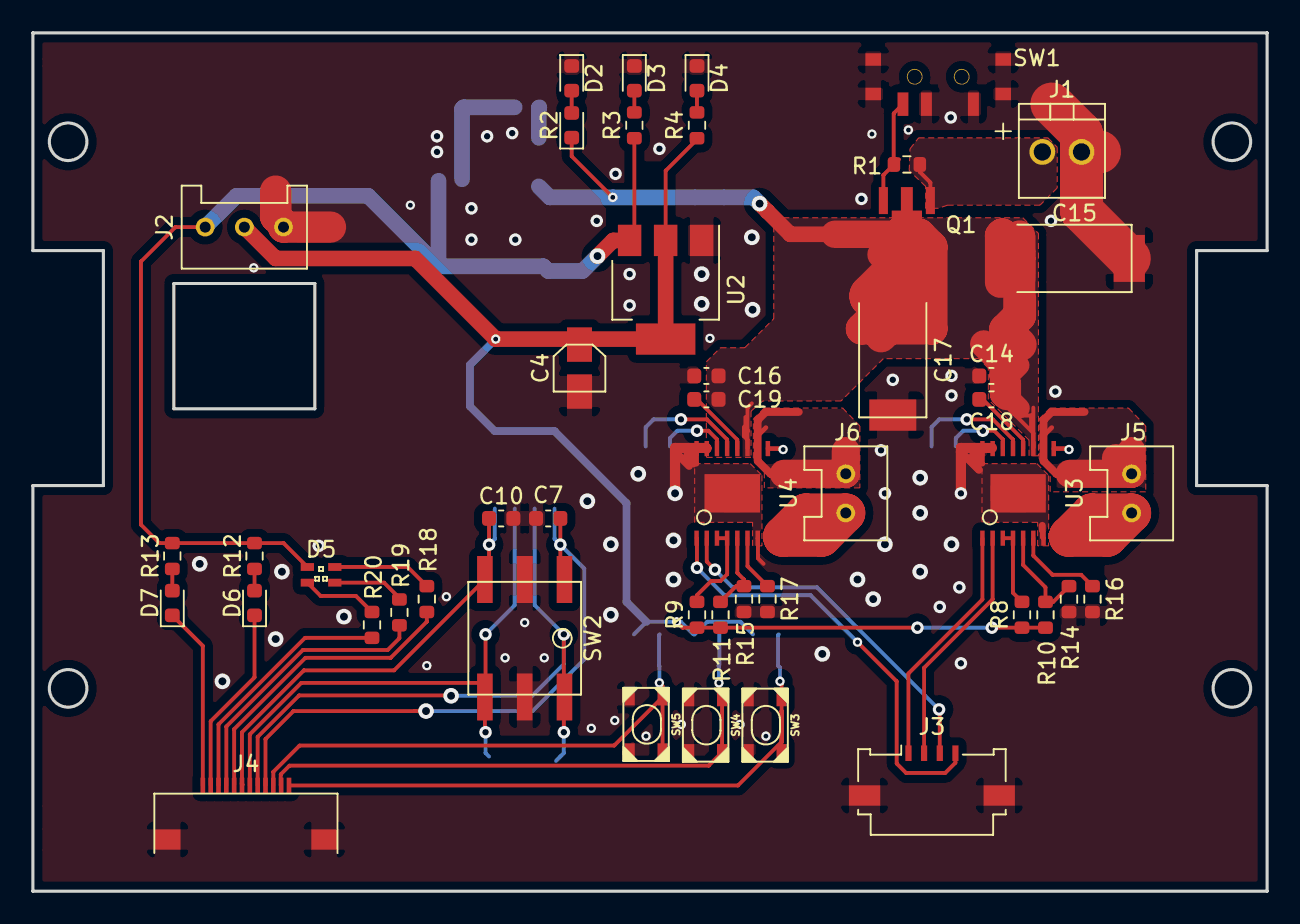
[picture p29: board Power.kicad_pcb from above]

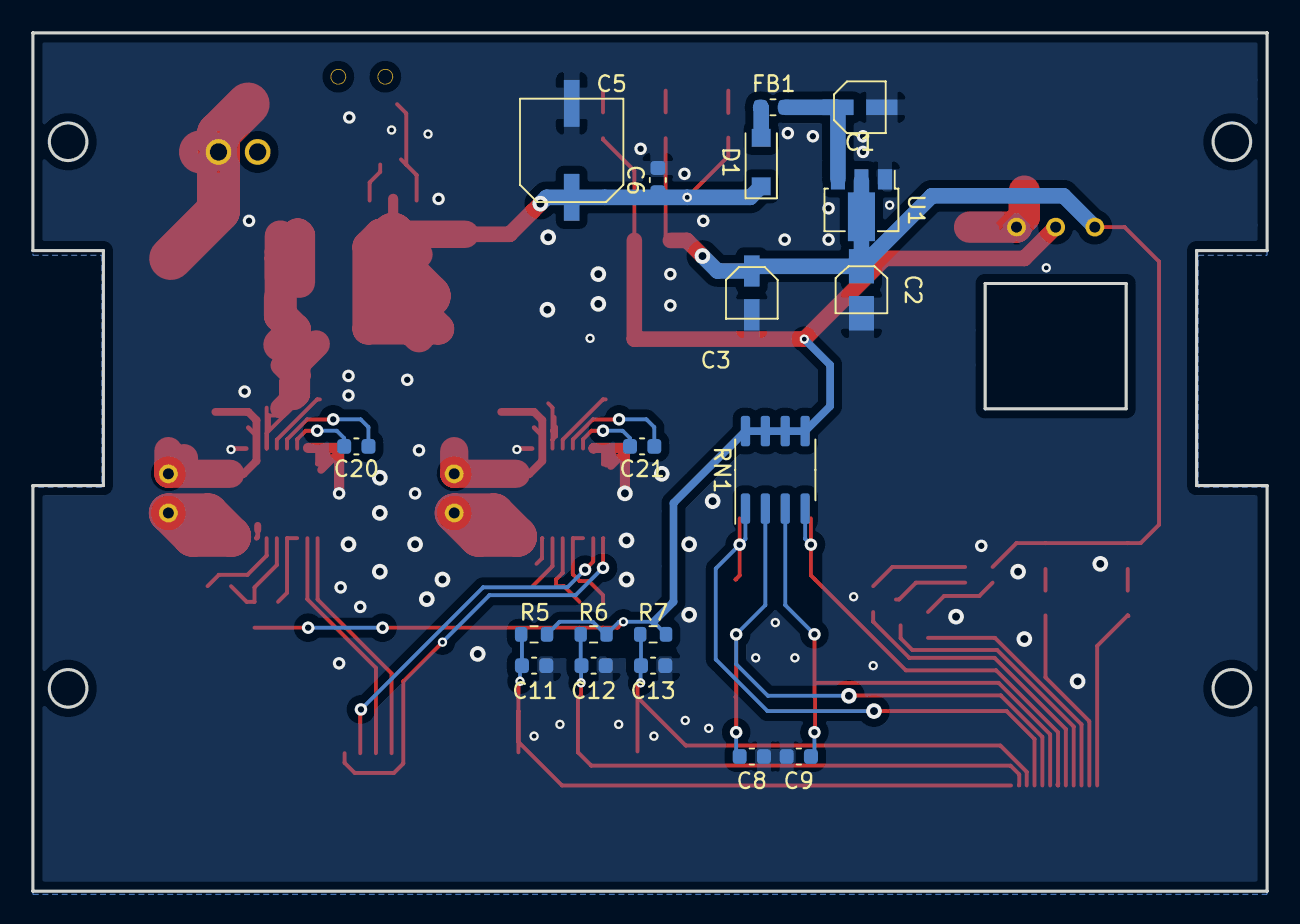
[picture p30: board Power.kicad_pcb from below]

Board: 2 copper layers, 78.8 x 54.8 mm, 66 parts (19 on the bottom side), 48 nets.

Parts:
C1, C3: 10u; AVE106M16A12T-F
C2, C4: 22u; 865090168010
C5: 220u; EEE-1AA221XP
C6, C7, C8, C9, C10, C11, C12, C13, C14, C16, C18, C19: 0.1u; C_0603_1608Metric
C15, C17: 100u; ECASD91B107M012K00
C20, C21: 22n; C_0603_1608Metric
D1: SS2040FL-AU_R1_000A1; SOD-123FL
D2: Red; D_0603_1608Metric
D3: Orange; D_0603_1608Metric
D4: Yellow; D_0603_1608Metric
D5: APTF1616LSEEZGKQBKC
D6, D7: SMLEN3WBC8W1; D_0603_1608Metric
FB1: 470; L_0603_1608Metric
J1: ILG2; ILG_01x02
J2: PA3; PA_01x03
J3: FFC4; Molex_200528-0040_1x04-1MP_P1.00mm_Horizontal
J4: FFC7; WürthElektronik_687112183722_01x12_P0.5mm
J5, J6: PA2; PA_01x02
Q1: CXDM4060P; SOT-89
R1, R5, R6, R7, R8, R9: 10k; R_0603_1608Metric
R2: 2k; D_0603_1608Metric
R3: 680; R_0603_1608Metric
R4: 270; R_0603_1608Metric
R10, R11: 16k; R_0603_1608Metric
R12, R13: 470; R_0603_1608Metric
R14, R15: 50k; R_0603_1608Metric
R16, R17, R19, R20: 1.2k; R_0603_1608Metric
R18: 1.5k; R_0603_1608Metric
RN1: 10k; SOIC-8_3.9x4.9mm_P1.27mm
SW1: SW_DPDT_x2; SSSS810701
SW2: 220AMB16R
SW3, SW4, SW5: SKRPABE010
U1: AZ1117R-5.0TRE1; SOT-89-3
U2: AZ1117IH-3.3TRG1; SOT-223-3_TabPin2
U3, U4: DRV8874; TSSOP_16-Pin

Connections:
+3V3: C4.1, J2.2, R4.1, R5.1, R6.1, R7.1, R8.1, R9.1, R10.1, R11.1, RN1.5, RN1.6, RN1.7, RN1.8, U2.2
+5V: C2.1, C3.1, D5.1, J2.1, R3.1, R12.1, R13.1, U1.2, U2.3
+BATT: C5.1, C6.1, C14.1, C15.1, C16.1, C17.1, C18.1, C19.1, D1.2, Q1.2, R2.1, U3.11, U4.11
/DRV1_EN: J3.1, U3.1
/DRV1_PN: J3.2, U3.2
/DRV2_EN: J3.4, U4.1
/DRV2_PN: J3.3, U4.2
/Rotary1: C7.1, J4.9, RN1.1, SW2.1
/Rotary2: C9.1, J4.7, RN1.3, SW2.2
/Rotary4: C10.1, J4.6, RN1.4, SW2.4
/Rotary8: C8.1, J4.8, RN1.2, SW2.8
/SW1: C13.1, J4.10, R7.2, SW5.1
/SW2: C12.1, J4.11, R6.2, SW4.1
/SW3: C11.1, J4.12, R5.2, SW3.1
GND: C1.2, C2.2, C3.2, C4.2, C5.2, C6.2, C7.2, C8.2, C9.2, C10.2, C11.2, C12.2, C13.2, C14.2, C15.2, C16.2, C17.2, D2.1, D3.1, D4.1, J1.1, J2.3, J3.MP, J4.MP, R14.2, R15.2, R16.2, R17.2, SW1.1, SW1.2, SW1.MP, SW2.C, SW3.2, SW4.2, SW5.2, U1.1, U2.1, U3.7, U3.9, U3.15, U3.16, U3.ThermalPad, U4.7, U4.9, U4.15, U4.16, U4.ThermalPad
unnamed: C1.1, FB1.1, U1.3
unnamed: C18.2, U3.12
unnamed: C19.2, U4.12
unnamed: C20.1, U3.13
unnamed: C20.2, U3.14
unnamed: C21.1, U4.13
unnamed: C21.2, U4.14
unnamed: D1.1, FB1.2
unnamed: D2.2, R2.2
unnamed: D3.2, R3.2
unnamed: D4.2, R4.2
unnamed: D5.2, R18.1
unnamed: D5.3, R19.1
unnamed: D5.4, R20.1
unnamed: D6.1, J4.2
unnamed: D6.2, R12.2
unnamed: D7.1, J4.1
unnamed: D7.2, R13.2
unnamed: J1.2, Q1.3, R1.1
unnamed: J4.3, R20.2
unnamed: J4.4, R19.2
unnamed: J4.5, R18.2
unnamed: J5.1, U3.8
unnamed: J5.2, U3.10
unnamed: J6.1, U4.8
unnamed: J6.2, U4.10
unnamed: Q1.1, R1.2, SW1.3
unnamed: R8.2, U3.3, U3.4
unnamed: R9.2, U4.3, U4.4
unnamed: R10.2, R14.1, U3.5
unnamed: R11.2, R15.1, U4.5
unnamed: R16.1, U3.6
unnamed: R17.1, U4.6

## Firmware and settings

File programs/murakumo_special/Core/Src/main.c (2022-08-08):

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
/* Includes ------------------------------------------------------------------*/
#include "main.h"

/* USER CODE BEGIN Includes */
#include "stdio.h"
#include <string.h>
#include <stdint.h>
// #include "math.h"
#include "ICM20648.h"

/* USER CODE END Includes */

/* USER CODE BEGIN PD */
#ifdef __GNUC__
#define PUTCHAR_PROTOTYPE int __io_putchar(int ch)
#else
#define PUTCHAR_PROTOTYPE int fputc(int ch, FILE *f)
#endif

#define PLAY 1

#define D_ANALOG 0
#define D_ANALOGRATE 0
#define D_MOTOR 0
#define D_SIDESENS 0	//
#define D_ENCODER 0	// Debug Encoder
#define D_PWM 0
#define D_ROTARY 0
#define D_SWITCH 0
#define D_IMU 1
#define D_LED 0
#define D_VELOCITY_CONTROL_TIMER 0

#define USE_ANALOG 0
#define USE_MOTOR 0
#define USE_SIDESENSOR 0	// Use SideSensor
#define USE_ENCODER 0
#define USE_ROTARY 1
#define USE_SWITCH 1
#define USE_LED 1
#define USE_FLASH 0
#define USE_IMU 1
#define USE_BUZZER 0
#define USE_VELOCITY_CONTROL 0

#define ATTACH_LONGSENSOR 0	// use normal sensor and long sensor
#define USE_LONGSENSOR 0	// only use long sensor

#define SECOND 1

/* USER CODE END PD */

/* USER CODE BEGIN PM */
#if USE_FLASH
#define BACKUP_FLASH_SECTOR_NUM FLASH_SECTOR_11
#define BACKUP_FLASH_SECTOR_SIZE (1024*16)
#define ENC_SIZE 128
#endif

#define ADC_CONVERTED_DATA_BUFFER_SIZE 16	// ADC Channel Count
#define SENSGETCOUNT 9

#define ENCODER_MIDDLE (65536/2)

#ifndef _ARM_MATH_H
#define PI 3.14159265358979f
#endif	// __MAIN_H
#define TIREDIAMETER 21000		// um
#define PULSEPERROTATE (5250*2)	// Pulse / Rotate
// LENGTHPUEPULSE = PI * TIREDIAMETER / PULSEPERROTATE

#define COMMONSPEED1 0	// 700 // 570
#define KP1 6.4f	// 30 // 25
#define KD1 13.75f	// 8  // 10
#define KI1 0	// 0.0005f
#define COMMONSPEED2 100	// 700 // 570
#define KP2 5	// 30 // 25
#define KD2 2	// 8  // 10
#define KI2 0
#define COMMONSPEED3 100	// 700 // 570
#define KP3 3	// 30 // 25
#define KD3 1	// 8  // 10
#define KI3 0

#define PWMMAX 1000 // 3360

#if D_PWM
#define STATICPWM 1
#endif

#define D_VELOCITY_CONTROL_IN_WHILE 0
#define VELOCITY_CONTROL_RELATIVE 1

#if USE_VELOCITY_CONTROL
#define VELOCITY_TARGET 750	//65.973f 	// MAX 35579 // mm/s
#define VELOCITY_MAX 35579
#if VELOCITY_CONTROL_RELATIVE
#define VKP 20	// 27.5f
#define VKI 0.2f	// 0.15f
#else	// VELOCITY_CONTRO_RELATIVE
// left
#define VKPL 8.0f
#define VKIL 0.025	// 0.025f
// right
#define VKPR 8.0f
#define VKIR 0.025	// 0.025f
#endif	// VELOCITY_CONTROL_RELATIVE
#if D_VELOCITY_CONTROL_TIMER
#define STOPTIME 10000 // 13188
#endif
#endif

#define ESC_MAG	"\x1b[35m"
#define ESC_RED "\x1b[31m"
#define ESC_YEL	"\x1b[33m"
#define ESC_GRE	"\x1b[32m"
#define ESC_CYA	"\x1b[36m"
#define ESC_BLU	"\x1b[34m"
#define ESC_DEF "\x1b[39m"

/* USER CODE END PM */

ADC_HandleTypeDef hadc1;
DMA_HandleTypeDef hdma_adc1;

I2C_HandleTypeDef hi2c1;

SPI_HandleTypeDef hspi2;

TIM_HandleTypeDef htim1;
TIM_HandleTypeDef htim3;
TIM_HandleTypeDef htim4;
TIM_HandleTypeDef htim6;
TIM_HandleTypeDef htim10;
TIM_HandleTypeDef htim11;

UART_HandleTypeDef huart6;

/* USER CODE BEGIN PV */
#if USE_FLASH
typedef struct {
	uint8_t svl[ENC_SIZE];
	uint8_t svr[ENC_SIZE];
	uint32_t common_speed2[ENC_SIZE];
	uint32_t common_speed3[ENC_SIZE];
//	uint16_t second[ENC_SIZE];
	Inertial inertial[ENC_SIZE];
	uint16_t analogmin[CALIBRATIONSIZE];
	uint16_t analogmin[CALIBRATIONSIZE];
} FlashBuffer;
#endif

// analog
uint16_t analograw[ADC_CONVERTED_DATA_BUFFER_SIZE];	// Analog Data

#if ATTACH_LONGSENSOR	// use normal sensor and long sensor
#define CALIBRATIONSIZE 16
#else
#if USE_LONGSENSOR	// only use long sensor
#define CALIBRATIONSIZE 4
#else
#define CALIBRATIONSIZE 12
#endif
#endif

uint16_t analog[CALIBRATIONSIZE];
uint16_t analogmax[CALIBRATIONSIZE];
uint16_t analogmin[CALIBRATIONSIZE];
uint16_t analogbuffers[SENSGETCOUNT][CALIBRATIONSIZE];

uint16_t analograte[CALIBRATIONSIZE];
uint16_t analogr, analogl;	// Sum Right Analog Sensor, Sum Left Analog Sensor
int direction, beforedirection, sdirection;	// = analogr - analogl
unsigned char sensgettime;
uint8_t calibrationsize;

double kp, kd, ki;

unsigned char subsensbuf, marker, sidedeltacount, markerstate, rightmarkercount;// 0 ~ 255(2^8-1)
short int encoder_l, encoder_r;
double LENGTHPERPULSE;	// (um / pulse)

#if SECOND
// uint8_t velocity[COURSELENGTH * 1000];
#endif

#if USE_FLASH
const uint32_t start_address = 0x080E0000;
const uint32_t end_address = 0x080FFFFF;
FlashBuffer flash_buffer;
uint8_t course_state_time;
#endif

#if D_PWM
#define PWM_STEP_AMPLITUDE 1000		// (288 + 1024 * 3) // PWM Pulse Amplitude
#define PWM_STEP_OMEGA 100	// PWM Step Omega (unit mrad / s)
uint32_t pwmstepoutput;	// PWM Duty
uint32_t pwmsteptime;	// PWM Step Time
char pwmstepud;	// PWM Step upword or downword
#endif

#if D_ENCODER
uint16_t d_encoder_left, dd_encoder_left, pre_d_encoder_left, d_encoder_right,
		dd_encoder_right, pre_d_encoder_right;
uint16_t enc1, enc2, enc3;
#endif

#if USE_VELOCITY_CONTROL
double velocity_l, velocity_l_raw;
double velocity_r, velocity_r_raw;
#if VELOCITY_CONTROL_RELATIVE
double velocity, velocity_error, s_velocity_error, velocity_next, velocity_raw;
double nextspeed;
#else	// VELOCITY_CONTROL_RELATIVE
		double velocity_error_l, s_velocity_error_l, velocity_next_l, nextspeed_l;
		double velocity_error_r, s_velocity_error_r, velocity_next_r, nextspeed_r;
	#endif	// VELOCITY_CONTROL_RELATIVE
#if D_VELOCITY_CONTROL_TIMER
		uint16_t stoptime;
	#endif
#endif

// motor
short int commonspeed;
double leftmotor;
double rightmotor;

// switch
uint8_t rotary_value;
char enter;
uint16_t timtim;

// flag
uint8_t motorenable;

/* USER CODE END PV */

void SystemClock_Config(void);
static void MX_GPIO_Init(void);
static void MX_DMA_Init(void);
static void MX_ADC1_Init(void);
static void MX_USART6_UART_Init(void);
static void MX_TIM6_Init(void);
static void MX_TIM4_Init(void);
static void MX_TIM1_Init(void);
static void MX_TIM3_Init(void);
static void MX_TIM10_Init(void);
static void MX_TIM11_Init(void);
static void MX_SPI2_Init(void);
static void MX_I2C1_Init(void);
/* USER CODE BEGIN PFP */

PUTCHAR_PROTOTYPE;
#if USE_LED
void led_rgb(char r, char g, char b);
void set_led(char);
#endif
void running_initialize();
void running_finalize();
void sensor_initialize();
void sensor_finalize();
void HAL_ADC_ConvCpltCallback(ADC_HandleTypeDef *AdcHandle);
#ifndef _ARM_MATH_H
double power(double, double);
#endif
#if USE_ENCODER
void encoder_initialize();
void encoder_finalize();
#endif
#if USE_FLASH
void eraseFlash(void);
void writeFlash(uint32_t, uint8_t*, uint32_t);
void loadFlash(uint32_t, uint8_t*, uint32_t);
#endif
void d_print();
#if USE_IMU
void IMU_printf(Inertial*);
void IMU_raw_printf();
#endif
double low_pass_filter(double val, double pre_val, double gamma);

void HAL_TIM_PeriodElapsedCallback(TIM_HandleTypeDef *htim) {
	if (htim->Instance == TIM6) {
#if D_VELOCITY_CONTROL_TIMER && USE_VELOCITY_CONTROL
		if(stoptime < STOPTIME)
		{
			stoptime++;
		}
		else
		{
			motorenable = 0;
		}
#endif // D_VELOCITY_CONTROL_TIMER && USE_VELOCITY_CONTROL

		if (motorenable)
		{
		} else	// if(motorenable)
		{
			leftmotor = 0;
			rightmotor = 0;
		}
#if USE_MOTOR

		if (leftmotor < 0) {
			HAL_GPIO_WritePin(GPIOD, GPIO_PIN_2, GPIO_PIN_RESET);
			leftmotor = leftmotor * -1;
		} else {
			HAL_GPIO_WritePin(GPIOD, GPIO_PIN_2, GPIO_PIN_SET);
		}

		if (rightmotor < 0) {
			HAL_GPIO_WritePin(GPIOC, GPIO_PIN_13, GPIO_PIN_SET);
			rightmotor = rightmotor * -1;
		} else {
			HAL_GPIO_WritePin(GPIOC, GPIO_PIN_13, GPIO_PIN_RESET);
		}

		leftmotor = leftmotor > PWMMAX ? PWMMAX : leftmotor;
		rightmotor = rightmotor > PWMMAX ? PWMMAX : rightmotor;
#endif
	}	// TIM6
	if (htim->Instance == TIM10)	// TIM10 // 1ms
	{
#if USE_IMU
#endif
#if USE_ENCODER
		// 1ms
		encoder_l = TIM1->CNT - ENCODER_MIDDLE;
		encoder_r = -(TIM3->CNT - ENCODER_MIDDLE);

		TIM1->CNT = ENCODER_MIDDLE;
		TIM3->CNT = ENCODER_MIDDLE;
#endif	// USE_ENCODER
#if USE_LED
		if(timtim % 1000 == 0)
		{
			set_led(0b10);
		}
		if(timtim % 1000 == 500)
		{
			set_led(0b00);
		}
		timtim = timtim + 1;
		if(timtim >= 60000)
		{
			timtim = 0;
		}
#endif
	}	// TIM10

	if (htim->Instance == TIM11)	// TIM11 // 1ms
	{
		uint8_t rotary_value_row;
		rotary_value_row = (!HAL_GPIO_ReadPin(GPIOC, GPIO_PIN_12)) ? 1 : 0;
		rotary_value_row += (!HAL_GPIO_ReadPin(GPIOC, GPIO_PIN_10)) ? 2 : 0;
		rotary_value_row += (!HAL_GPIO_ReadPin(GPIOA, GPIO_PIN_12)) ? 4 : 0;
		rotary_value_row += (!HAL_GPIO_ReadPin(GPIOC, GPIO_PIN_11)) ? 8 : 0;
		rotary_value = rotary_value_row;

#if USE_BUZZER
		__HAL_TIM_SET_COMPARE(&htim2, TIM_CHANNEL_1, 1406 * rotary_value_row / 16);
#endif

		if (!HAL_GPIO_ReadPin(GPIOC, GPIO_PIN_14)
				&& HAL_GPIO_ReadPin(GPIOC, GPIO_PIN_15)) {
			enter = 1;
		}
		if (HAL_GPIO_ReadPin(GPIOC, GPIO_PIN_14)
				&& !HAL_GPIO_ReadPin(GPIOC, GPIO_PIN_15)) {
			enter = 0;
		}
	}

	/*
	 if (htim->Instance == TIM13)	// TIM13 // 1ms
	 {
	 }

	 if (htim->Instance == TIM7)	// F // 0.1ms
	 {
	 }
	 */
}

/* USER CODE END PFP */

/**
  * @brief  The application entry point.
  * @retval int
  */
int main(void)
{
  /* MCU Configuration--------------------------------------------------------*/

  /* Reset of all peripherals, Initializes the Flash interface and the Systick. */
  HAL_Init();

  /* USER CODE BEGIN Init */
#if USE_FLASH
	FlashBuffer readrom;
#endif

	enter = 0;
	motorenable = 0;
	rotary_value = 0;
	LENGTHPERPULSE = PI * TIREDIAMETER / PULSEPERROTATE;
	commonspeed = 0;
#if D_PWM
	pwmsteptime = 0;
	pwmstepud = 1;
#endif

	for (unsigned char i = 0; CALIBRATIONSIZE > i; i++) {
		analogmax[i] = 0;
		analogmin[i] = 4096;
	}

  /* USER CODE END Init */

  /* Configure the system clock */
  SystemClock_Config();

  /* Initialize all configured peripherals */
  MX_GPIO_Init();
  MX_DMA_Init();
  MX_ADC1_Init();
  MX_USART6_UART_Init();
  MX_TIM6_Init();
  MX_TIM4_Init();
  MX_TIM1_Init();
  MX_TIM3_Init();
  MX_TIM10_Init();
  MX_TIM11_Init();
  MX_SPI2_Init();
  MX_I2C1_Init();
  /* USER CODE BEGIN 2 */
	printf(ESC_DEF);
	printf("\r\n\r\n\r\nStarting Program...\r\n\r\n");

	printf("Starting Analog Read\r\n");
	if (HAL_ADC_Init(&hadc1) != HAL_OK) {
		Error_Handler();
	}

	printf("Starting TIM11\r\n");
	HAL_TIM_Base_Start_IT(&htim11);	// 1ms	// ROTARY SWITCH

#if USE_BUZZER
	printf("Starting TIM2 (Buzzer)\r\n");
	if(HAL_TIM_PWM_Start(&htim2, TIM_CHANNEL_1) != HAL_OK)
	{
		Error_Handler();
	}
#endif

#if USE_IMU
	printf("Starting SPI2 (IMU)\r\n");
	uint8_t wai, ret;
	ret = IMU_init(&wai);
	printf("who_am_i = %d\r\n", wai);
	if (ret == 1) {
		printf("SPI INIT COLLECT!\r\n");
	} else {
		printf("SPI INIT FAILURE x_x \r\n");
	}
#if D_IMU
	printf("inertial offset\r\n");
	printf("ax = %4d, ay = %4d, az = %4d\r\n", inertial_offset.accel.x,
			inertial_offset.accel.y, inertial_offset.accel.z);
	printf("gx = %4d, gy = %4d, gz = %4d\r\n", inertial_offset.gyro.x,
			inertial_offset.gyro.y, inertial_offset.gyro.z);
#endif
#endif

#if D_ENCODER
	printf("LENGTHPERPULSE = %f\r\n", LENGTHPERPULSE);
#endif

  /* USER CODE END 2 */

  /* Infinite loop */
  /* USER CODE BEGIN WHILE */
	while (1) {
		printf("///// WHILE /////\n\r");
		printf("enter = %d\r\n", enter);
		printf("rotary_value = %x\r\n", rotary_value);
		if (enter) {
			switch (rotary_value) {
			case 0x0:
				break;	// case 0x00:
			case 0x1:
				running_initialize();

				while (enter) {
					d_print();
					HAL_Delay(250);
				}

				running_finalize();
				break;
			case 0x2:
				running_initialize();

				while (enter) {
					d_print();
					HAL_Delay(250);
				}

				running_finalize();
				break;
			case 0x3:
				running_initialize();

				while (enter) {
					d_print();
					HAL_Delay(250);
				}

				running_finalize();
				break;
			case 0xE:
				break;
			case 0xF:
				while (enter) {
					HAL_Delay(250);
				}
				break;
			case 0xD:
#if USE_IMU
#if D_IMU
				/*
				 // IMU TEST
				 IMU_set_offset();
				 printf("inertial offset\r\n");
				 printf("ax = %4d, ay = %4d, az = %4d\r\n", inertial_offset.accel.x, inertial_offset.accel.y, inertial_offset.accel.z);
				 printf("gx = %4d, gy = %4d, gz = %4d\r\n", inertial_offset.gyro.x, inertial_offset.gyro.y, inertial_offset.gyro.z);
				 while(enter)
				 {
				 printf("////////// IMU ///////////\r\n");
				 IMU_read();
				 printf("ax = %4d, ay = %4d, az = %4d\r\n", inertial.accel.x - inertial_offset.accel.x, inertial.accel.y - inertial_offset.accel.y, inertial.accel.z - inertial_offset.accel.z);
				 printf("gx = %4d, gy = %4d, gz = %4d\r\n", inertial.gyro.x - inertial_offset.gyro.x, inertial.gyro.y - inertial_offset.gyro.y, inertial.gyro.z - inertial_offset.gyro.z);
				 HAL_Delay(250);
				 }
				 */
				while (enter) {
					printf("////////// IMU ///////////\r\n");
					IMU_read();
					IMU_raw_printf();
					HAL_Delay(250);
				}
#endif // D_IMU
#endif
				break;
			} // switch(rotary_value)
		}	// if(enter)
	}	// while(1)
	HAL_Delay(250);
    /* USER CODE END WHILE */

}

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
/* USER CODE BEGIN 4 */

uint8_t rotary_read() {
	uint8_t _rotaryvalue = 0;
	_rotaryvalue += (HAL_GPIO_ReadPin(GPIOC, GPIO_PIN_12)) ? 0 : 1;	// Rotary1
	_rotaryvalue += (HAL_GPIO_ReadPin(GPIOC, GPIO_PIN_10)) ? 0 : 1;	// Rotary2
	_rotaryvalue += (HAL_GPIO_ReadPin(GPIOA, GPIO_PIN_12)) ? 0 : 1;	// Rotary4
	_rotaryvalue += (HAL_GPIO_ReadPin(GPIOC, GPIO_PIN_11)) ? 0 : 1;	// Rotary8
	return _rotaryvalue;
}

#if USE_LED
void led_rgb(char r, char g, char b) {
	HAL_GPIO_WritePin(GPIOA, GPIO_PIN_11, (r) ? GPIO_PIN_RESET : GPIO_PIN_SET);	// LED_R ON
	HAL_GPIO_WritePin(GPIOA, GPIO_PIN_10, (g) ? GPIO_PIN_RESET : GPIO_PIN_SET);	// LED_G ON
	HAL_GPIO_WritePin(GPIOC, GPIO_PIN_9, (b) ? GPIO_PIN_RESET : GPIO_PIN_SET);// LED_B ON
}

void set_led(char value)
{
	HAL_GPIO_WritePin(GPIOC, GPIO_PIN_8, (value & 0b01) ? GPIO_PIN_RESET : GPIO_PIN_SET);	// RIGHT
	HAL_GPIO_WritePin(GPIOB, GPIO_PIN_13, (value & 0b10) ? GPIO_PIN_RESET : GPIO_PIN_SET);	// LEFT
}
#endif

void sensor_initialize() {
	sensgettime = 0;
	if (HAL_ADC_Start_DMA(&hadc1, (uint32_t*) analograw,
	ADC_CONVERTED_DATA_BUFFER_SIZE) != HAL_OK) {
		Error_Handler();
	}
	HAL_Delay(1000);
}

void sensor_finalize() {
	HAL_ADC_Stop_DMA(&hadc1);
}

void running_initialize() {
	sensor_initialize();
#if USE_VELOCITY_CONTROL
#if D_VELOCITY_CONTROL_TIMER
	stoptime = 0;
#endif
	encoder_initialize();
#endif
	timtim = 0;
	printf("Encoder_Start\r\n");
	HAL_TIM_Encoder_Start(&htim1, TIM_CHANNEL_ALL);
	HAL_TIM_Encoder_Start(&htim3, TIM_CHANNEL_ALL);
	subsensbuf = 0;
	marker = 0;
	sidedeltacount = 0;
	markerstate = 0;
	rightmarkercount = 0;
#if USE_FLASH
	course_state_time = 0;
#endif
	printf("SIDESENSOR ENCODER\r\n");
	HAL_TIM_Base_Start_IT(&htim10);
	leftmotor = 0;
	rightmotor = 0;
	beforedirection = 0;
	sdirection = 0;
	printf("PWM_Start\r\n");
	HAL_TIM_PWM_Start(&htim4, TIM_CHANNEL_1);	// 50kHz (0.02ms)
	HAL_TIM_PWM_Start(&htim4, TIM_CHANNEL_2);
	printf("PID\r\n");
	HAL_TIM_Base_Start_IT(&htim6);	// PID
#if PLAY
	motorenable = 1;
#endif
}

void running_finalize() {
	motorenable = 0;
	sensor_finalize();
	HAL_TIM_Base_Stop_IT(&htim6);
	HAL_TIM_PWM_Stop(&htim4, TIM_CHANNEL_2);
	HAL_TIM_PWM_Stop(&htim4, TIM_CHANNEL_1);
	encoder_finalize();
	HAL_TIM_Base_Stop_IT(&htim10);
}

void d_print() {
	printf("////////// d_print //////////\r\n");

#if D_ANALOG || D_ANALOGRATE
#if CALIBRATIONSIZE != 16
#if (CALIBRATIONSIZE == 4)
	printf(ESC_DEF);
#endif
#if CALIBRATIONSIZE == 12
	printf(ESC_RED);
#endif
#else
	printf(ESC_DEF);
#endif

#if !D_ANALOGRATE
	// only use normal sensor
	printf("\x1b[23C");	// Cursor move right *24
	printf("%4d, %4d | %4d, %4d\r\n", analog[12], analog[14], analog[15],
			analog[13]);
#else
	printf("\x1b[23C");	// Cursor move right *24
	printf("%4d, %4d | %4d, %4d\r\n", analograte[12], analograte[14], analograte[15],
			analograte[13]);
#endif	// D_ANALOGRATE

#if CALIBRATIONSIZE == 4
	printf(ESC_RED);
#endif
#if (CALIBRATIONSIZE == 12)
	printf(ESC_DEF);
#endif

#if !D_ANALOGRATE
	printf("%4d, %4d, %4d, %4d, %4d, %4d | %4d, %4d, %4d, %4d, %4d, %4d\r\n",
			analog[0], analog[2], analog[4], analog[6], analog[8], analog[10],
			analog[11], analog[9], analog[7], analog[5], analog[3],
			analog[1]);
#else
	printf("%4d, %4d, %4d, %4d, %4d, %4d | %4d, %4d, %4d, %4d, %4d, %4d\r\n",
			analograte[0], analograte[2], analograte[4], analograte[6], analograte[8], analograte[10],
			analograte[11], analograte[9], analograte[7], analograte[5], analograte[3],
			analograte[1]);
#endif	// D_ANALOGRATE
	printf("\r\n");

#endif	// D_ANALOG

#if D_ENCODER
/*
	printf("encoder_l = %d, encoder_r = %d \r\ndvl = %d, dvr = %d\r\n",
			encoder_l, encoder_r, dvl, dvr);
	printf("lengthl = %d, lengthr = %d \r\nvelocityl = %d, velocityr = %d\r\n",
			lengthl, lengthr, velocityl, velocityr);
*/
	printf("TIM1->CNT = %5d, TIM3->CNT = %5d\r\nencoder_l = %5d, encoder_r = %5d\r\n", TIM1->CNT, TIM3->CNT, encoder_l, encoder_r);
#endif

#if D_PWM
	printf("pwmstepoutput = %5d, pwmsteptime = %5d, pwmstepud = %d\r\n", pwmstepoutput, pwmsteptime, pwmstepud);
#endif

#if D_ROTARY
	printf("rotary_value = %x\r\n", rotary_value);
#endif

#if D_SWITCH
	printf("enter = %d\r\n", enter);
#endif

#if D_IMU
#endif

#if D_VELOCITY_CONTROL
#if !VELOCITY_CONTROL_RELATIVE
	printf("velocity_error = %5.3f, s_velocity_error = %5.3f\r\n",
			velocity_error_l, s_velocity_error_l);
	printf("velocity_next = %5.3f\r\n", velocity_next_l);
	printf("nextspeed = %5.3f\r\n", nextspeed_l);
	printf("leftmotor = %5.3f, rightmotor = %5.3f\r\n", leftmotor, rightmotor);
#else
//	printf("LENGTHPERPULSE = %5.3f\r\n", LENGTHPERPULSE);
	printf("encoder = %3.1f\r\nLENGTHPERPULSE = %f\r\nvelocity = %5.3f\r\nvelocity_error = %5.3f, s_velocity_error = %5.3f\r\nvelocity_next = %5.3f\r\nnextspeed = %5.3f\r\n",
			(encoder_l + encoder_r) / (double)2.0f, LENGTHPERPULSE, (velocity_l + velocity_r) / (double)2.0f, velocity_error, s_velocity_error, velocity_next, nextspeed);
#endif	// VELOCITY_CONTROL_RELARIVE
#endif	// D_VELOCITY_CONTROL

#if D_MOTOR
	printf("leftmotor = %5.3f, rightmotor = %5.3f\r\n", leftmotor, rightmotor);
#endif
}	// d_print

#if USE_IMU
void IMU_printf(Inertial *a) {
	printf("%4d, %4d, %4d, ", a->accel.x, a->accel.y, a->accel.z);
	printf("%4d, %4d, %4d\r\n", a->gyro.x, a->gyro.y, a->gyro.z);
}

void IMU_raw_printf() {
	printf("%4d, %4d, %4d, ", inertial.accel.x, inertial.accel.y,
			inertial.accel.z);
	printf("%4d, %4d, %4d\r\n", inertial.gyro.x, inertial.gyro.y,
			inertial.gyro.z);
}
#endif

void encoder_initialize() {
#if USE_VELOCITY_CONTROL
#if VELOCITY_CONTROL_RELATIVE
	s_velocity_error = 0;
#else
	s_velocity_error_l = 0;
	s_velocity_error_r = 0;
#endif
#endif

	TIM1->CNT = ENCODER_MIDDLE;
	TIM3->CNT = ENCODER_MIDDLE;

	HAL_TIM_Encoder_Start(&htim1, TIM_CHANNEL_ALL);
	HAL_TIM_Encoder_Start(&htim3, TIM_CHANNEL_ALL);
}

void encoder_finalize() {
	HAL_TIM_Encoder_Stop(&htim1, TIM_CHANNEL_ALL);
	HAL_TIM_Encoder_Stop(&htim3, TIM_CHANNEL_ALL);
}

PUTCHAR_PROTOTYPE {
	HAL_UART_Transmit(&huart6, (uint8_t*) &ch, 1, 0xFFFF);
	return ch;
}

double low_pass_filter(double val, double pre_val, double gamma) {
	return (double)(gamma * (double)pre_val + (double)(1 - gamma) * (double)val);
}

void HAL_ADC_ConvCpltCallback(ADC_HandleTypeDef *AdcHandle) {
	// sort
	if (sensgettime >= SENSGETCOUNT) {
		sensgettime = 0;
		for (unsigned char index = 0; index < CALIBRATIONSIZE; index++) {
			for (unsigned char count = 0; count < SENSGETCOUNT; count++) {
				for (unsigned char alphaindex = 0; alphaindex > count;
						alphaindex--) {
					uint16_t analogbuffer = analogbuffers[alphaindex - 1][index];
					analogbuffers[alphaindex - 1][index] =
							analogbuffers[alphaindex][index];
					analogbuffers[alphaindex][index] = analogbuffer;
				}
			}
			analog[index] = analogbuffers[(int) SENSGETCOUNT / 2][index];
			// get maxvalue and minimumvalue
			uint16_t analogbuf;
			analogbuf = analog[index];
			analogmax[index] =
					(analogmax[index] < analogbuf) ?
							analogbuf : analogmax[index];
			analogmin[index] =
					(analogmin[index] > analogbuf) ?
							analogbuf : analogmin[index];
		}
	}
	// sensorget
	for (unsigned char index = 0; CALIBRATIONSIZE > index; index++) {
		analogbuffers[sensgettime][index] = analograw[index];
	}
	sensgettime++;
}

#ifndef _ARM_MATH_H
double power(double a, double b) {
	double r;
	r = 1;
	for (int i = b; i > 0; i--) {
		//	r = r * a;
	}

	return r;
}
#endif

#if USE_FLASH
void eraseFlash(void) {
	FLASH_EraseInitTypeDef erase;
	erase.TypeErase = FLASH_TYPEERASE_SECTORS;
	erase.Sector = FLASH_SECTOR_11;
	erase.NbSectors = 1;
	erase.VoltageRange = FLASH_VOLTAGE_RANGE_3;
	uint32_t pageError = 0;

	HAL_FLASHEx_Erase(&erase, &pageError);
}

void writeFlash(uint32_t address, uint8_t *data, uint32_t size) {
	HAL_FLASH_Unlock();
	eraseFlash();

	for (uint32_t add = address; add < (address + size); add++) {
		HAL_FLASH_Program(FLASH_TYPEPROGRAM_BYTE, add, *data);
		data++;
	}

	HAL_FLASH_Lock();
}

void loadFlash(uint32_t address, uint8_t *data, uint32_t size) {
	memcpy(data, (uint64_t*) address, size);
}
#endif
/* USER CODE END 4 */
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


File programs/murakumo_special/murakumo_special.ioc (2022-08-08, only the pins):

Mcu.UserName=STM32F405RGTx
PA0-WKUP.Signal=ADCx_IN0
PA1.Signal=ADCx_IN1
PA10.GPIO_Label=LED_G
PA10.Signal=GPIO_Output
PA11.GPIO_Label=LED_R
PA11.Signal=GPIO_Output
PA12.GPIO_Label=Rotary4
PA12.Signal=GPIO_Input
PA13.Signal=SYS_JTMS-SWDIO
PA14.Signal=SYS_JTCK-SWCLK
PA15.Signal=S_TIM2_CH1_ETR
PA2.Signal=ADCx_IN2
PA3.Signal=ADCx_IN3
PA4.Signal=ADCx_IN4
PA5.Signal=ADCx_IN5
PA6.Signal=ADCx_IN6
PA7.Signal=ADCx_IN7
PA8.GPIO_Label=Encoder1_A
PA8.Signal=S_TIM1_CH1
PA9.GPIO_Label=Encoder1_B
PA9.Signal=S_TIM1_CH2
PB0.Signal=ADCx_IN8
PB1.Signal=ADCx_IN9
PB10.Signal=SPI2_SCK
PB11.GPIO_Label=SubSens2
PB11.Signal=GPIO_Input
PB12.GPIO_Label=SPI2_nCS
PB12.Signal=GPIO_Output
PB13.GPIO_Label=LED_Red
PB13.Signal=GPIO_Output
PB14.Signal=SPI2_MISO
PB15.Signal=SPI2_MOSI
PB2.GPIO_Label=SubSens1
PB2.Signal=GPIO_Input
PB3.Signal=SYS_JTDO-SWO
PB4.GPIO_Label=Encoder2_A
PB4.Signal=S_TIM3_CH1
PB5.GPIO_Label=Encoder2_B
PB5.Signal=S_TIM3_CH2
PB6.GPIO_Label=DRV1_EN
PB6.Signal=S_TIM4_CH1
PB7.GPIO_Label=DRV2_EN
PB7.Signal=S_TIM4_CH2
PB8.Signal=I2C1_SCL
PB9.Signal=I2C1_SDA
PC0.Signal=ADCx_IN10
PC1.Signal=ADCx_IN11
PC10.GPIO_Label=Rotary2
PC10.Signal=GPIO_Input
PC11.GPIO_Label=Rotary8
PC11.Signal=GPIO_Input
PC12.GPIO_Label=Rotary1
PC12.Signal=GPIO_Input
PC13-ANTI_TAMP.GPIO_Label=DRV2_PH
PC13-ANTI_TAMP.Signal=GPIO_Output
PC14-OSC32_IN.GPIO_Label=SW1
PC14-OSC32_IN.Signal=GPIO_Input
PC15-OSC32_OUT.GPIO_Label=SW2
PC15-OSC32_OUT.Signal=GPIO_Input
PC2.Signal=ADCx_IN12
PC3.Signal=ADCx_IN13
PC4.Signal=ADCx_IN14
PC5.Signal=ADCx_IN15
PC6.Signal=USART6_TX
PC7.Signal=USART6_RX
PC8.GPIO_Label=LED_White
PC8.Signal=GPIO_Output
PC9.GPIO_Label=LED_B
PC9.Signal=GPIO_Output
PD2.GPIO_Label=DRV1_PH
PD2.Signal=GPIO_Output
PH0-OSC_IN.Signal=RCC_OSC_IN
PH1-OSC_OUT.Signal=RCC_OSC_OUT

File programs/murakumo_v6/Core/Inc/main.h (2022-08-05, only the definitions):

#define DRV2_PH_Pin GPIO_PIN_13
#define DRV2_PH_GPIO_Port GPIOC
#define SW1_Pin GPIO_PIN_14
#define SW1_GPIO_Port GPIOC
#define SW2_Pin GPIO_PIN_15
#define SW2_GPIO_Port GPIOC
#define SubSens1_Pin GPIO_PIN_2
#define SubSens1_GPIO_Port GPIOB
#define SubSens2_Pin GPIO_PIN_11
#define SubSens2_GPIO_Port GPIOB
#define SPI2_nCS_Pin GPIO_PIN_12
#define SPI2_nCS_GPIO_Port GPIOB
#define LED_Red_Pin GPIO_PIN_13
#define LED_Red_GPIO_Port GPIOB
#define LED_White_Pin GPIO_PIN_8
#define LED_White_GPIO_Port GPIOC
#define LED_B_Pin GPIO_PIN_9
#define LED_B_GPIO_Port GPIOC
#define Encoder1_A_Pin GPIO_PIN_8
#define Encoder1_A_GPIO_Port GPIOA
#define Encoder1_B_Pin GPIO_PIN_9
#define Encoder1_B_GPIO_Port GPIOA
#define LED_G_Pin GPIO_PIN_10
#define LED_G_GPIO_Port GPIOA
#define LED_R_Pin GPIO_PIN_11
#define LED_R_GPIO_Port GPIOA
#define Rotary4_Pin GPIO_PIN_12
#define Rotary4_GPIO_Port GPIOA
#define Rotary2_Pin GPIO_PIN_10
#define Rotary2_GPIO_Port GPIOC
#define Rotary8_Pin GPIO_PIN_11
#define Rotary8_GPIO_Port GPIOC
#define Rotary1_Pin GPIO_PIN_12
#define Rotary1_GPIO_Port GPIOC
#define DRV1_PH_Pin GPIO_PIN_2
#define DRV1_PH_GPIO_Port GPIOD
#define Encoder2_A_Pin GPIO_PIN_4
#define Encoder2_A_GPIO_Port GPIOB
#define Encoder2_B_Pin GPIO_PIN_5
#define Encoder2_B_GPIO_Port GPIOB
#define DRV1_EN_Pin GPIO_PIN_6
#define DRV1_EN_GPIO_Port GPIOB
#define DRV2_EN_Pin GPIO_PIN_7
#define DRV2_EN_GPIO_Port GPIOB

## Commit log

2021-09-07 Excel の追加
    [battery.xlsx, motor.xlsx]
2021-09-15 Excel を編集
    [battery.xlsx, gear.xlsx, motor.xlsx]
2021-09-21 Odakun Version
    [gear.xlsx]
2021-09-21 DCX の CAD データの追加
    [gear.xlsx, maxon DCX 10 L.iam]
2021-09-22 タイヤのアセンブリを作成中
    [Tire.0001.ipt, Tire.iam, Tire.ipt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]
2021-09-24 excel データの修正
    [gear.xlsx]
2021-09-25 タイヤ一つ分完成
    [FL674ZZ.ipt, FL674ZZ.stp, Motor.iam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]
2021-10-02 Excel のギアシートに伝達効率を考慮した Version4 を追加した。
    [RobTrace_Wheel.ipt, RoboTrace01.ipt, RoboTrace02.ipt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]
2021-10-06 CFRP 土台の作成中
    [0.0002.ipt, 0.ipt, 0_1.0002.ipt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]
2021-10-12 天板を追加。あとはセンサバーをつければヨシッ！
    [0.0002.ipt, 0.0003.ipt, 0.ipt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]
2021-10-12 センサバーどうしよう...
    [Overview.0011.iam, Overview.0012.iam, Overview.iam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]
2021-10-13 センサバーの試行錯誤
    [Overview.0012.iam, Overview.0015.iam, Overview.iam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]
2021-10-17 センサ基板形状の決定
    [Motor.0014.iam, Motor.0018.iam, Motor.iam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]
2021-10-25 点検してもらった。正直天板そんなに広くとる必要ないし、センサバーも二階から引き延ばさずに一階とつなげれば良いのでは？
    [0.0003.ipt, 0.0004.ipt, 0.ipt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]
2021-11-12 回路図フォルダを作成。
    [murakumo.kicad_pcb, murakumo.sch]
2021-11-24 レギュレータ選定の Excel を追加。
    [regulator.xlsx]
2021-12-27 サイドセンサを角度可変にした
    [0_1_MIR3.0001.ipt, 0_1_MIR3.ipt, 0_2_MIR3.0001.ipt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]
2022-01-16 なぜかファイルが開けなくなったので作り直す。（元々そんなに進んでなかったし...）
    [murakumo.kicad_pcb, murakumo.sch]
2022-01-27 機体全体的に無駄な部分を減らした。
    [Motor.0022.iam, Motor.0032.iam, Motor.iam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]
2022-01-27 オシレータ増やした。モータドライバの信号を CPU で読めるようにした。nRST にプルアップ抵抗を接続。まだ CPU の正しいピンに正しい線をつなげることができていない。
    [MurakumoFrontSens.sch, MurakumoPower.sch, MurakumoSubSens.sch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]
2022-01-28 次はフットプリントの関連付け
    [MurakumoFrontSens.sch, MurakumoPower.sch, MurakumoSubSens.sch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]
2022-01-29 あとちょっとでフットプリントの関連付けが終わる
    [MurakumoFrontSens.sch, MurakumoPower.sch, MurakumoSubSens.sch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]
2022-01-30 回路図とフットプリントの関連付けが終わった
    [MurakumoPower.sch, MurakumoSubSens.sch, main.sch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]
2022-01-30 基板毎の回路図を別のプログラムとして開けるようにした
    [FrontSensor.kicad_pcb, FrontSensor.sch, Main.kicad_pcb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]
2022-01-30 センサーバーの改良
    [Motor.0032.iam, Motor.0033.iam, Motor.iam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]
2022-01-30 サイドセンサの改良とセンサーバーマウンタの厚みを減らした
    [Overview.0045.iam, Overview.0049.iam, Overview.iam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]
2022-01-30 dxf ファイルの追加
    [FrontSensor.dxf, Main.dxf, Motor.0036.iam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]
2022-01-31 サイドセンサのパターンは完成。メイン基板のフットプリント配置は完了。
    [FrontSensor.kicad_pcb, FrontSensor.sch, Main.kicad_pcb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]
2022-01-31 dxf ファイルのリビジョン
    [FrontSensor.dxf, Main.dxf, Power.dxf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]
2022-01-31 150x50 のセンサーバーにした
    [FrontSensor.dxf, Motor.0038.iam, Motor.0039.iam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]
2022-01-31 パーツ配置まではとりあえず終わらせた。後は配線すればいい。
    [Main.kicad_pcb, Main.sch, Power.kicad_pcb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]
2022-01-31 重心位置を考慮
    [0.0004.ipt, 0.0006.ipt, 0.ipt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]
2022-01-31 power 基板の肉抜きを無くした
    [Overview.0059.iam, Overview.0060.iam, Overview.iam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]
2022-02-03 とりあえず完成
    [Main.kicad_pcb, Power.kicad_pcb, Power.sch]
2022-02-04 あとはシルクを見やすい位置にもっていくだけ。
    [FrontSensor.kicad_pcb, FrontSensor.kicad_sch, FrontSensor.sch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]
2022-02-04 これから gerber ファイルを吐き出して先輩たちに見てもらう
    [Main.kicad_pcb, Power.kicad_pcb]
2022-02-04 Gerber データを出力した。これから先輩に添削してもらう。
    [FrontSensor-B_Cu.gbr, FrontSensor-B_Mask.gbr, FrontSensor-B_Paste.gbr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]
2022-02-04 シルクの調整
    [FrontSensor-B_Cu.gbr, FrontSensor-B_Mask.gbr, FrontSensor-B_Paste.gbr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]
2022-02-04 ファイル名の変更。シルクの調整。
    [FrontSensor-B_Cu.gbr, FrontSensor-B_Mask.gbr, FrontSensor-B_Paste.gbr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]
2022-02-05 フットプリントの問題は解消
    [FrontSensor-B_Cu.gbr, FrontSensor-B_Mask.gbr, FrontSensor-B_Paste.gbr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]
2022-02-05 後はガーバデータ出してロゴ刺すだけ
    [Main.kicad_pcb, Power.kicad_pcb, SubSensor.kicad_pcb]
2022-02-17 ホイールの改善とシャフトの編集
    [0_1_MIR2.0002.ipt, 0_1_MIR2.ipt, 0_1_MIR2_MIR.ipt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]
2022-03-02 タイヤをギアと一体化させた
    [Main.sch, Motor.0050.iam, Motor.0056.iam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]
2022-03-09 cube_v2 _v3 を消した
2022-03-11 でーきーなーいー
    [Main.kicad_pcb]
2022-03-11 Update 機能を ADC に絞ったプログラム.c
2022-03-11 取り消す前
2022-03-16 感光基板で作れるフロントセンサを作成中
    [FrontSensor.kicad_pcb, FrontSensor.sch, Main.kicad_pcb]
2022-03-29 P 制御するプログラムを実装（まだ実機で実験してないけど...
    [Main.sch]
2022-03-31 Excel ファイルの追加 センサ値を CSV で吐けるようにした
    [20220330sensorblack01.csv, 20220330sensorwhite01.csv]
2022-04-08 センサの位置を計算して出してくれる Excel を作った。
    [センサの座標と回転角の計算表.xlsx]
2022-04-10 式の修正
2022-04-12 はしるよ
2022-04-13 Wheel_v4 add
    [Motor.0056.iam, Motor.0057.iam, Motor.iam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]
2022-04-28 さらにテスト
2022-04-28 さらにさらにテスト
2022-05-05 サイドセンサのプログラムの吟味
2022-05-19 一旦保存、何かあったらここに戻れ
2022-05-23 サイドセンサだけのプログラムを実行できるようにプリプロセッサを登録した。
2022-06-26 Encoder Rotary Switch
2022-06-27 analog の処理のあたりを改善
2022-06-28 ロータリスイッチを使ってモード変更のプログラムの書き途中
2022-06-30 ロータリスイッチのプログラムを実装する。何か問題が起きたらここに戻れ
2022-06-30 オペ完了
2022-06-30 ロータリスイッチを実装した状態で元の状態と同じ状態に戻れた
2022-07-01 Flash のプログラムを書こうと思ったけどやめた
2022-07-20 IMU のデータを取得できた！
2022-07-22 減速比を考え直して設計しなおした
    [FL674ZZ.0007.ipt, FL674ZZ.0008.ipt, FL674ZZ.ipt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]
2022-07-26 UART が使えなくなったぞ？？？
    [cource.csv, cource.xlsx, gear.xlsx]
2022-08-05 FPU を有効化した
2022-08-05 ノムさんが9号館にいてくれたから...
2022-08-08 ライントレースしながらちゃんと目標速度が出せるようになった！
    [gear.xlsx]
2022-08-08 交差でぶれないようにした。
2022-09-08 何かあったらここに戻れ
    [CubeMX Clock_Calc.xlsx, バッテリ決め.xlsx]
2022-09-08 PlayMode 追加、また、ゲイン値の与え方を修正、14 通りでゲインを試せるようにした。
2022-09-18 PID ゲインチューニング中
2022-09-18 大型アップデート前、戻るならここ。
2022-09-26 ボディファイルの可読化
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2022-10-10 何が変わった？？？
    [MotorBracket_v6.0004.ipt, MotorBracket_v6.0010.ipt, MotorBracket_v6.1.ipt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]
2022-10-10 細かいところちょっとだけ修正した

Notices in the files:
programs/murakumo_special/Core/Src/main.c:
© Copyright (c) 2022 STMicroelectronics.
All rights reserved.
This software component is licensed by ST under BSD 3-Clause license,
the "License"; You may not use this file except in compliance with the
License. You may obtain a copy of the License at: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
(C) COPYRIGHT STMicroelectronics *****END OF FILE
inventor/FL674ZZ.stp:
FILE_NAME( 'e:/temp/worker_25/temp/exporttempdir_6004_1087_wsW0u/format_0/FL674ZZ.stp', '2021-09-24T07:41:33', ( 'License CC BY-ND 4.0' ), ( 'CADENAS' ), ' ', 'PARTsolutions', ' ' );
